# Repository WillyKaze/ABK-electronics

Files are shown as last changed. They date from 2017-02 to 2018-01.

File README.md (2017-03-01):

```
____ ___  _  _    ____ _    ____ ____ ___ ____ ____ _  _ _ ____ ____ 
|__| |__] |_/  __ |___ |    |___ |     |  |__/ |  | |\ | | |    [__  
|  | |__] | \_    |___ |___ |___ |___  |  |  \ |__| | \| | |___ ___] 
                                                                      
```

# Abrakabuki electronics

This repo contains all necessary files to design and produce PCBs for the Abrakabuki product range.

## File format and folder structure

Documentation files should be in PDF. Board image files can be in PNG or PDF.

PCB Design file are in EAGLE Standard edition (7.4) file format.

These are general rules to help maintain a consistent folder structure:

* All libraries are placed inside the shared libraries repository. It can be found
  on [Github](https://github.com/exmchina-dev/eagle-resources)  

* One board for each project folder.  

* Mutiples revisions can be placed inside a subfolder. i.e. ECS-Board/Rev A1  

* BOMs, partlists, spreadsheet should placed inside a BOMs/ folder.  

* Documentations files are in eagle-resources/doc or in doc/ inside a project folder.

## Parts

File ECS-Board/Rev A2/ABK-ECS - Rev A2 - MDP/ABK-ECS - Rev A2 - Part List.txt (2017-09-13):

Partlist

Exported from ABK-ECS - Rev A2.brd at 2017-09-08 3:27 PM

EAGLE Version 7.7.0 Copyright (c) 1988-2016 CadSoft

Assembly variant: 

Part     Value            Package             Library                                      Position (mm)         Orientation

C1       10uF             CT3216              rcl                                          (43.485 32.893)       MR0
C2       0.1uF            C0603               rcl                                          (47.422 30.861)       MR90
C3       0.1uF            C0603               rcl                                          (48.565 17.78)        R0
C4       0.1uF            C0603               rcl                                          (38.405 8.89)         MR0
C5       18pF             C0603               rcl                                          (41.58 17.78)         R270
C6       0.1uF            C0603               rcl                                          (39.7385 34.163)      MR270
C7       0.1uF            C0603               rcl                                          (46.533 37.592)       MR0
C8       0.1uF            C0603               rcl                                          (47.549 34.925)       MR270
C9       0.1uF            C0603               rcl                                          (39.802 37.338)       MR0
C10      18pF             C0603               rcl                                          (44.12 17.78)         R270
C11      0.1uF            C0603               rcl                                          (39.8655 29.464)      MR270
C12      2.2uF            C0603               rcl                                          (80.061 26.67)        R180
C13      2.2uF            C0603               rcl                                          (79.9975 8.89)        R180
C14      1000pF           C0603               rcl                                          (86.665 26.035)       R0
C15      1000pF           C0603               rcl                                          (86.665 7.62)         R0
C16      2.2uF            C0603               rcl                                          (79.299 39.37)        R180
C17      2.2uF            C0603               rcl                                          (79.172 21.082)       R180
C18      22uF             C0805               rcl                                          (77.775 29.21)        R0
C19      22uF             C0805               rcl                                          (77.775 11.43)        R0
C20      1u               C0603               rcl                                          (15.8875 12.3825)     R180
C21      1u               C0603               rcl                                          (11.4425 12.3825)     R0
C22      0.1uF            C0603               rcl                                          (91.745 53.34)        R0
C23      0.1uF            C0603               rcl                                          (18.745 50.8)         MR270
C24      0.1uF            C0603               rcl                                          (37.16 50.8)          MR270
D1       MBRS140          DO-214AA            diode                                        (78.41 36.195)        R0
D2       MBRS140          DO-214AA            diode                                        (78.41 17.78)         R0
D3       STPS3L40UF       SMB                 diode                                        (91.11 15.24)         R0
D4       STPS3L40UF       SMB                 diode                                        (9.525 23.495)        MR0
D5       STPS3L40UF       SMB                 diode                                        (88.9 68.5925)        MR270
D6       1N4148WS         SOD323-W            diode                                        (44.755 69.85)        MR270
D7       1N4148WS         SOD323-W            diode                                        (67.615 69.85)        MR270
D8       1N4148WS         SOD323-W            diode                                        (71.425 69.85)        MR270
D9       1N4148WS         SOD323-W            diode                                        (75.235 69.85)        MR270
D10      1N4148WS         SOD323-W            diode                                        (79.045 69.85)        MR270
D11      1N4148WS         SOD323-W            diode                                        (48.565 69.85)        MR270
D12      1N4148WS         SOD323-W            diode                                        (52.375 69.85)        MR270
D13      1N4148WS         SOD323-W            diode                                        (56.185 69.85)        MR270
D14      1N4148WS         SOD323-W            diode                                        (59.995 69.85)        MR270
F1       1812L110/24DR    LITTLEFUSE_SMD      fuse2                                        (91.745 25.4)         R270
J1       22-27-2061-06    6410-06             con-molex                                    (10.465 18.415)       R0
J2       USB-B-S-RA       USB-B-S-RA          con-multicomp                                (60.63 4.445)         R0
J3       1241050-5        2.54/2X5            con-amp                                      (25.705 9.525)        R0
J4       MSTBA2           MSTBA2              con-phoenix-508                              (98.095 40)           R90
J5       22-05-7068-06    7395-06             con-molex                                    (33.02 74.93)         R180
J6       22-05-7028-02    7395-02             con-molex                                    (88.9 74.93)          R180
J7       22-05-7068-06    7395-06             con-molex                                    (16.51 74.93)         R180
J8       22-05-7068-06    7395-06             con-molex                                    (76.2 74.93)          R180
J9       22-05-7028-02    7395-02             con-molex                                    (45.72 74.93)         R180
J10      22-05-7068-06    7395-06             con-molex                                    (58.42 74.93)         R180
JP1      FIDUCIAL1X2      FIDUCIAL-1X2        SparkFun                                     (92 8)                R90
JP2      FIDUCIAL1X2      FIDUCIAL-1X2        SparkFun                                     (8 8)                 R90
JP3      FIDUCIAL1X2      FIDUCIAL-1X2        SparkFun                                     (8 71.365)            R90
JP4      FIDUCIAL1X2      FIDUCIAL-1X2        SparkFun                                     (92 72)               R90
K1       G6K-2G-Y         G6K-2G-Y            relay                                        (88.57 62.23)         R270
L1       15uH             WE-PD2_5848/5820    Wurth-POWER_MAGNETICS-rev16f                 (72.06 31.115)        R270
L2       10uH             WE-PD2_5848/5820    Wurth-POWER_MAGNETICS-rev16f                 (72.06 13.0175)       R270
LED1     Blue             CHIPLED_0603        led                                          (50.47 7.62)          R180
LED2     Blue             CHIPLED_0603        led                                          (47.93 7.62)          R180
LED3     Red              CHIPLED_0603        led                                          (88.57 36.83)         R90
LED4     Blue             CHIPLED_0603        led                                          (88.57 39.6875)       R270
LED5     Blue             CHIPLED_0603        led                                          (76.378 25.7175)      R0
LED6     Blue             CHIPLED_0603        led                                          (76.378 8.128)        R0
LED7     Red              CHIPLED_0603        led                                          (93.65 55.245)        R270
LED8     Blue             CHIPLED_0603        led                                          (45.085 56.5275)      R90
LED9     Blue             CHIPLED_0603        led                                          (39.04 52.705)        R180
LED10    Blue             CHIPLED_0603        led                                          (37.135 52.705)       R180
LED11    Blue             CHIPLED_0603        led                                          (24.435 52.705)       R180
LED12    Blue             CHIPLED_0603        led                                          (22.53 52.705)        R180
LED13    Blue             CHIPLED_0603        led                                          (20.625 52.705)       R180
LED14    Blue             CHIPLED_0603        led                                          (18.72 52.705)        R180
LED15    Blue             CHIPLED_0603        led                                          (6.02 52.705)         R180
LED16    Blue             CHIPLED_0603        led                                          (4.1275 52.705)       R180
LED17    Blue             CHIPLED_0603        led                                          (80.315 50.165)       R180
LED18    Blue             CHIPLED_0603        led                                          (82.855 50.165)       R180
LED19    Blue             CHIPLED_0603        led                                          (85.395 50.165)       R180
LED20    Blue             CHIPLED_0603        led                                          (87.935 50.165)       R180
LED21    Blue             CHIPLED_0603        led                                          (45.0725 54.61)       R90
LED22    Blue             CHIPLED_0603        led                                          (45.0725 52.705)      R90
LED23    Blue             CHIPLED_0603        led                                          (45.0725 50.8)        R90
LED24    Blue             CHIPLED_0603        led                                          (45.0725 48.895)      R90
MP1      MOUNT-PAD3,0     P3,0                holes                                        (96 4)                R90
MP2      MOUNT-PAD3,0     P3,0                holes                                        (4 4)                 R90
MP3      MOUNT-PAD3,0     P3,0                holes                                        (4 76)                R90
MP4      MOUNT-PAD3,0     P3,0                holes                                        (96 76)               R90
OK1      TLP283-4         MINI-FLAT-16        optocoupler                                  (30.785 64.135)       R270
OK2      TLP283-4         MINI-FLAT-16        optocoupler                                  (14.275 64.135)       R270
OK3      TLP283-4         MINI-FLAT-16        optocoupler                                  (73.965 48.895)       R90
OK4      TLP283-4         MINI-FLAT-16        optocoupler                                  (56.185 48.895)       R90
R1       4K7              R0603               rcl                                          (39.37 11.7475)       R270
R2       4K7              R0603               rcl                                          (37.465 11.735)       R90
R3       4K7              R0603               rcl                                          (46.025 12.065)       R0
R4       4K7              R0603               rcl                                          (42.215 12.065)       R180
R5       0R               R0603               rcl                                          (20.32 32.385)        R270
R6       33               R0603               rcl                                          (60.63 14.605)        R90
R7       33               R0603               rcl                                          (58.344 14.605)       R90
R8       1K5              R0603               rcl                                          (63.805 13.6525)      R180
R9       1K5              R0603               rcl                                          (55.55 13.589)        R0
R10      10K              R0603               rcl                                          (16.815 41.91)        R0
R11      0R               R0603               rcl                                          (16.18 38.735)        R90
R12      0R               R0603               rcl                                          (18.72 38.735)        R90
R13      10K              R0603               rcl                                          (16.815 32.385)       R270
R14      1K5              R0603               rcl                                          (52.0825 7.62)        R90
R15      1K5              R0603               rcl                                          (46.3675 7.62)        R90
R16      31K6             R0603               rcl                                          (86.665 29.21)        R180
R17      31K6             R0603               rcl                                          (86.665 10.795)       R180
R18      4K7              R0603               rcl                                          (85.395 36.83)        R180
R19      4K7              R0603               rcl                                          (85.395 39.6875)      R180
R20      52K3             R0603               rcl                                          (82.855 23.495)       R180
R21      10K              R0603               rcl                                          (86.665 23.495)       R180
R22      31K6             R0603               rcl                                          (82.728 5.08)         R180
R23      10K              R0603               rcl                                          (86.665 5.08)         R180
R24      1K5              R0603               rcl                                          (78.537 24.003)       R0
R25      1K5              R0603               rcl                                          (78.6005 5.7785)      R0
R26      100              R0603               rcl                                          (88.57 68.58)         R180
R27      1K               R0603               rcl                                          (35.23 70.485)        R270
R28      1K               R0603               rcl                                          (32.69 70.485)        R270
R29      1K               R0603               rcl                                          (30.15 70.485)        R270
R30      1K               R0603               rcl                                          (27.61 70.485)        R270
R31      1K               R0603               rcl                                          (35.865 57.15)        R270
R32      1K               R0603               rcl                                          (32.055 57.15)        R270
R33      1K               R0603               rcl                                          (28.245 57.15)        R270
R34      1K               R0603               rcl                                          (24.435 57.15)        R270
R35      4K7              R0603               rcl                                          (33.96 57.15)         R90
R36      4K7              R0603               rcl                                          (30.15 57.15)         R90
R37      4K7              R0603               rcl                                          (26.34 57.15)         R90
R38      4K7              R0603               rcl                                          (22.53 57.15)         R90
R39      4K7              R0603               rcl                                          (94.92 52.07)         R90
R40      100              R0603               rcl                                          (91.745 50.8)         R180
R41      1K5              R0603               rcl                                          (90.475 55.245)       R180
R42      1K               R0603               rcl                                          (18.72 70.485)        R270
R43      1K               R0603               rcl                                          (16.18 70.485)        R270
R44      1K               R0603               rcl                                          (13.64 70.485)        R270
R45      1K               R0603               rcl                                          (11.1125 70.485)      R270
R46      1K               R0603               rcl                                          (19.355 57.15)        R270
R47      1K               R0603               rcl                                          (15.545 57.15)        R270
R48      1K               R0603               rcl                                          (11.735 57.15)        R270
R49      1K               R0603               rcl                                          (7.9375 57.15)        R270
R50      4K7              R0603               rcl                                          (17.45 57.15)         R90
R51      4K7              R0603               rcl                                          (13.64 57.15)         R90
R52      4K7              R0603               rcl                                          (9.83 57.15)          R90
R53      4K7              R0603               rcl                                          (6.0325 57.15)        R90
R54      1K5              R0603               rcl                                          (41.91 56.5275)       R180
R55      1K5              R0603               rcl                                          (39.04 49.53)         R270
R56      1K5              R0603               rcl                                          (37.135 49.53)        R270
R57      1K5              R0603               rcl                                          (24.435 49.53)        R270
R58      1K5              R0603               rcl                                          (22.53 49.53)         R270
R59      1K5              R0603               rcl                                          (20.625 49.53)        R270
R60      1K5              R0603               rcl                                          (18.72 49.53)         R270
R61      1K5              R0603               rcl                                          (6.02 49.53)          R270
R62      1K5              R0603               rcl                                          (4.1275 49.53)        R270
R63      10K              R0603               rcl                                          (46.66 70.485)        MR90
R64      330              R0603               rcl                                          (43.51 66.04)         R0
R65      100              R0603               rcl                                          (44.45 59.0675)       R270
R66      10K              R0603               rcl                                          (69.52 70.485)        MR90
R67      10K              R0603               rcl                                          (73.33 70.485)        MR90
R68      10K              R0603               rcl                                          (77.14 70.485)        MR90
R69      10K              R0603               rcl                                          (80.95 70.485)        MR90
R70      330              R0603               rcl                                          (67.9325 66.04)       R0
R71      330              R0603               rcl                                          (72.3775 66.04)       R0
R72      330              R0603               rcl                                          (76.8225 66.04)       R0
R73      330              R0603               rcl                                          (81.2675 66.04)       R0
R74      100              R0603               rcl                                          (69.52 59.055)        R90
R75      100              R0603               rcl                                          (74.2825 59.055)      R90
R76      100              R0603               rcl                                          (78.7275 59.055)      R90
R77      100              R0603               rcl                                          (82.855 59.055)       R90
R78      1K5              R0603               rcl                                          (80.315 46.99)        R270
R79      1K5              R0603               rcl                                          (82.855 46.99)        R270
R80      1K5              R0603               rcl                                          (85.395 46.99)        R270
R81      1K5              R0603               rcl                                          (87.935 46.99)        R270
R82      4K7              R0603               rcl                                          (67.615 59.055)       R90
R83      4K7              R0603               rcl                                          (72.3775 59.055)      R90
R84      4K7              R0603               rcl                                          (76.8225 59.055)      R90
R85      4K7              R0603               rcl                                          (80.95 59.055)        R90
R86      1K               R0603               rcl                                          (67.615 55.245)       R270
R87      1K               R0603               rcl                                          (72.3775 55.245)      R270
R88      1K               R0603               rcl                                          (76.8225 55.245)      R270
R89      1K               R0603               rcl                                          (80.95 55.245)        R270
R90      330              R0603               rcl                                          (63.4875 39.37)       R270
R91      330              R0603               rcl                                          (65.71 39.37)         R270
R92      330              R0603               rcl                                          (67.9325 39.37)       R270
R93      330              R0603               rcl                                          (70.155 39.37)        R270
R94      10K              R0603               rcl                                          (50.47 70.485)        MR90
R95      10K              R0603               rcl                                          (54.28 70.485)        MR90
R96      10K              R0603               rcl                                          (58.09 70.485)        MR90
R97      10K              R0603               rcl                                          (61.9 70.485)         MR90
R98      330              R0603               rcl                                          (47.93 66.04)         R0
R99      330              R0603               rcl                                          (52.375 66.04)        R0
R100     330              R0603               rcl                                          (56.82 66.04)         R0
R101     330              R0603               rcl                                          (61.265 66.04)        R0
R102     100              R0603               rcl                                          (48.9075 59.055)      R90
R103     100              R0603               rcl                                          (53.3525 59.055)      R90
R104     100              R0603               rcl                                          (57.7975 59.055)      R90
R105     100              R0603               rcl                                          (62.2425 59.055)      R90
R106     1K5              R0603               rcl                                          (41.8975 54.61)       R180
R107     1K5              R0603               rcl                                          (41.8975 52.705)      R180
R108     1K5              R0603               rcl                                          (41.8975 50.8)        R180
R109     1K5              R0603               rcl                                          (41.8975 48.895)      R180
R110     4K7              R0603               rcl                                          (47.0025 59.055)      R90
R111     4K7              R0603               rcl                                          (51.4475 59.055)      R90
R112     4K7              R0603               rcl                                          (55.8925 59.055)      R90
R113     4K7              R0603               rcl                                          (60.3375 59.055)      R90
R114     1K               R0603               rcl                                          (53.01 55.245)        R270
R115     1K               R0603               rcl                                          (55.55 55.245)        R270
R116     1K               R0603               rcl                                          (58.09 55.245)        R270
R117     1K               R0603               rcl                                          (60.63 55.245)        R270
R118     330              R0603               rcl                                          (54.5975 39.37)       R270
R119     330              R0603               rcl                                          (56.82 39.37)         R270
R120     330              R0603               rcl                                          (59.0425 39.37)       R270
R121     330              R0603               rcl                                          (61.265 39.37)        R270
SJ1      SOLDERJUMPERNC   SJ_2S               SparkFun-Passives                            (60.63 4.445)         MR90
SJ2      SOLDERJUMPERNC   SJ_2S               SparkFun-Passives                            (96 10)               R270
SJ3      SOLDERJUMPERNC   SJ_2S               SparkFun-Passives                            (4 10)                R270
SJ4      SOLDERJUMPERNC   SJ_2S               SparkFun-Passives                            (4 69.365)            R90
SJ5      SOLDERJUMPERNC   SJ_2S               SparkFun-Passives                            (95.999 70.081)       R90
SW1      B3FS-1015        B3FS                Switch_SMT                                   (9.52 40.155)         R0
SW2      B3FS-1015        B3FS                Switch_SMT                                   (9.52 30.955)         R0
T2       IRLML5103TRPBF   SOT95P240X112-3N    International_Rectifier_By_element14_Batch_1 (43.485 69.215)       R90
T3       MMBT2222AL       SOT?23              transistor                                   (43.4975 63.4875)     R270
T4       IRLML5103TRPBF   SOT95P240X112-3N    International_Rectifier_By_element14_Batch_1 (68.25 69.215)        R90
T5       IRLML5103TRPBF   SOT95P240X112-3N    International_Rectifier_By_element14_Batch_1 (72.695 69.215)       R90
T6       IRLML5103TRPBF   SOT95P240X112-3N    International_Rectifier_By_element14_Batch_1 (77.14 69.215)        R90
T7       IRLML5103TRPBF   SOT95P240X112-3N    International_Rectifier_By_element14_Batch_1 (81.585 69.215)       R90
T8       MMBT2222AL       SOT?23              transistor                                   (68.25 63.5)          R270
T9       MMBT2222AL       SOT?23              transistor                                   (72.695 63.5)         R270
T10      MMBT2222AL       SOT?23              transistor                                   (77.14 63.5)          R270
T11      MMBT2222AL       SOT?23              transistor                                   (81.585 63.5)         R270
T12      IRLML5103TRPBF   SOT95P240X112-3N    International_Rectifier_By_element14_Batch_1 (47.93 69.215)        R90
T13      IRLML5103TRPBF   SOT95P240X112-3N    International_Rectifier_By_element14_Batch_1 (52.375 69.215)       R90
T14      IRLML5103TRPBF   SOT95P240X112-3N    International_Rectifier_By_element14_Batch_1 (56.82 69.215)        R90
T15      IRLML5103TRPBF   SOT95P240X112-3N    International_Rectifier_By_element14_Batch_1 (61.265 69.215)       R90
T16      MMBT2222AL       SOT?23              transistor                                   (47.93 63.5)          R270
T17      MMBT2222AL       SOT?23              transistor                                   (52.375 63.5)         R270
T18      MMBT2222AL       SOT?23              transistor                                   (56.82 63.5)          R270
T19      MMBT2222AL       SOT?23              transistor                                   (61.265 63.5)         R270
U1       AT24C512C-SSHM-B SOIC127P600X175-8N  atmel                                        (38.405 6.985)        R0
U2       LPC1768FBD100    SOT407-1            NXP                                          (43.73 33.65)         R90
U3       LT3686HDDPBF     DFN300X300X80-11N   lineartechnology                             (82.855 31.115)       R90
U4       LT3686HDDPBF     DFN300X300X80-11N   lineartechnology                             (82.855 12.7)         R90
U5       TC1264-3.3       SOT230P700X180-4N   microchip-6                                  (13.64 6.985)         R270
U6       CD4050BD         SOIC127P600X175-16N ti                                           (30.7975 50.8)        R270
U7       CD4050BD         SOIC127P600X175-16N ti                                           (12.3825 50.8)        R270
X1       FC-135           FC-135              crystal                                      (42.85 20.955)        R0
X2       ASE-12           ASE                 crystal                                      (48.565 20.955)       R0
X3       3000             3000                keystone                                     (25.705 6.35)         MR180

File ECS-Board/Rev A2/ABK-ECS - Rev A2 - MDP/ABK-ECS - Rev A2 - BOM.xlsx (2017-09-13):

Qty | Designator | Value | Package | Manufacteur | Reference Manufacteur | Mounting Tecghnologie
1 | U5 | TC1264-3.3V | SOT230P700X180-4N | MICROCHIP | TC1264-3.3VDB | SMD
1 | J3 | 1241050-5 | 2.54/2X5 | AMP | 1241050-5 | Thought-Hole
1 | J4 | MSTBA2 | MSTBA2 | PHOENIX CONTACT | 1757242 | Thought-Hole
9 | D6, D7, D8, D9, D10, D11, D12, D13, D14 | 1N4148WS | SOD323-W | ON SEMICONDUCTOR | 1N4148WS | SMD
2 | J6, J9 | 22-05-7028-02 | 7395-02 | MOLEX | 22-05-7028 | Thought-Hole
4 | J5, J7, J8, J10 | 22-05-7068-06 | 7395-06 | MOLEX | 22-05-7068 | Thought-Hole
1 | J1 | 22-27-2061-06 | 6410-06 | MOLEX | 22-27-2061 | Thought-Hole
1 | X3 | 3000 | 3000 | KEYSTONE | 3000 | SMD
1 | F1 | 1812L110/24DR | LITTLEFUSE_SMD | LITTLEFUSE | 1812L110/24DR | SMD
1 | L2 | 10uH | WE-PD2_5848/5820 | WURTH ELECTRONIK | 74477410 | SMD
1 | L1 | 15uH | WE-PD2_5848/5820 | WURTH ELECTRONIK | 744774115 | SMD
1 | X2 | ASE-12 | ASE | ABRACON | ASE-12.000MHZ-LC-T | SMD
1 | U1 | AT24C512C-SSHM-B | SOIC127P600X175-8N | MICROCHIP | AT24C512C-SSHM-B | SMD
2 | SW1, SW2 | B3FS-1015 | B3FS | OMRON ELECTRONIC | B3FS-1010 | SMD
2 | C18, C19 | 22uF | C0805 | KEMET | C0805C226M9PACTU | SMD
2 | U6, U7 | CD4050BD | SOIC127P600X175-16N | TEXAS INSTRUMENT | CD4050BD | SMD
1 | C1 | 10uF | CT3216 | AVX | F931A106MAA | SMD
1 | K1 | G6K-2G-Y | G6K-2G-Y | OMRON ELECTRONIC | G6K-2G-Y 24DC | SMD
2 | C5, C10 | 18pF | C0603 | MURATA | GRM1885C1H180JA01D | SMD
2 | C20, C21 | 1u | C0603 | MURATA | GRM188R61C105KA93D | SMD
2 | C14, C15 | 1000pF | C0603 | MURATA | GRM188R71H102KA01D | SMD
4 | C12, C13, C16, C17 | 2.2uF | C0603 | MURATA | GRT188R61H225KE13D | SMD
9 | T2, T4, T5, T6, T7, T12, T13, T14, T15 | IRLML5103TRPBF | SOT95P240X112-3N | INFENEON | IRLML5103TRPBF | SMD
1 | U2 | LPC1768FBD100 | SOT407-1 | NXP | LPC1768FBD100 | SMD
2 | U3, U4 | LT3686HDDPBF | DFN300X300X80-11N | LINEAR TECHNOLOGY | LT3686HDD#PBF | SMD
2 | D1, D2 | MBRS140 | DO-214AA | ON SEMICONDUCTOR | MBRS140T3G | SMD
1 | R20 | 52K3 | R0603 | MULTICOMP | MC0063W0603152K3 | SMD
11 | C2, C3, C4, C6, C7, C8, C9, C11, C22, C23, C24 | 0.1uF | C0603 | MULTICOMP | MC0603B104K160CT | SMD
3 | R16, R17, R22 | 31K6 | R0603 | MULTICOMP | MCMR06X3162FTL | SMD
9 | T3, T8, T9, T10, T11, T16, T17, T18, T19 | MMBT2222AL | SOT-23 | ON SEMICONDUCTOR | MMBT2222ALT1G | SMD
22 | LED1, LED2, LED4, LED5, LED6, LED8, LED9, LED10, LED11, LED12, LED13, LED14, LED15, LED16, LED17, LED18, LED19, LED20, LED21, LED22, LED23, LED24 | Blue | CHIPLED_0603 | MULTICOMP | OVS-0603 | SMD
2 | LED3, LED7 | Red | CHIPLED_0603 | MULTICOMP | OVS-0603 | SMD
1 | X1 | FC-135 | FC-135 | EPSON | Q13FC13500004 | SMD
3 | R5, R11, R12 | 0R | R0603 | YAGEO | RC0603FR-070RL | SMD
11 | R10, R13, R63, R66, R67, R68, R69, R94, R95, R96, R97 | 10K | R0603 | YAGEO | RC0603FR-0710KL | SMD
2 | R21, R23 | 10K | R0603 | YAGEO | RC0603FR-0710KL | SMD
20 | R14, R15, R41, R54, R55, R56, R57, R58, R59, R60, R61, R62, R78, R79, R80, R81, R106, R107, R108, R109 | 1K5 | R0603 | YAGEO | RC0603FR-071K5L | SMD
2 | R24, R25 | 1K5 | R0603 | YAGEO | RC0603FR-071K5L | SMD
2 | R8, R9 | 1K5, DNI | R0603 | YAGEO | RC0603FR-071K5L
24 | R27, R28, R29, R30, R31, R32, R33, R34, R42, R43, R44, R45, R46, R47, R48, R49, R86, R87, R88, R89, R114, R115, R116, R117 | 1K | R0603 | YAGEO | RC0603FR-071KL | SMD
17 | R64, R70, R71, R72, R73, R90, R91, R92, R93, R98, R99, R100, R101, R118, R119, R120, R121 | 330 | R0603 | YAGEO | RC0603FR-07330RL | SMD
2 | R6, R7 | 33 | R0603 | YAGEO | RC0603FR-0733RL | SMD
1 | R1 | 4K7, DNI | R0603 | YAGEO | RC0603FR-074K7L
22 | R2, R3, R4, R18, R19, R35, R36, R37, R38, R39, R50, R51, R52, R53, R82, R83, R84, R85, R110, R111, R112, R113 | 4K7 | R0603 | YAGEO | RC0603FR-074K7L | SMD
11 | R26, R40, R65, R74, R75, R76, R77, R102, R103, R104, R105 | 100 | R0603 | YAGEO | RC0603FR-13100RL | SMD
3 | D3, D4, D5 | STPS3L40UF | SMB | STELECTRONICS | STPS3L40UF | SMD
4 | OK1, OK2, OK3, OK4 | TLP283-4 | MINI-FLAT-16 | VISHAY | TCMT4100 | SMD
1 | J2 | USB-B-S-RA | USB-B-S-RA | MULTICOMP | USB-B-S-RA | Thought-Hole

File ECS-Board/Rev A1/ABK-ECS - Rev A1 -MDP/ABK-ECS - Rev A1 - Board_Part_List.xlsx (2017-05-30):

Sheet: PdG
Project | WDY - Main Board
Board Name | MCU Board
Document | Part List
Author | AB
Date | 2017-03-20
Rev | A1

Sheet: BOM
Qty | Value | Package | Parts | Description | MPN
1 | 10uF | CT3216 | C1 | POLARIZED CAPACITOR, European symbol | F931A106MAA
4 | 2.2uF | C0603 | C13, C15, C17, C18 | CAPACITOR, European symbol | GRT188R61H225KE13D
2 | 1000pF | C0603 | C14, C16 | CAPACITOR, European symbol | MC0603B102K500CT
2 | 22uF | C0805 | C19, C20 | CAPACITOR, European symbol | MC0805X226M6R3CT
10 | 0.1uF | C0603 | C2, C3, C4, C6, C7, C8, C11, C12, C21, C22 | CAPACITOR, European symbol | MC0603B104K160CT
2 | 18pF | C0603 | C5, C10 | CAPACITOR, European symbol | MC0603N180K500CT
2 | STPS3L40UF | SMB | D1, D4 |  | STPS3L40UF
2 | MBRS140 | DO-214AA | D2, D3 | Redresseur Schottky, 40 V, 1 A, Une, DO-214AA, 2 Broche(s), 600 mV | MBRS140T3G
1 | FUSE3557L | 3557-LITTLE | F1 | Fuse | 3557
1 | 1241050-5 | 2.54/2X5 | J1 |  | 1241050-5
1 | USB-B-S-RA | USB-B-S-RA | J2 | MULTICOMP USB-B-S-RA USB Connector, USB Type B, USB 2.0, Receptacle, 4 Positions, Through Hole Mount, Right Angle | USB-B-S-RA
1 | 22-27-2061-06 | 1647397 | J3 | CONNECTOR | 22-27-2061
2 | 22-05-7068-06 | 2007161 | J4, J7 | CONNECTOR | 22-05-7068
2 | 22-05-7028-02 | 2007041 | J5, J6 | CONNECTOR | 22-05-7028
1 | G6K-2G-Y | G6K-2G-Y | K3 | Low Signal Relay | G6K-2G-Y 24DC
1 | 10uH | WE-PD2_5848/5820 | L2 | SMD Power Inductor | 74477410
1 | 15uH | WE-PD2_5848/5820 | L3 | SMD Power Inductor | 744774115
14 | Blue | CHIPLED_0603 | LED1, LED3, LED4, LED8, LED9, LED10, LED11, LED12, LED13, LED14, LED15, LED16 | LED | OVS-0603
2 | Red | CHIPLED_0603 | LED2, LED7 | LED | OVS-0608
2 | TLP283-4 | MINI-FLAT-16 | OK1, OK2 | TOSHIBA PHOTOCOUPLER GaAs IRED & PHOTO-TRANSISTOR | TCMT4100
19 | 4K7 | R0603 | R1, R2, R3, R4, R5, R18, R26, R28, R33, R34, R35, R40, R44, R46, R58, R60, R62, R64, R65 | RESISTOR, European symbol | MCMR06X4701FTL
15 | 1K5 | R0603 | R10, R13, R14, R31, R66, R67, R68, R69, R70, R71, R72, R73, R74 | RESISTOR, European symbol | MCMR06X1501FTL
2 | 33 | R0603 | R11, R12 | RESISTOR, European symbol | MCMR06X33R0FTL
12 | 100 | R0603 | R17, R25, R27, R29, R32, R36, R37, R39, R42, R43, R45, R48 | RESISTOR, European symbol | MCMR06X1000FTL
3 | 31K6 | R0603 | R19, R20, R24 | RESISTOR, European symbol | MCMR06X3162FTL
2 | 10K | R0603 | R21, R23 | RESISTOR, European symbol | MCMR06X1002FTL
1 | 52K3 | R0603 | R22 | RESISTOR, European symbol | MC0063W0603152K3
12 | 1K | R0603 | R30, R38, R41, R47, R53, R54, R55, R56, R57, R59, R61, R63 | RESISTOR, European symbol | MCMR06X1001FTL
4 | 330 | R0603 | R49, R50, R51, R52 | RESISTOR, European symbol | MCMR06X3300FTL
2 | 10K | R0603 | R6, R7 | RESISTOR, European symbol | MCMR06X1002FTL
2 | 0R | R0603 | R8, R9 | RESISTOR, European symbol | MCMR06X000 PTL
2 | B3FS-1015 | B3FS | SW1, SW2 | Surface-mounting Switches Ideal for | B3FS-1010
1 | AT24C512C-SSHM-B | SOIC127P600X175-8N | U1 | SERIAL EEPROM IC Memory Size:512Kbit,8-SOIC | AT24C02C-SSHM-B
1 | CD4050BD | SOIC127P600X175-16N | U10 | CMOS Hex Buffer/Converters | CD4050BD
1 | LPC1768FBD100 | SOT407-1 | U2 |  | LPC1768FBD100
2 | LT3686HDDPBF | DFN300X300X80-11N | U3, U4 | 37V/1.2A Step-DownRegulator in 3mm ﾗ 3mm DFN | LT3686HDD#PBF
5 | IRLML6344TRPBF | SOT95P240X112-3N | U5, U6, U7, U8, U9 | Power MOSFET | IRLML6344TRPBF
1 | FC-135 | FC-135 | X1 | 32.768kHz ｱ20ppm Crystal 12.5pF 70 kOhm -40ｰC ~ 85ｰC Surface Mount 2-SMD | Q13FC13500004
1 | ASE-12 | ASE | X2 | 3.3Vdc CMOS SMD CRYSTAL CLOCK OSCILLATOR | ASE-12.000MHZ-LC-T
1 | 3000 | 3000 | X3 |  | 3000
1 | MSTBA2 | MSTBA2 | X4 | PHOENIX | 1757242

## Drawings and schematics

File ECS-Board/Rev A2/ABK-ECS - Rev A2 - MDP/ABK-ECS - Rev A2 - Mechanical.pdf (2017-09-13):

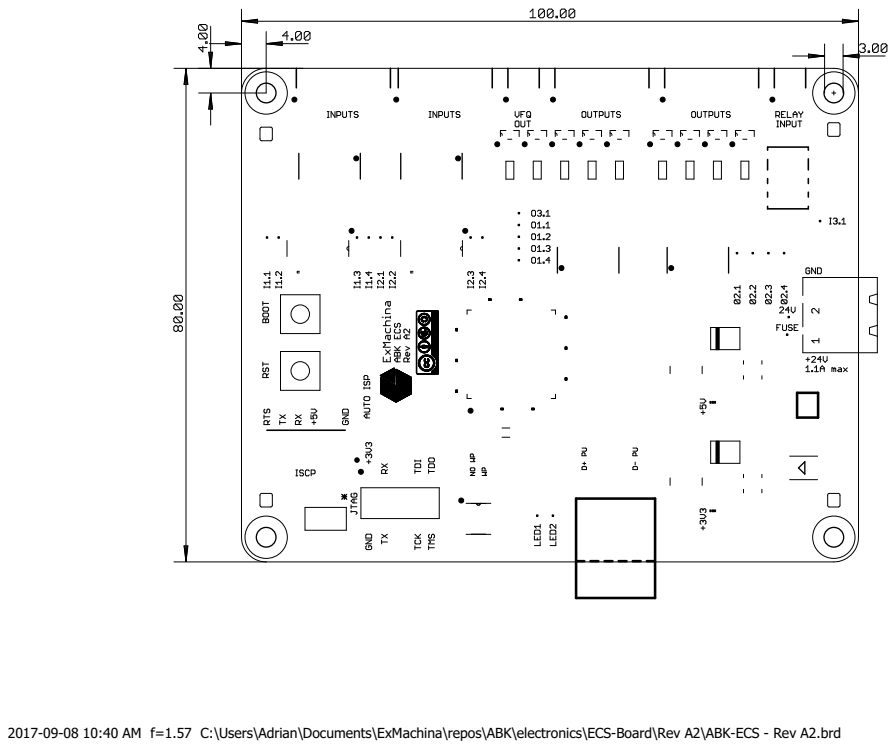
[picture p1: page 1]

2017-09-08 10:40 AM f=1.57 C:\Users\Adrian\Documents\ExMachina\repos\ABK\electronics\ECS-Board\Rev A2\ABK-ECS - Rev A2.brd

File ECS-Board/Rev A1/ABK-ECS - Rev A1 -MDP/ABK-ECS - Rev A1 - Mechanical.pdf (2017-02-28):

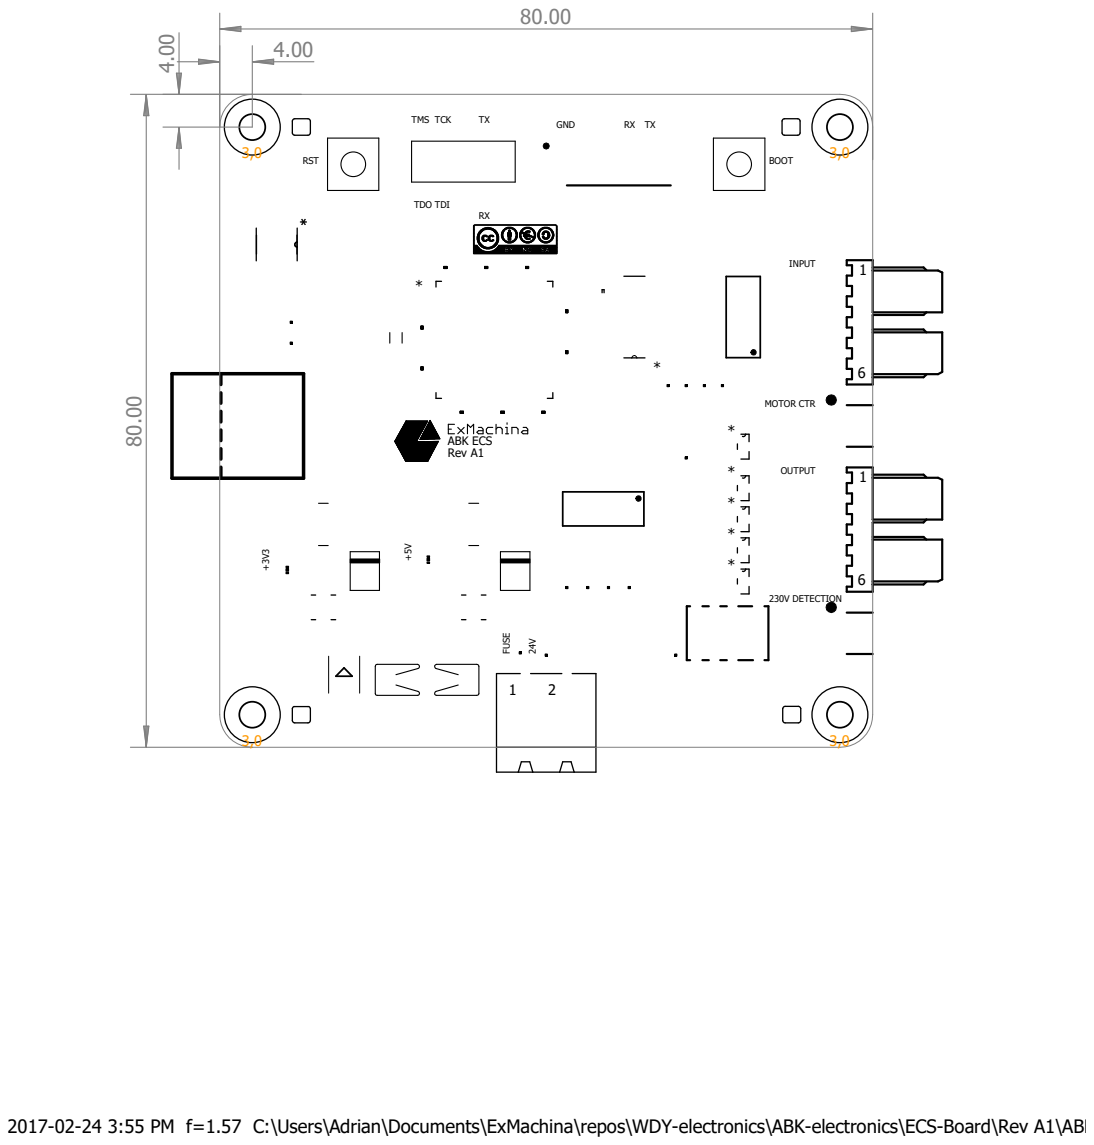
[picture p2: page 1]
ABK ECS Rev A1; TDO TDI TMS TCK; TXRX; GND; RX TX RST; BOOT MOTOR CTR; 230V DETECTION OUTPUT; INPUT FUSE

2017-02-24 3:55 PM f=1.57 C:\Users\Adrian\Documents\ExMachina\repos\WDY-electronics\ABK-electronics\ECS-Board\Rev A1\ABK-ECS - Rev A1.brd

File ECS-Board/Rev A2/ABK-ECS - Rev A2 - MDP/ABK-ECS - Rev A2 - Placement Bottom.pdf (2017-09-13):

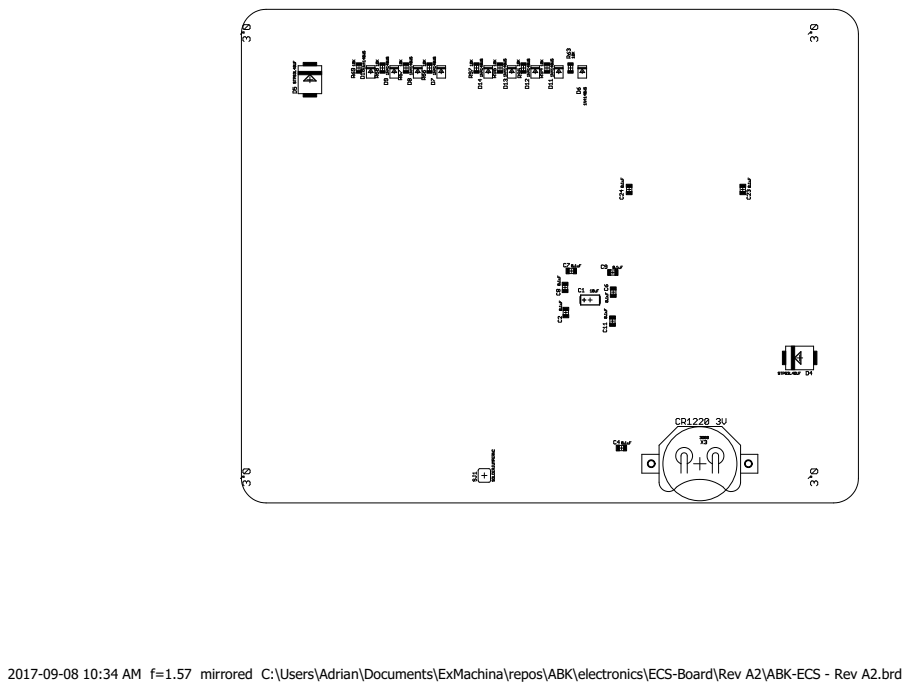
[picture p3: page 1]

2017-09-08 10:34 AM f=1.57 mirrored C:\Users\Adrian\Documents\ExMachina\repos\ABK\electronics\ECS-Board\Rev A2\ABK-ECS - Rev A2.brd

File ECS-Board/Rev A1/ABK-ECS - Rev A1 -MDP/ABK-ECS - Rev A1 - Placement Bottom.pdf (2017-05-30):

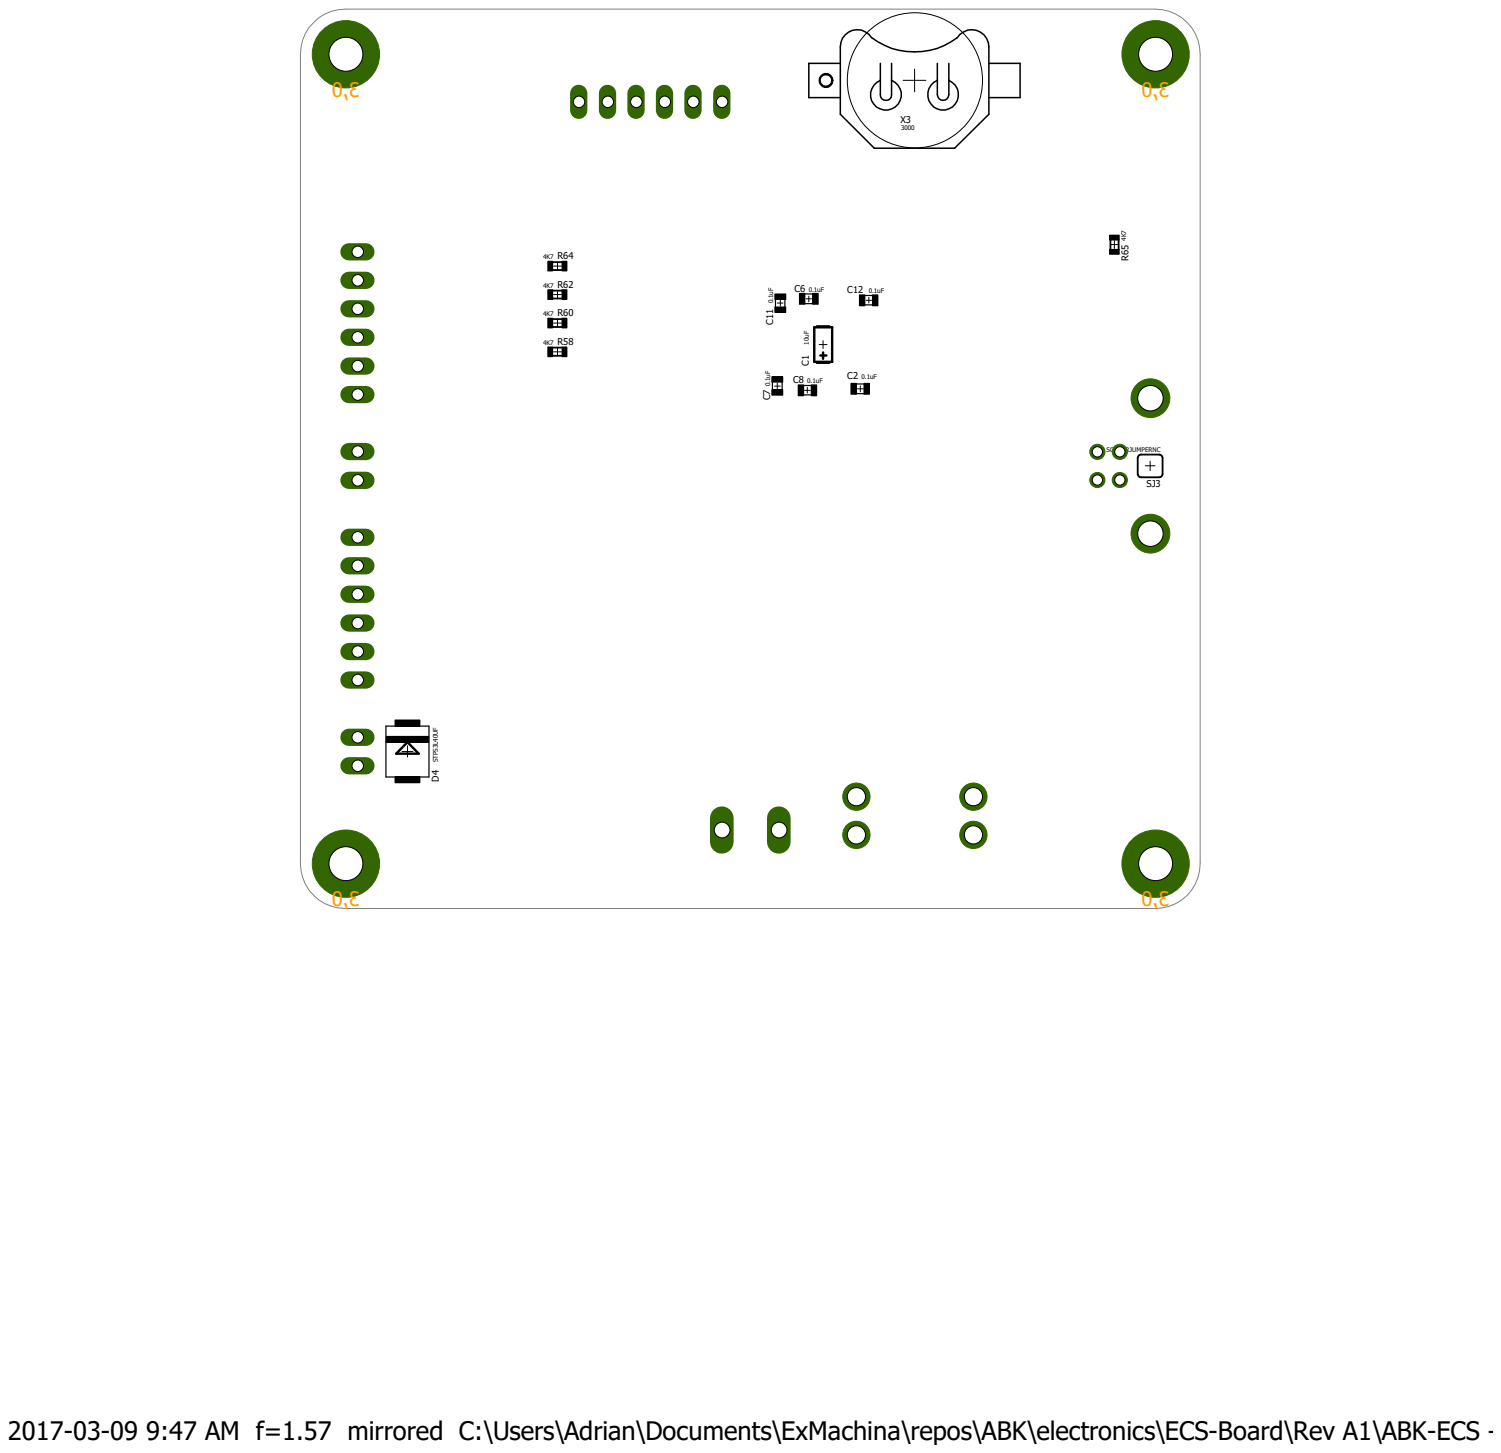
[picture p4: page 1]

2017-03-09 9:47 AM f=1.57 mirrored C:\Users\Adrian\Documents\ExMachina\repos\ABK\electronics\ECS-Board\Rev A1\ABK-ECS - Rev A1.brd

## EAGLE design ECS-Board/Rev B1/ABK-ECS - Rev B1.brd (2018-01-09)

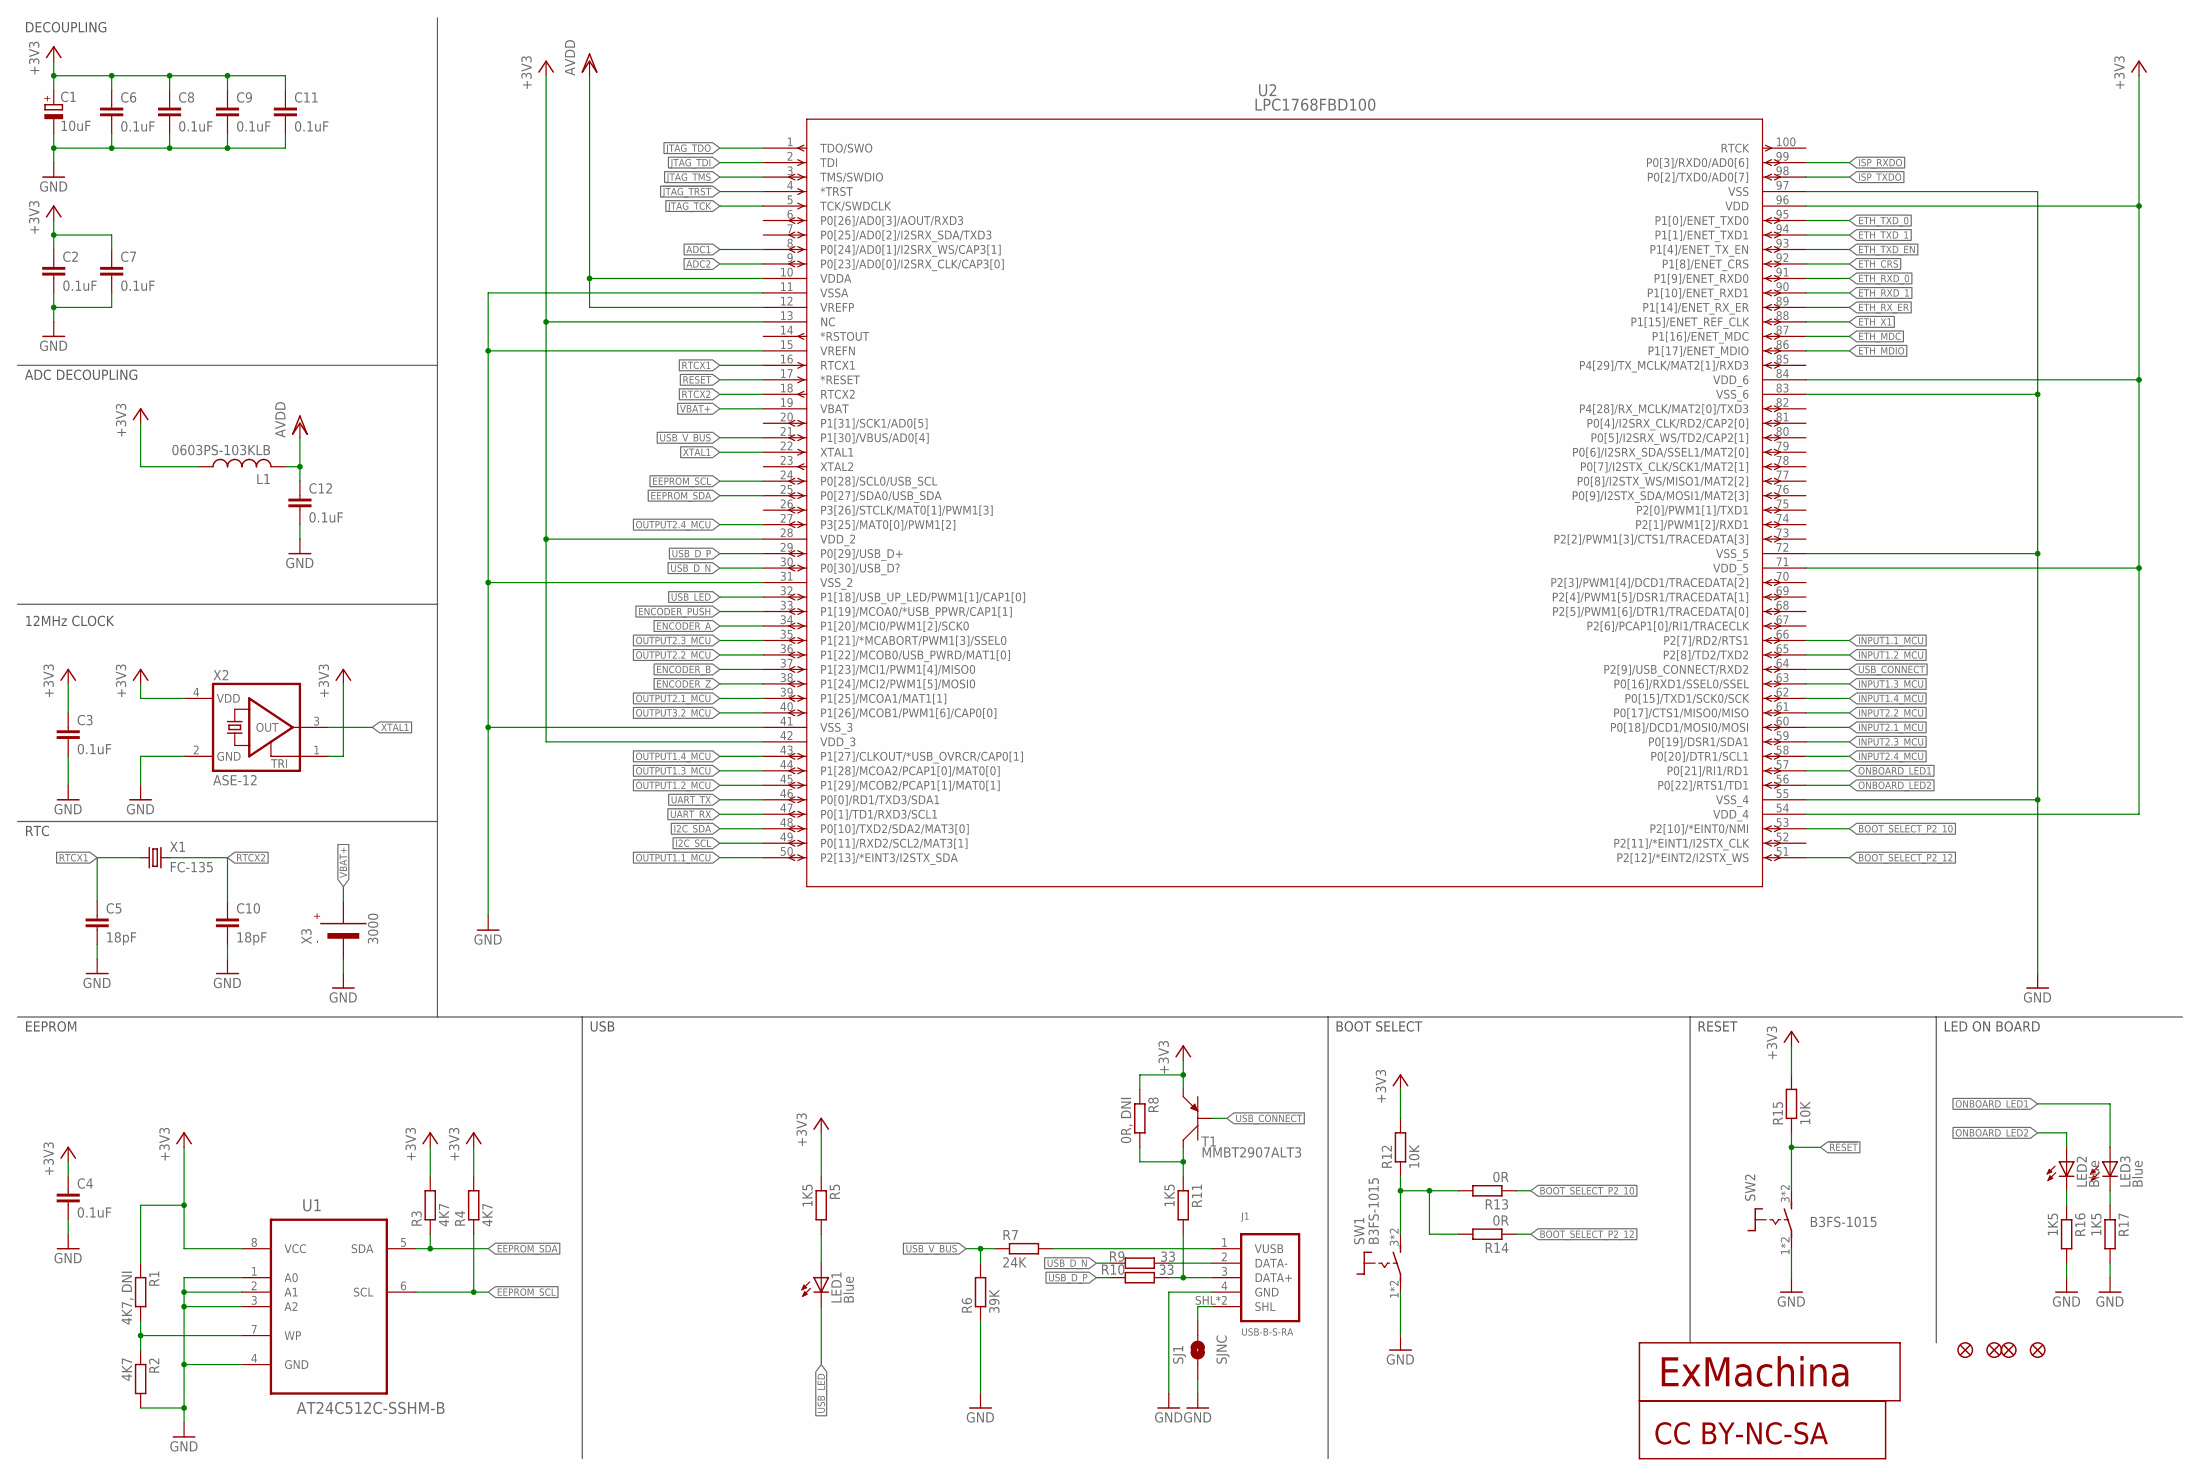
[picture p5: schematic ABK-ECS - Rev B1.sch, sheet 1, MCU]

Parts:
C1: 10uF; CT3216; MPN F931A106MAA
C2, C3, C4, C6, C7, C8, C9, C11, C12: 0.1uF; C0603; MPN MC0603B104K160CT
C5, C10: 18pF; C0603; MPN GRM1885C1H180JA01D
CC1: CC-BY-NC-SA
J1: USB-B-S-RA; MPN USB-B-S-RA
JP1, JP2, JP3, JP4: FIDUCIAL1X2; FIDUCIAL-1X2
L1: 0603PS-103KLB; 0603
LED1, LED2, LED3: Blue; CHIPLED_0603; MPN OVS-0603
R1: 4K7, DNI; R0603; MPN RC0603FR-074K7L
R2, R3, R4: 4K7; R0603; MPN RC0603FR-074K7L
R5, R11, R16, R17: 1K5; R0603; MPN RC0603FR-071K5L
R6: 39K; R0603
R7: 24K; R0603
R8: 0R, DNI; R0603; MPN RC0603FR-070RL
R9, R10: 33; R0603; MPN RC0603FR-0733RL
R12, R15: 10K; R0603; MPN RC0603FR-0710KL
R13, R14: 0R; R0603; MPN RC0603FR-070RL
SJ1: SJNC; SJ_2S
SW1, SW2: B3FS-1015; B3FS; MPN B3FS-1010
T1: MMBT2907ALT3; SOT−23
T2: EXMACHINA-LOGO-NAME; EXM-LOGO-BASELINE
U1: AT24C512C-SSHM-B; SOIC127P600X175-8N; MPN AT24C512C-SSHM-B
U2: LPC1768FBD100; SOT407-1; MPN LPC1768FBD100
X1: FC-135; MPN Q13FC13500004
X2: ASE-12; ASE; MPN ASE-12.000MHZ-LC-T
X3: 3000; MPN 3000

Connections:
!JTAG_TRST: U2.4 (*TRST)
!RESET: R15.1, SW2.3 (1), SW2.4 (1), U2.17 (*RESET); also elsewhere on the board
+3V3: C1.+, C2.1, C3.1, C4.1, C6.1, C7.1, C8.1, C9.1, C11.1, L1.P$1 (1), R1.1, R3.2, R4.2, R5.1, R8.1, R12.2, R15.2, T1.3 (C), U1.8 (VCC), U2.13 (NC), U2.28 (VDD_2), U2.42 (VDD_3), U2.54 (VDD_4), U2.71 (VDD_5), U2.84 (VDD_6), U2.96 (VDD), X2.1 (TRI), X2.4 (VDD); also elsewhere on the board
ADC1: U2.8 (P0[24]/AD0[1]/I2SRX_WS/CAP3[1]); also elsewhere on the board
ADC2: U2.9 (P0[23]/AD0[0]/I2SRX_CLK/CAP3[0]); also elsewhere on the board
AVDD: C12.1, L1.P$2 (2), U2.10 (VDDA), U2.12 (VREFP); also elsewhere on the board
BOOT_SELECT_P2_10: R13.1, U2.53 (P2[10]/*EINT0/NMI); also elsewhere on the board
BOOT_SELECT_P2_12: R14.1, U2.51 (P2[12]/*EINT2/I2STX_WS)
EEPROM_SCL: R4.1, U1.6 (SCL), U2.24 (P0[28]/SCL0/USB_SCL)
EEPROM_SDA: R3.1, U1.5 (SDA), U2.25 (P0[27]/SDA0/USB_SDA)
ENCODER_A: U2.34 (P1[20]/MCI0/PWM1[2]/SCK0); also elsewhere on the board
ENCODER_B: U2.37 (P1[23]/MCI1/PWM1[4]/MISO0); also elsewhere on the board
ENCODER_PUSH: U2.33 (P1[19]/MCOA0/*USB_PPWR/CAP1[1]); also elsewhere on the board
ENCODER_Z: U2.38 (P1[24]/MCI2/PWM1[5]/MOSI0); also elsewhere on the board
ETH_CRS: U2.92 (P1[8]/ENET_CRS); also elsewhere on the board
ETH_MDC: U2.87 (P1[16]/ENET_MDC); also elsewhere on the board
ETH_MDIO: U2.86 (P1[17]/ENET_MDIO); also elsewhere on the board
ETH_RXD_0: U2.91 (P1[9]/ENET_RXD0); also elsewhere on the board
ETH_RXD_1: U2.90 (P1[10]/ENET_RXD1); also elsewhere on the board
ETH_RX_ER: U2.89 (P1[14]/ENET_RX_ER); also elsewhere on the board
ETH_TXD_0: U2.95 (P1[0]/ENET_TXD0); also elsewhere on the board
ETH_TXD_1: U2.94 (P1[1]/ENET_TXD1); also elsewhere on the board
ETH_TXD_EN: U2.93 (P1[4]/ENET_TX_EN); also elsewhere on the board
ETH_X1: U2.88 (P1[15]/ENET_REF_CLK); also elsewhere on the board
GND: C1.-, C2.2, C3.2, C4.2, C5.2, C6.2, C7.2, C8.2, C9.2, C10.2, C11.2, C12.2, J1.4 (GND), R2.2, R6.1, R16.2, R17.2, SJ1.1, SW1.1 (2), SW1.2, SW2.1 (2), SW2.2, U1.1 (A0), U1.2 (A1), U1.3 (A2), U1.4 (GND), U2.11 (VSSA), U2.15 (VREFN), U2.31 (VSS_2), U2.41 (VSS_3), U2.55 (VSS_4), U2.72 (VSS_5), U2.83 (VSS_6), U2.97 (VSS), X2.2 (GND), X3.- (VBAT-); also elsewhere on the board
I2C_SCL: U2.49 (P0[11]/RXD2/SCL2/MAT3[1]); also elsewhere on the board
I2C_SDA: U2.48 (P0[10]/TXD2/SDA2/MAT3[0]); also elsewhere on the board
INPUT1.1_MCU: U2.66 (P2[7]/RD2/RTS1); also elsewhere on the board
INPUT1.2_MCU: U2.65 (P2[8]/TD2/TXD2); also elsewhere on the board
INPUT1.3_MCU: U2.63 (P0[16]/RXD1/SSEL0/SSEL); also elsewhere on the board
INPUT1.4_MCU: U2.62 (P0[15]/TXD1/SCK0/SCK); also elsewhere on the board
INPUT2.1_MCU: U2.60 (P0[18]/DCD1/MOSI0/MOSI); also elsewhere on the board
INPUT2.2_MCU: U2.61 (P0[17]/CTS1/MISO0/MISO); also elsewhere on the board
INPUT2.3_MCU: U2.59 (P0[19]/DSR1/SDA1); also elsewhere on the board
INPUT2.4_MCU: U2.58 (P0[20]/DTR1/SCL1); also elsewhere on the board
ISP_RXDO: U2.99 (P0[3]/RXD0/AD0[6]); also elsewhere on the board
ISP_TXDO: U2.98 (P0[2]/TXD0/AD0[7]); also elsewhere on the board
JTAG_TCK: U2.5 (TCK/SWDCLK); also elsewhere on the board
JTAG_TDI: U2.2 (TDI); also elsewhere on the board
JTAG_TDO: U2.1 (TDO/SWO); also elsewhere on the board
JTAG_TMS: U2.3 (TMS/SWDIO); also elsewhere on the board
unnamed: J1.3 (DATA+), R10.1, R11.2
unnamed: J1.2 (DATA-), R9.1
unnamed: LED3.C, R17.1
unnamed: R12.1, R13.2, R14.2, SW1.3 (1), SW1.4 (1)
unnamed: R1.2, R2.1, U1.7 (WP)
unnamed: LED1.A, R5.2
unnamed: LED2.C, R16.1
unnamed: R8.2, R11.1, T1.2 (E)
unnamed: J1.SHL, J1.SHL1 (SHL), SJ1.2
unnamed: J1.1 (VUSB), R7.2
ONBOARD_LED1: LED3.A, U2.57 (P0[21]/RI1/RD1)
ONBOARD_LED2: LED2.A, U2.56 (P0[22]/RTS1/TD1)
OUTPUT1.1_MCU: U2.50 (P2[13]/*EINT3/I2STX_SDA); also elsewhere on the board
OUTPUT1.2_MCU: U2.45 (P1[29]/MCOB2/PCAP1[1]/MAT0[1]); also elsewhere on the board
OUTPUT1.3_MCU: U2.44 (P1[28]/MCOA2/PCAP1[0]/MAT0[0]); also elsewhere on the board
OUTPUT1.4_MCU: U2.43 (P1[27]/CLKOUT/*USB_OVRCR/CAP0[1]); also elsewhere on the board
OUTPUT2.1_MCU: U2.39 (P1[25]/MCOA1/MAT1[1]); also elsewhere on the board
OUTPUT2.2_MCU: U2.36 (P1[22]/MCOB0/USB_PWRD/MAT1[0]); also elsewhere on the board
OUTPUT2.3_MCU: U2.35 (P1[21]/*MCABORT/PWM1[3]/SSEL0); also elsewhere on the board
OUTPUT2.4_MCU: U2.27 (P3[25]/MAT0[0]/PWM1[2]); also elsewhere on the board
OUTPUT3.2_MCU: U2.40 (P1[26]/MCOB1/PWM1[6]/CAP0[0]); also elsewhere on the board
RTCX1: C5.1, U2.16 (RTCX1), X1.1
RTCX2: C10.1, U2.18 (RTCX2), X1.2
UART_RX: U2.47 (P0[1]/TD1/RXD3/SCL1); also elsewhere on the board
UART_TX: U2.46 (P0[0]/RD1/TXD3/SDA1); also elsewhere on the board
USB_CONNECT: T1.1 (B), U2.64 (P2[9]/USB_CONNECT/RXD2)
USB_D_N: R9.2, U2.30 (P0[30]/USB_D?)
USB_D_P: R10.2, U2.29 (P0[29]/USB_D+)
USB_LED: LED1.C, U2.32 (P1[18]/USB_UP_LED/PWM1[1]/CAP1[0])
USB_V_BUS: R6.2, R7.1, U2.21 (P1[30]/VBUS/AD0[4])
VBAT+: U2.19 (VBAT), X3.+1 (VBAT+), X3.+2 (VBAT+)
XTAL1: U2.22 (XTAL1), X2.3 (OUT)

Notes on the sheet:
USB
BOOT SELECT
LED ON BOARD
RESET
EEPROM
RTC
12MHz CLOCK
DECOUPLING
ADC DECOUPLING

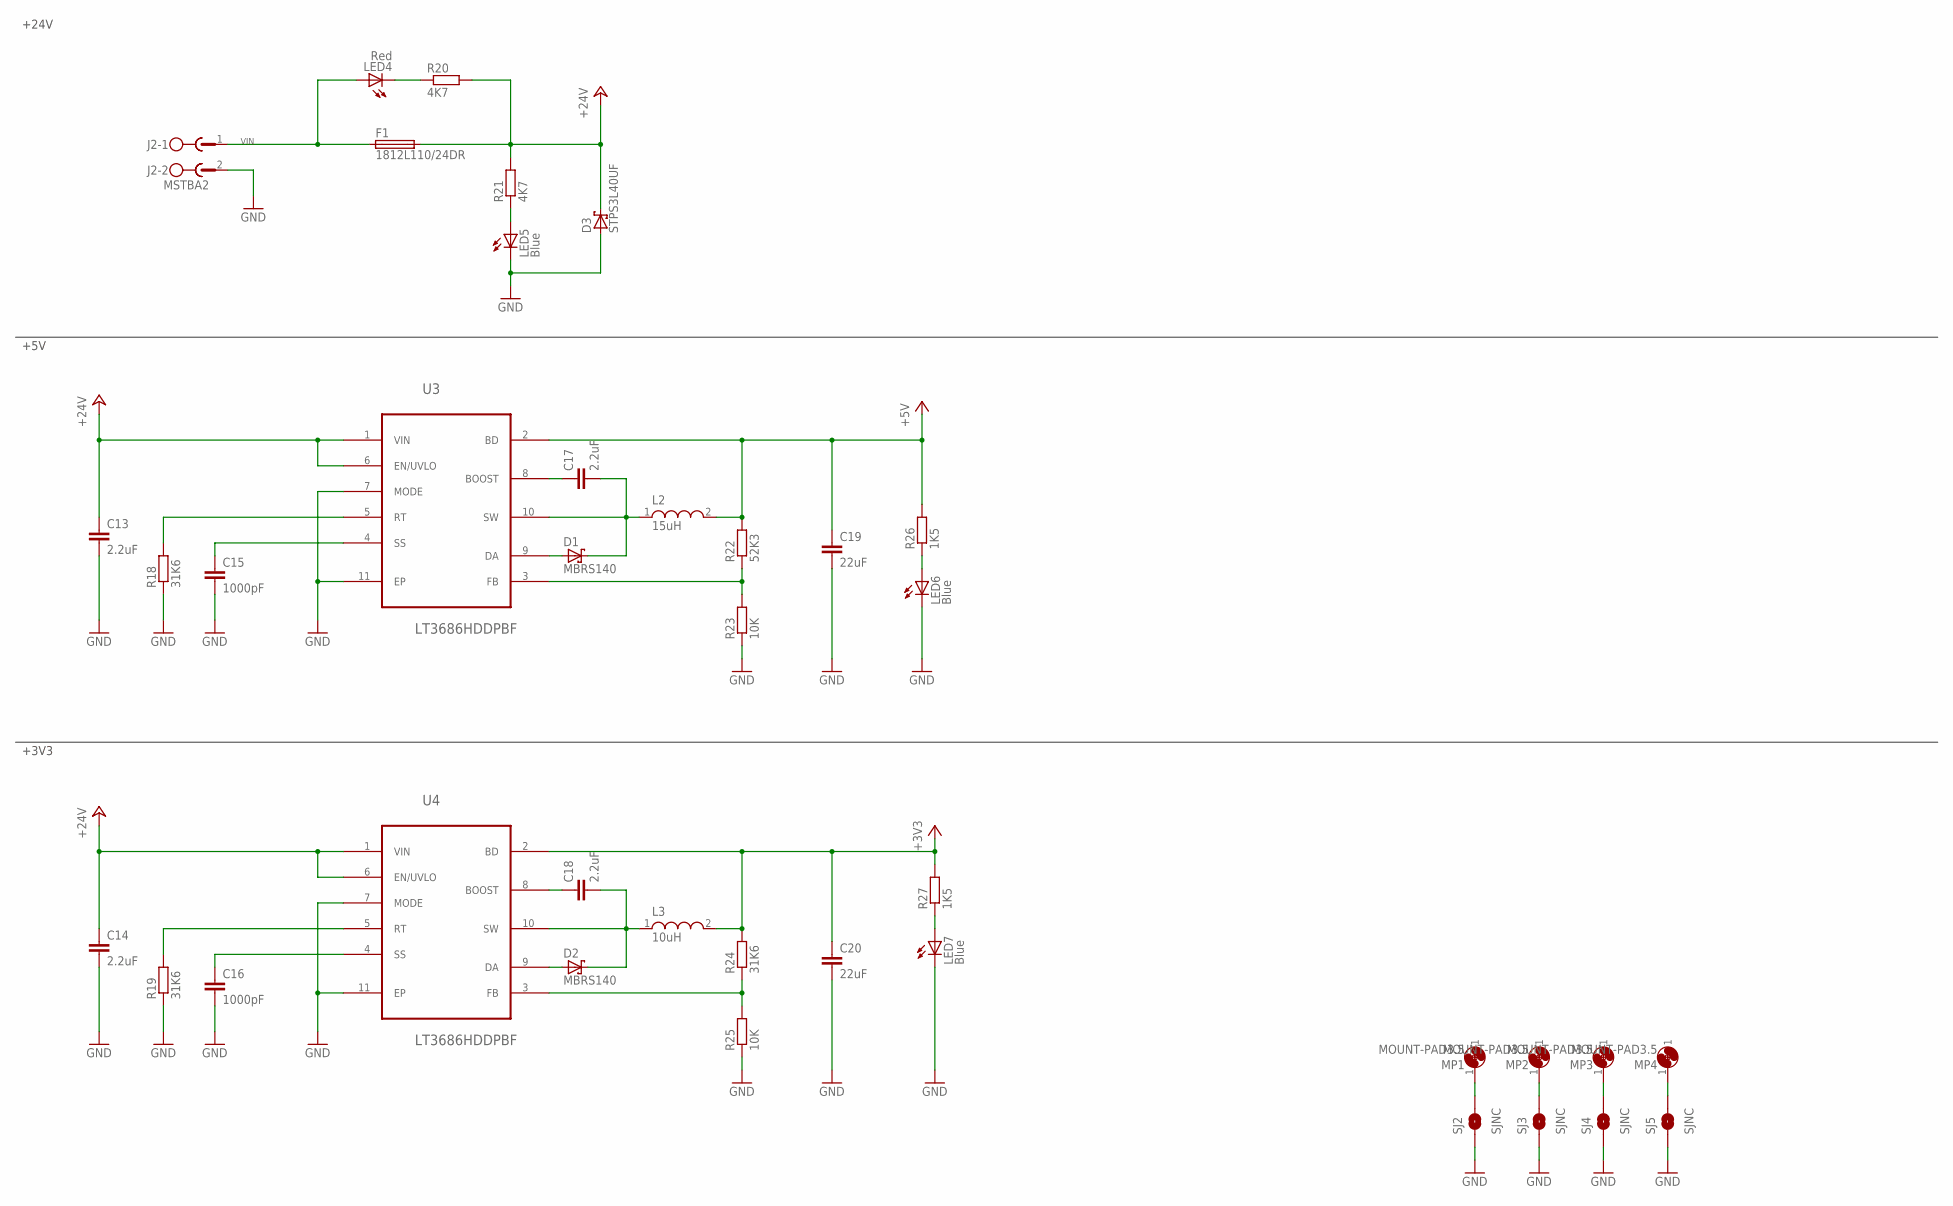
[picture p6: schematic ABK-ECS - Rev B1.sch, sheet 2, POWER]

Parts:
C13, C14, C17, C18: 2.2uF; C0603; MPN GRT188R61H225KE13D
C15, C16: 1000pF; C0603; MPN GRM188R71H102KA01D
C19, C20: 22uF; C0805; MPN C0805C226M9PACTU
D1, D2: MBRS140; DO-214AA; MPN MBRS140T3G
D3: STPS3L40UF; SMB
F1: 1812L110/24DR; LITTLEFUSE_SMD; MPN 3557
J2: MSTBA2
L2: 15uH; WE-PD2_5848/5820; MPN 744774115
L3: 10uH; WE-PD2_5848/5820; MPN 74477410
LED4: Red; CHIPLED_0603; MPN OVS-0608
LED5, LED6, LED7: Blue; CHIPLED_0603; MPN OVS-0603
MP1, MP2, MP3, MP4: MOUNT-PAD3.5; P3,5
R18, R19, R24: 31K6; R0603; MPN MCMR06X3162FTL
R20, R21: 4K7; R0603; MPN RC0603FR-074K7L
R22: 52K3; R0603; MPN MC0063W0603152K3
R23, R25: 10K; R0603; MPN RC0603FR-0710KL
R26, R27: 1K5; R0603; MPN RC0603FR-071K5L
SJ2, SJ3, SJ4, SJ5: SJNC; SJ_2S
U3, U4: LT3686HDDPBF; DFN300X300X80-11N

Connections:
1: MP1.1, SJ2.2
2: MP2.1, SJ3.2
3: MP3.1, SJ4.2
4: MP4.1, SJ5.2
+3V3: C20.1, L3.2, R24.2, R27.2, U4.2 (BD); also elsewhere on the board
+5V: C19.1, L2.2, R22.2, R26.2, U3.2 (BD); also elsewhere on the board
+24V: C13.1, C14.1, D3.C, F1.2, R20.2, R21.2, U3.1 (VIN), U3.6 (EN/UVLO), U4.1 (VIN), U4.6 (EN/UVLO); also elsewhere on the board
GND: C13.2, C14.2, C15.2, C16.2, C19.2, C20.2, D3.A, J2.2, LED5.C, LED6.C, LED7.C, R18.1, R19.1, R23.1, R25.1, SJ2.1, SJ3.1, SJ4.1, SJ5.1, U3.7 (MODE), U3.11 (EP), U4.7 (MODE), U4.11 (EP); also elsewhere on the board
unnamed: R18.2, U3.5 (RT)
unnamed: C15.1, U3.4 (SS)
unnamed: R19.2, U4.5 (RT)
unnamed: C16.1, U4.4 (SS)
unnamed: R22.1, R23.2, U3.3 (FB)
unnamed: C17.1, U3.8 (BOOST)
unnamed: C17.2, D1.C, L2.1, U3.10 (SW)
unnamed: D1.A, U3.9 (DA)
unnamed: R24.1, R25.2, U4.3 (FB)
unnamed: C18.1, U4.8 (BOOST)
unnamed: C18.2, D2.C, L3.1, U4.10 (SW)
unnamed: D2.A, U4.9 (DA)
unnamed: LED5.A, R21.1
unnamed: LED4.C, R20.1
unnamed: LED7.A, R27.1
unnamed: LED6.A, R26.1
VIN: F1.1, J2.1, LED4.A

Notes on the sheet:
+5V
+3V3
+24V

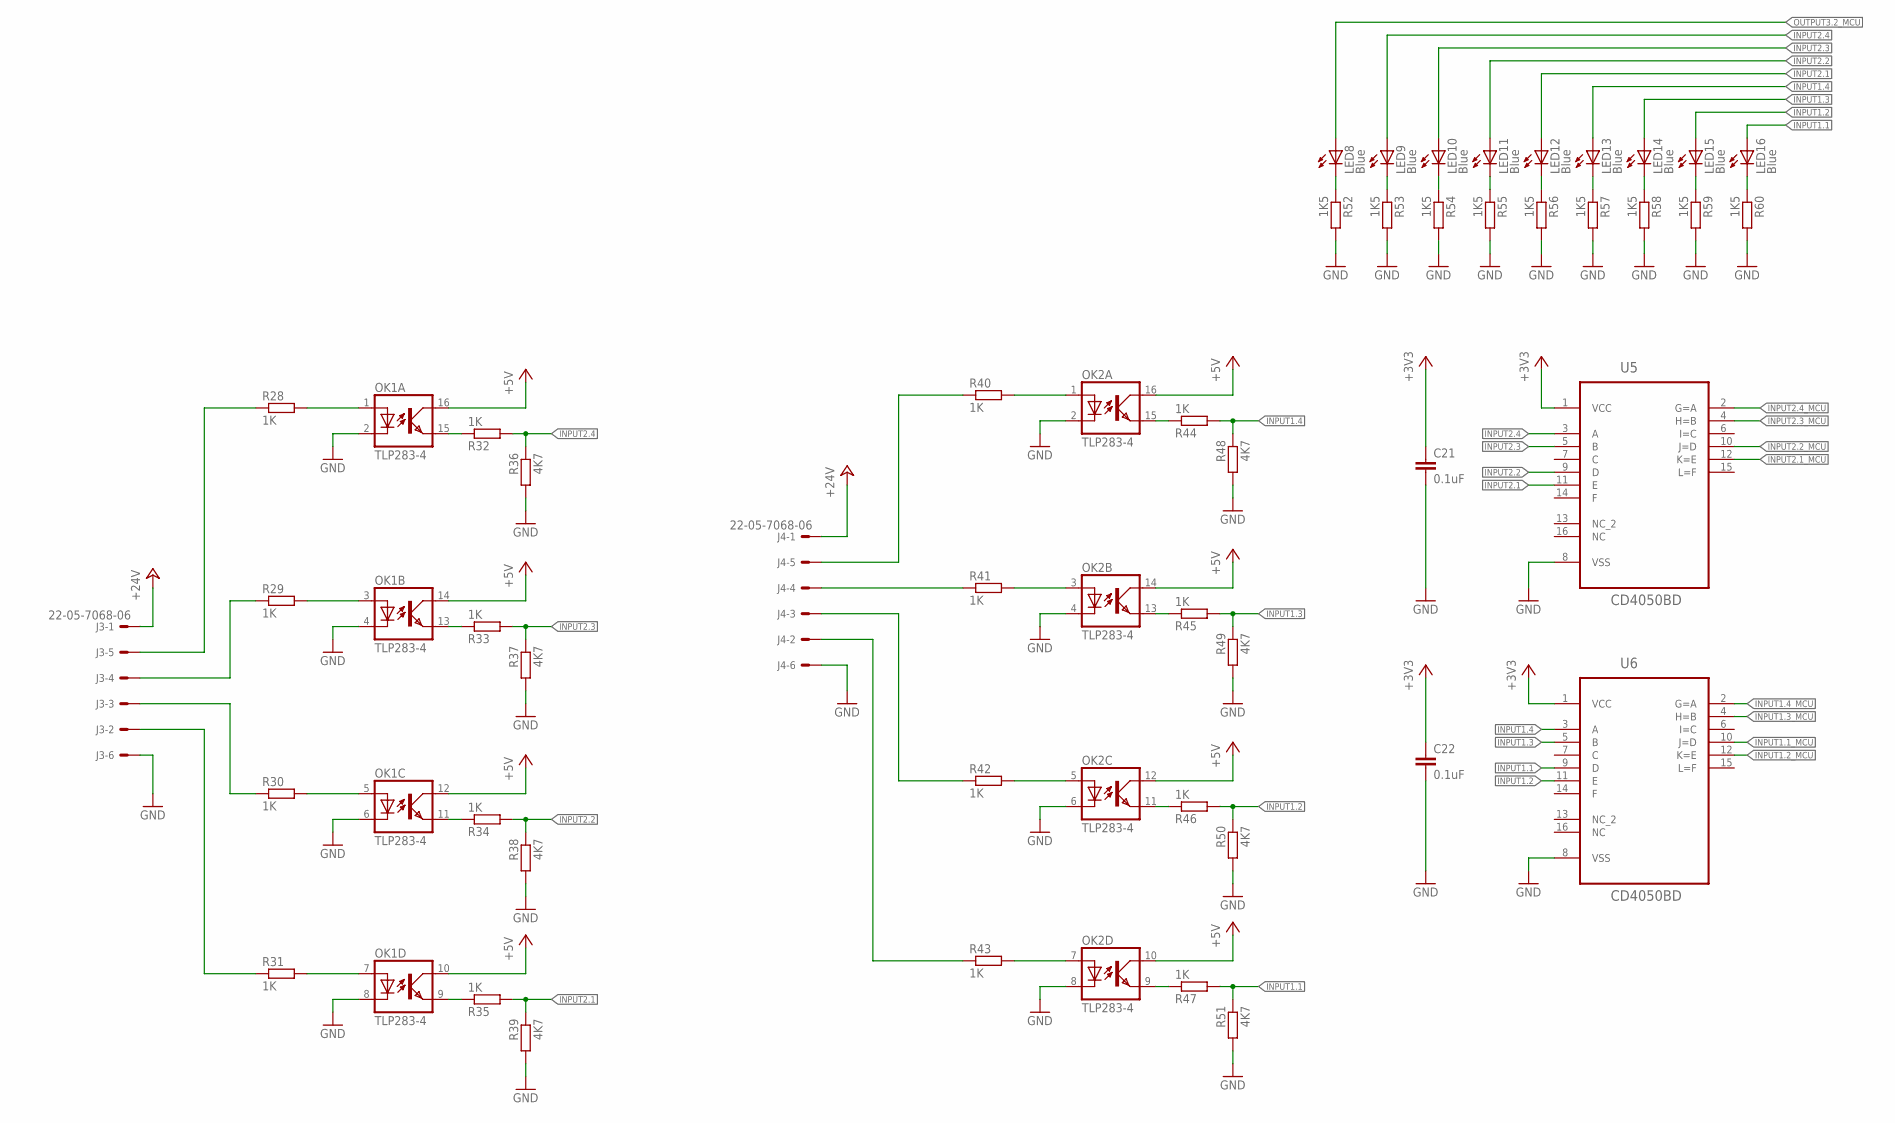
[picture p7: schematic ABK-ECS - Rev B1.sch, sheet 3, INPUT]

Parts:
C21, C22: 0.1uF; C0603; MPN MC0603B104K160CT
J3, J4: 22-05-7068-06; 7395-06
LED8, LED9, LED10, LED11, LED12, LED13, LED14, LED15, LED16: Blue; CHIPLED_0603; MPN OVS-0603
OK1, OK2: TLP283-4; MINI-FLAT-16; MPN TCMT4100
R28, R29, R30, R31, R32, R33, R34, R35, R40, R41, R42, R43, R44, R45, R46, R47: 1K; R0603; MPN RC0603FR-071KL
R36, R37, R38, R39, R48, R49, R50, R51: 4K7; R0603; MPN RC0603FR-074K7L
R52, R53, R54, R55, R56, R57, R58, R59, R60: 1K5; R0603; MPN RC0603FR-071K5L
U5, U6: CD4050BD; SOIC127P600X175-16N

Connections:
+3V3: C21.1, C22.1, U5.1 (VCC), U6.1 (VCC); also elsewhere on the board
+5V: OK1.10 (COL), OK1.12 (COL), OK1.14 (COL), OK1.16 (COL), OK2.10 (COL), OK2.12 (COL), OK2.14 (COL), OK2.16 (COL); also elsewhere on the board
+24V: J3.1, J4.1; also elsewhere on the board
GND: C21.2, C22.2, J3.6, J4.6, OK1.2 (C), OK1.4 (C), OK1.6 (C), OK1.8 (C), OK2.2 (C), OK2.4 (C), OK2.6 (C), OK2.8 (C), R36.2, R37.2, R38.2, R39.2, R48.2, R49.2, R50.2, R51.2, R52.2, R53.2, R54.2, R55.2, R56.2, R57.2, R58.2, R59.2, R60.2, U5.8 (VSS), U6.8 (VSS); also elsewhere on the board
INPUT1.1: LED16.A, R47.2, R51.1, U6.9 (D)
INPUT1.1_MCU: U6.10 (J=D); also elsewhere on the board
INPUT1.2: LED15.A, R46.2, R50.1, U6.11 (E)
INPUT1.2_MCU: U6.12 (K=E); also elsewhere on the board
INPUT1.3: LED14.A, R45.2, R49.1, U6.5 (B)
INPUT1.3_MCU: U6.4 (H=B); also elsewhere on the board
INPUT1.4: LED13.A, R44.2, R48.1, U6.3 (A)
INPUT1.4_MCU: U6.2 (G=A); also elsewhere on the board
INPUT2.1: LED12.A, R35.2, R39.1, U5.11 (E)
INPUT2.1_MCU: U5.12 (K=E); also elsewhere on the board
INPUT2.2: LED11.A, R34.2, R38.1, U5.9 (D)
INPUT2.2_MCU: U5.10 (J=D); also elsewhere on the board
INPUT2.3: LED10.A, R33.2, R37.1, U5.5 (B)
INPUT2.3_MCU: U5.4 (H=B); also elsewhere on the board
INPUT2.4: LED9.A, R32.2, R36.1, U5.3 (A)
INPUT2.4_MCU: U5.2 (G=A); also elsewhere on the board
unnamed: OK1.1 (A), R28.2
unnamed: OK1.3 (A), R29.2
unnamed: OK1.5 (A), R30.2
unnamed: OK1.7 (A), R31.2
unnamed: J3.2, R31.1
unnamed: J3.3, R30.1
unnamed: J3.4, R29.1
unnamed: J3.5, R28.1
unnamed: LED8.C, R52.1
unnamed: LED9.C, R53.1
unnamed: LED10.C, R54.1
unnamed: LED11.C, R55.1
unnamed: OK1.9 (EMIT), R35.1
unnamed: OK1.11 (EMIT), R34.1
unnamed: OK1.13 (EMIT), R33.1
unnamed: OK1.15 (EMIT), R32.1
unnamed: LED12.C, R56.1
unnamed: OK2.1 (A), R40.2
unnamed: J4.5, R40.1
unnamed: LED16.C, R60.1
unnamed: OK2.15 (EMIT), R44.1
unnamed: OK2.3 (A), R41.2
unnamed: J4.4, R41.1
unnamed: OK2.13 (EMIT), R45.1
unnamed: OK2.5 (A), R42.2
unnamed: J4.3, R42.1
unnamed: OK2.11 (EMIT), R46.1
unnamed: LED13.C, R57.1
unnamed: LED14.C, R58.1
unnamed: LED15.C, R59.1
unnamed: OK2.9 (EMIT), R47.1
unnamed: OK2.7 (A), R43.2
unnamed: J4.2, R43.1
OUTPUT3.2_MCU: LED8.A; also elsewhere on the board

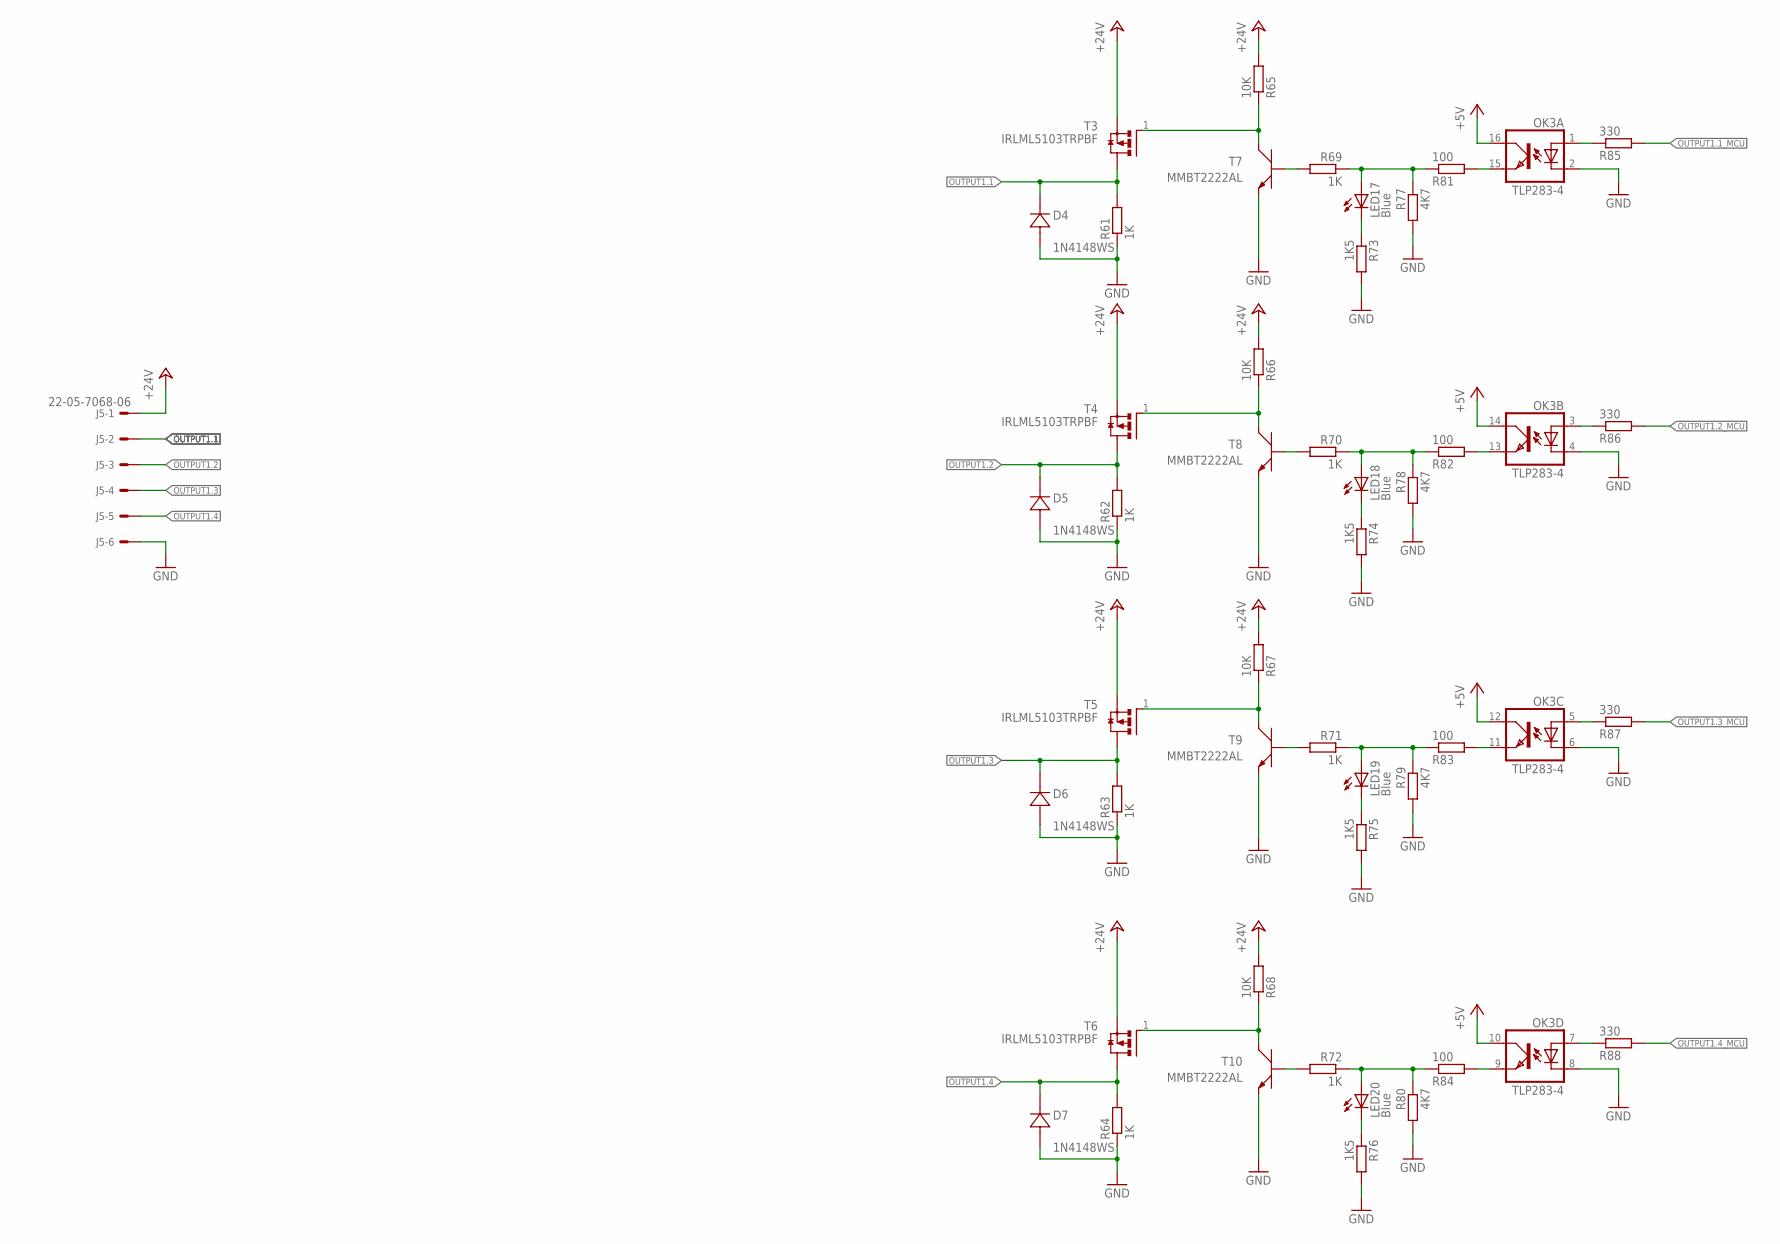
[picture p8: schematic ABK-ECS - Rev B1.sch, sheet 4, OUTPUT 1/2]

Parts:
D4, D5, D6, D7: 1N4148WS; SOD323-W; MPN 1N4148WS
J5: 22-05-7068-06; 7395-06
LED17, LED18, LED19, LED20: Blue; CHIPLED_0603; MPN OVS-0603
OK3: TLP283-4; MINI-FLAT-16; MPN TCMT4100
R61, R62, R63, R64: 1K; R1206
R65, R66, R67, R68: 10K; R0603; MPN RC0603FR-0710KL
R69, R70, R71, R72: 1K; R0603; MPN RC0603FR-071KL
R73, R74, R75, R76: 1K5; R0603; MPN RC0603FR-071K5L
R77, R78, R79, R80: 4K7; R0603; MPN RC0603FR-074K7L
R81, R82, R83, R84: 100; R0603; MPN RC0603FR-13100RL
R85, R86, R87, R88: 330; R0603; MPN RC0603FR-07330RL
T3, T4, T5, T6: IRLML5103TRPBF; SOT95P240X112-3N; MPN IRLML5103TRPBF
T7, T8, T9, T10: MMBT2222AL; SOT−23; MPN MMBT2222ALT1G

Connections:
+5V: OK3.10 (COL), OK3.12 (COL), OK3.14 (COL), OK3.16 (COL); also elsewhere on the board
+24V: J5.1, R65.2, R66.2, R67.2, R68.2, T3.2 (S), T4.2 (S), T5.2 (S), T6.2 (S); also elsewhere on the board
GND: D4.A (2), D5.A (2), D6.A (2), D7.A (2), J5.6, OK3.2 (C), OK3.4 (C), OK3.6 (C), OK3.8 (C), R61.1, R62.1, R63.1, R64.1, R73.2, R74.2, R75.2, R76.2, R77.2, R78.2, R79.2, R80.2, T7.2 (E), T8.2 (E), T9.2 (E), T10.2 (E); also elsewhere on the board
unnamed: LED17.A, R69.1, R77.1, R81.1
unnamed: OK3.15 (EMIT), R81.2
unnamed: LED18.A, R70.1, R78.1, R82.1
unnamed: OK3.13 (EMIT), R82.2
unnamed: LED19.A, R71.1, R79.1, R83.1
unnamed: LED20.A, R72.1, R80.1, R84.1
unnamed: OK3.11 (EMIT), R83.2
unnamed: OK3.9 (EMIT), R84.2
unnamed: OK3.1 (A), R85.1
unnamed: OK3.3 (A), R86.1
unnamed: OK3.7 (A), R88.1
unnamed: OK3.5 (A), R87.1
unnamed: LED17.C, R73.1
unnamed: LED18.C, R74.1
unnamed: LED19.C, R75.1
unnamed: LED20.C, R76.1
unnamed: R65.1, T3.1 (G), T7.3 (C)
unnamed: R66.1, T4.1 (G), T8.3 (C)
unnamed: R67.1, T5.1 (G), T9.3 (C)
unnamed: R68.1, T6.1 (G), T10.3 (C)
unnamed: R69.2, T7.1 (B)
unnamed: R70.2, T8.1 (B)
unnamed: R71.2, T9.1 (B)
unnamed: R72.2, T10.1 (B)
OUTPUT1.1: D4.C (1), J5.2, R61.2, T3.3 (D)
OUTPUT1.1_MCU: R85.2; also elsewhere on the board
OUTPUT1.2: D5.C (1), J5.3, R62.2, T4.3 (D)
OUTPUT1.2_MCU: R86.2; also elsewhere on the board
OUTPUT1.3: D6.C (1), J5.4, R63.2, T5.3 (D)
OUTPUT1.3_MCU: R87.2; also elsewhere on the board
OUTPUT1.4: D7.C (1), J5.5, R64.2, T6.3 (D)
OUTPUT1.4_MCU: R88.2; also elsewhere on the board

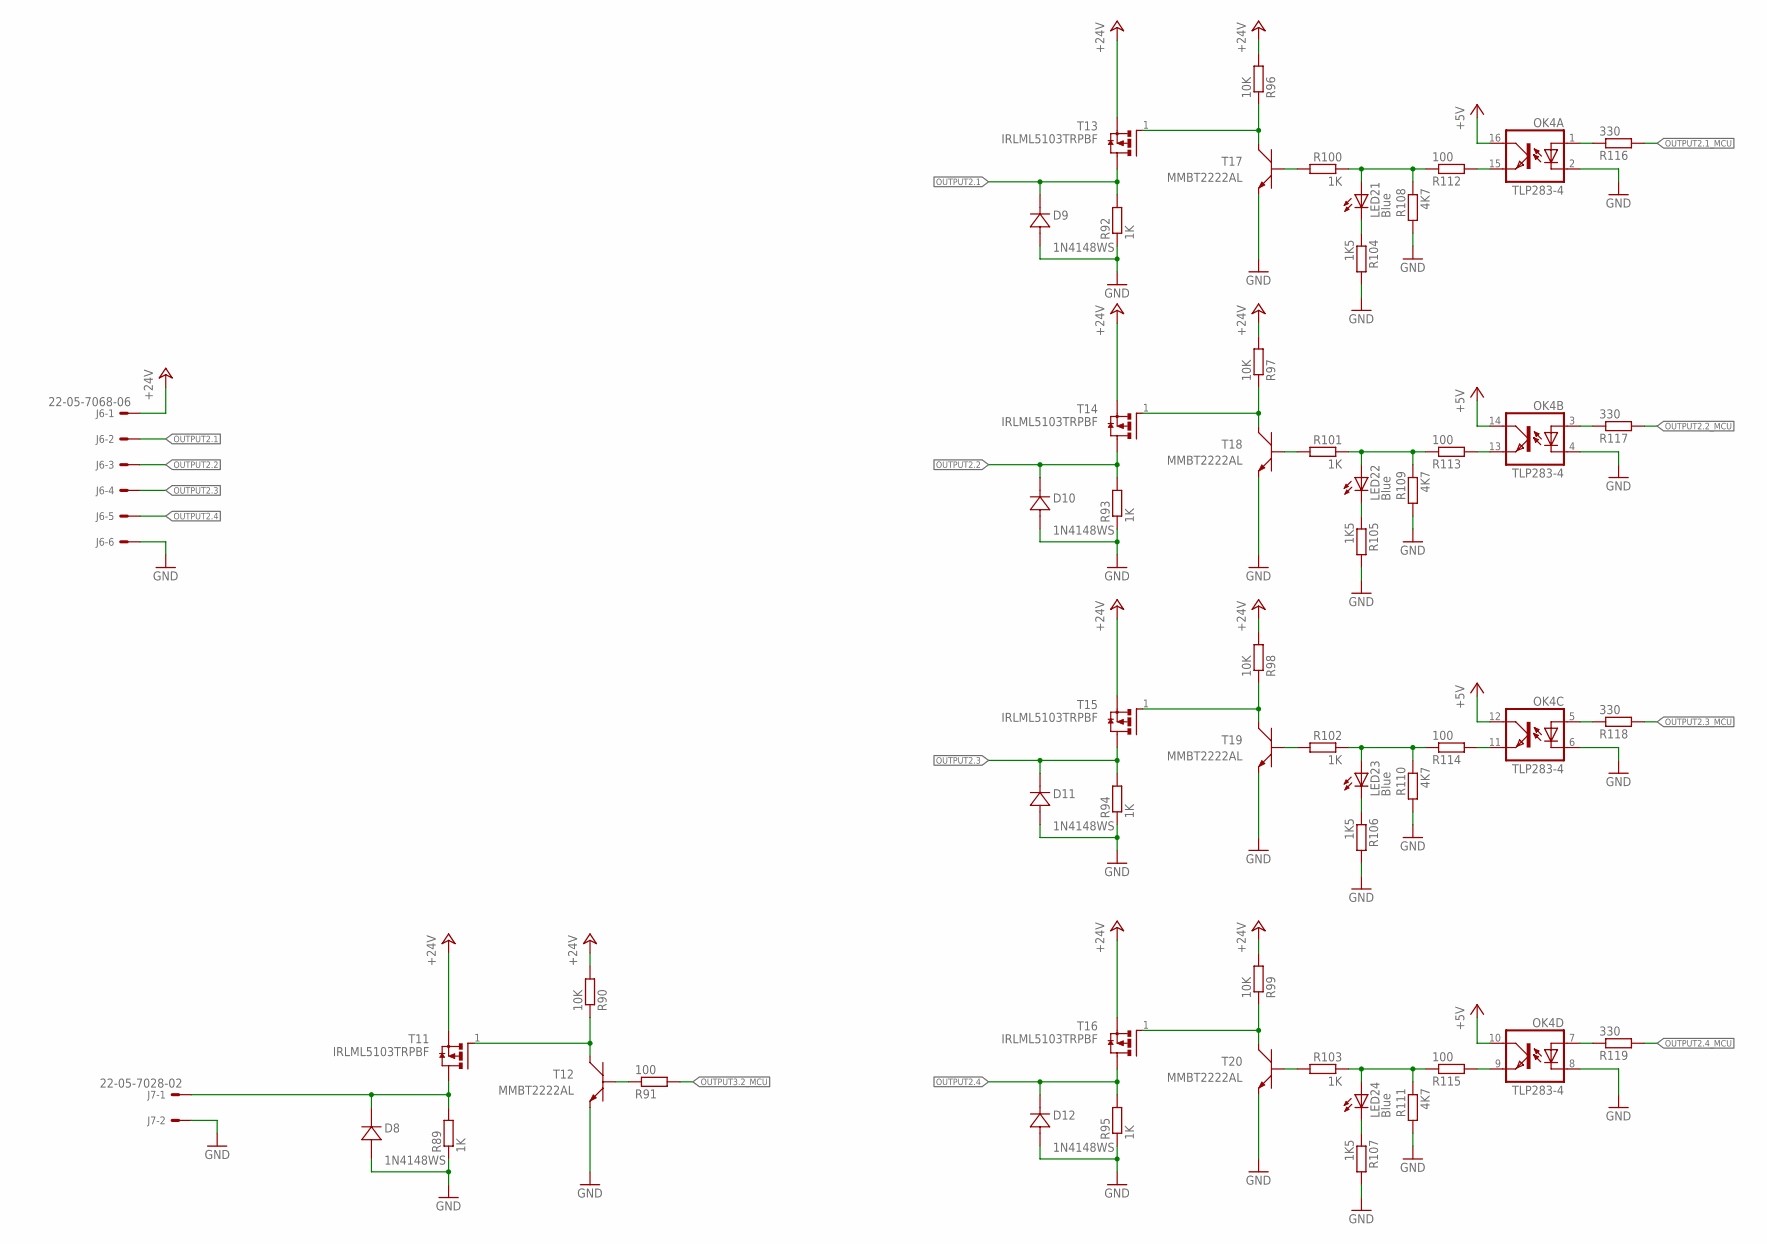
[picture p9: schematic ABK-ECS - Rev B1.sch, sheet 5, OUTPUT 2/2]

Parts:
D8, D9, D10, D11, D12: 1N4148WS; SOD323-W; MPN 1N4148WS
J6: 22-05-7068-06; 7395-06
J7: 22-05-7028-02; 7395-02; MPN 22-05-7028
LED21, LED22, LED23, LED24: Blue; CHIPLED_0603; MPN OVS-0603
OK4: TLP283-4; MINI-FLAT-16; MPN TCMT4100
R89, R92, R93, R94, R95: 1K; R1206
R90, R96, R97, R98, R99: 10K; R0603; MPN RC0603FR-0710KL
R91, R112, R113, R114, R115: 100; R0603; MPN RC0603FR-13100RL
R100, R101, R102, R103: 1K; R0603; MPN RC0603FR-071KL
R104, R105, R106, R107: 1K5; R0603; MPN RC0603FR-071K5L
R108, R109, R110, R111: 4K7; R0603; MPN RC0603FR-074K7L
R116, R117, R118, R119: 330; R0603; MPN RC0603FR-07330RL
T11, T13, T14, T15, T16: IRLML5103TRPBF; SOT95P240X112-3N; MPN IRLML5103TRPBF
T12, T17, T18, T19, T20: MMBT2222AL; SOT−23; MPN MMBT2222ALT1G

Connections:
+5V: OK4.10 (COL), OK4.12 (COL), OK4.14 (COL), OK4.16 (COL); also elsewhere on the board
+24V: J6.1, R90.2, R96.2, R97.2, R98.2, R99.2, T11.2 (S), T13.2 (S), T14.2 (S), T15.2 (S), T16.2 (S); also elsewhere on the board
GND: D8.A (2), D9.A (2), D10.A (2), D11.A (2), D12.A (2), J6.6, J7.2, OK4.2 (C), OK4.4 (C), OK4.6 (C), OK4.8 (C), R89.1, R92.1, R93.1, R94.1, R95.1, R104.2, R105.2, R106.2, R107.2, R108.2, R109.2, R110.2, R111.2, T12.2 (E), T17.2 (E), T18.2 (E), T19.2 (E), T20.2 (E); also elsewhere on the board
MOTOR_VFQ: D8.C (1), J7.1, R89.2, T11.3 (D)
unnamed: R100.2, T17.1 (B)
unnamed: R96.1, T13.1 (G), T17.3 (C)
unnamed: R101.2, T18.1 (B)
unnamed: R97.1, T14.1 (G), T18.3 (C)
unnamed: R102.2, T19.1 (B)
unnamed: R98.1, T15.1 (G), T19.3 (C)
unnamed: R103.2, T20.1 (B)
unnamed: R99.1, T16.1 (G), T20.3 (C)
unnamed: R91.1, T12.1 (B)
unnamed: R90.1, T11.1 (G), T12.3 (C)
unnamed: LED21.A, R100.1, R108.1, R112.1
unnamed: OK4.15 (EMIT), R112.2
unnamed: LED22.A, R101.1, R109.1, R113.1
unnamed: OK4.13 (EMIT), R113.2
unnamed: LED23.A, R102.1, R110.1, R114.1
unnamed: LED24.A, R103.1, R111.1, R115.1
unnamed: OK4.11 (EMIT), R114.2
unnamed: OK4.9 (EMIT), R115.2
unnamed: OK4.1 (A), R116.1
unnamed: OK4.3 (A), R117.1
unnamed: OK4.7 (A), R119.1
unnamed: OK4.5 (A), R118.1
unnamed: LED21.C, R104.1
unnamed: LED22.C, R105.1
unnamed: LED23.C, R106.1
unnamed: LED24.C, R107.1
OUTPUT2.1: D9.C (1), J6.2, R92.2, T13.3 (D)
OUTPUT2.1_MCU: R116.2; also elsewhere on the board
OUTPUT2.2: D10.C (1), J6.3, R93.2, T14.3 (D)
OUTPUT2.2_MCU: R117.2; also elsewhere on the board
OUTPUT2.3: D11.C (1), J6.4, R94.2, T15.3 (D)
OUTPUT2.3_MCU: R118.2; also elsewhere on the board
OUTPUT2.4: D12.C (1), J6.5, R95.2, T16.3 (D)
OUTPUT2.4_MCU: R119.2; also elsewhere on the board
OUTPUT3.2_MCU: R91.2; also elsewhere on the board

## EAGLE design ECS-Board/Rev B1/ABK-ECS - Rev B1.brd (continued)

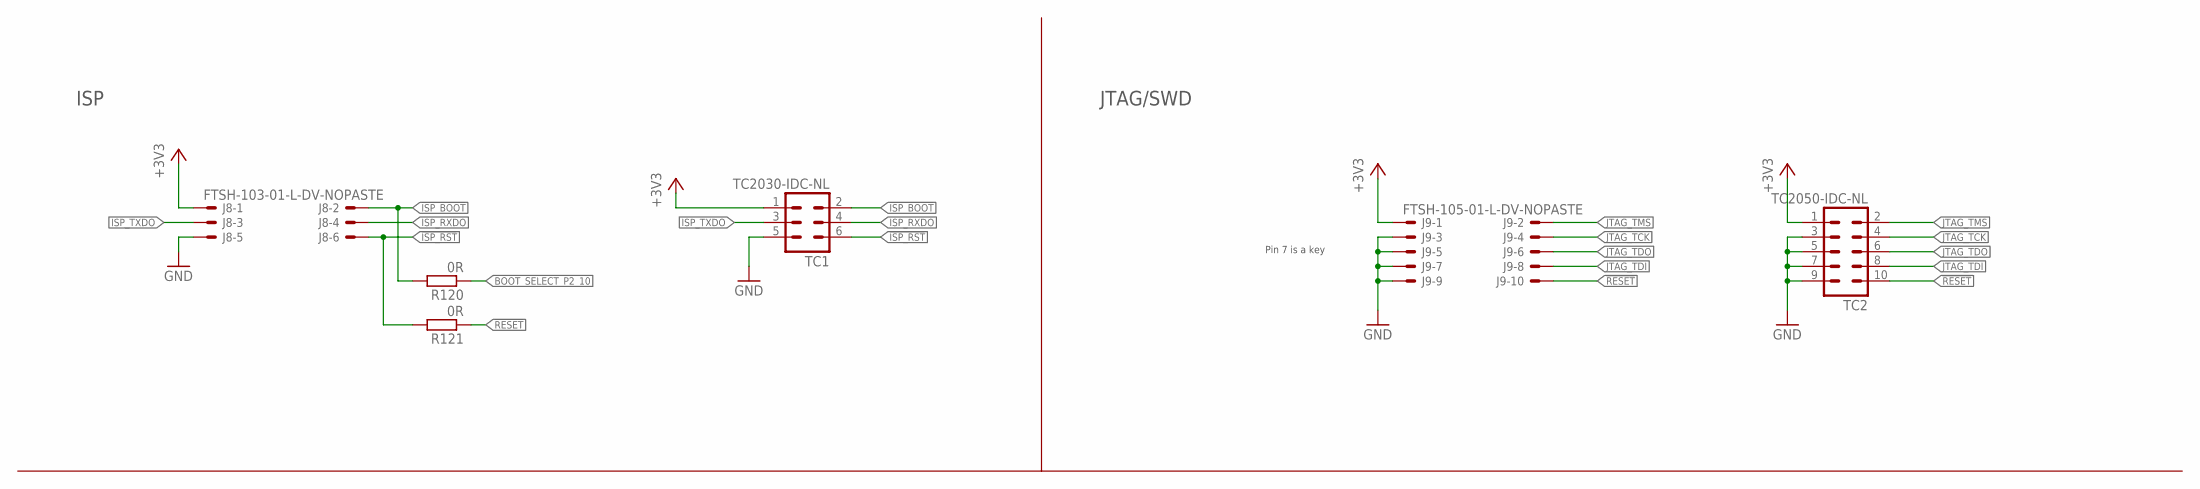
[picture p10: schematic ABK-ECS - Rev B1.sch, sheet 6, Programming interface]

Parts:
J8: FTSH-103-01-L-DV-NOPASTE
J9: FTSH-105-01-L-DV-NOPASTE
R120, R121: 0R; R0603; MPN MCMR06X000 PTL
TC1: TC2030-IDC-NL
TC2: TC2050-IDC-NL

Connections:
!ISP_BOOT: J8.2, R120.2, TC1.2
!ISP_RST: J8.6, R121.2, TC1.6
!RESET: J9.10, R121.1, TC2.10; also elsewhere on the board
+3V3: J8.1, J9.1, TC1.1, TC2.1; also elsewhere on the board
BOOT_SELECT_P2_10: R120.1; also elsewhere on the board
GND: J8.5, J9.3, J9.5, J9.7, J9.9, TC1.5, TC2.3, TC2.5, TC2.7, TC2.9; also elsewhere on the board
ISP_RXDO: J8.4, TC1.4; also elsewhere on the board
ISP_TXDO: J8.3, TC1.3; also elsewhere on the board
JTAG_TCK: J9.4, TC2.4; also elsewhere on the board
JTAG_TDI: J9.8, TC2.8; also elsewhere on the board
JTAG_TDO: J9.6, TC2.6; also elsewhere on the board
JTAG_TMS: J9.2, TC2.2; also elsewhere on the board

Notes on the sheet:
JTAG/SWD
Pin 7 is a key
ISP

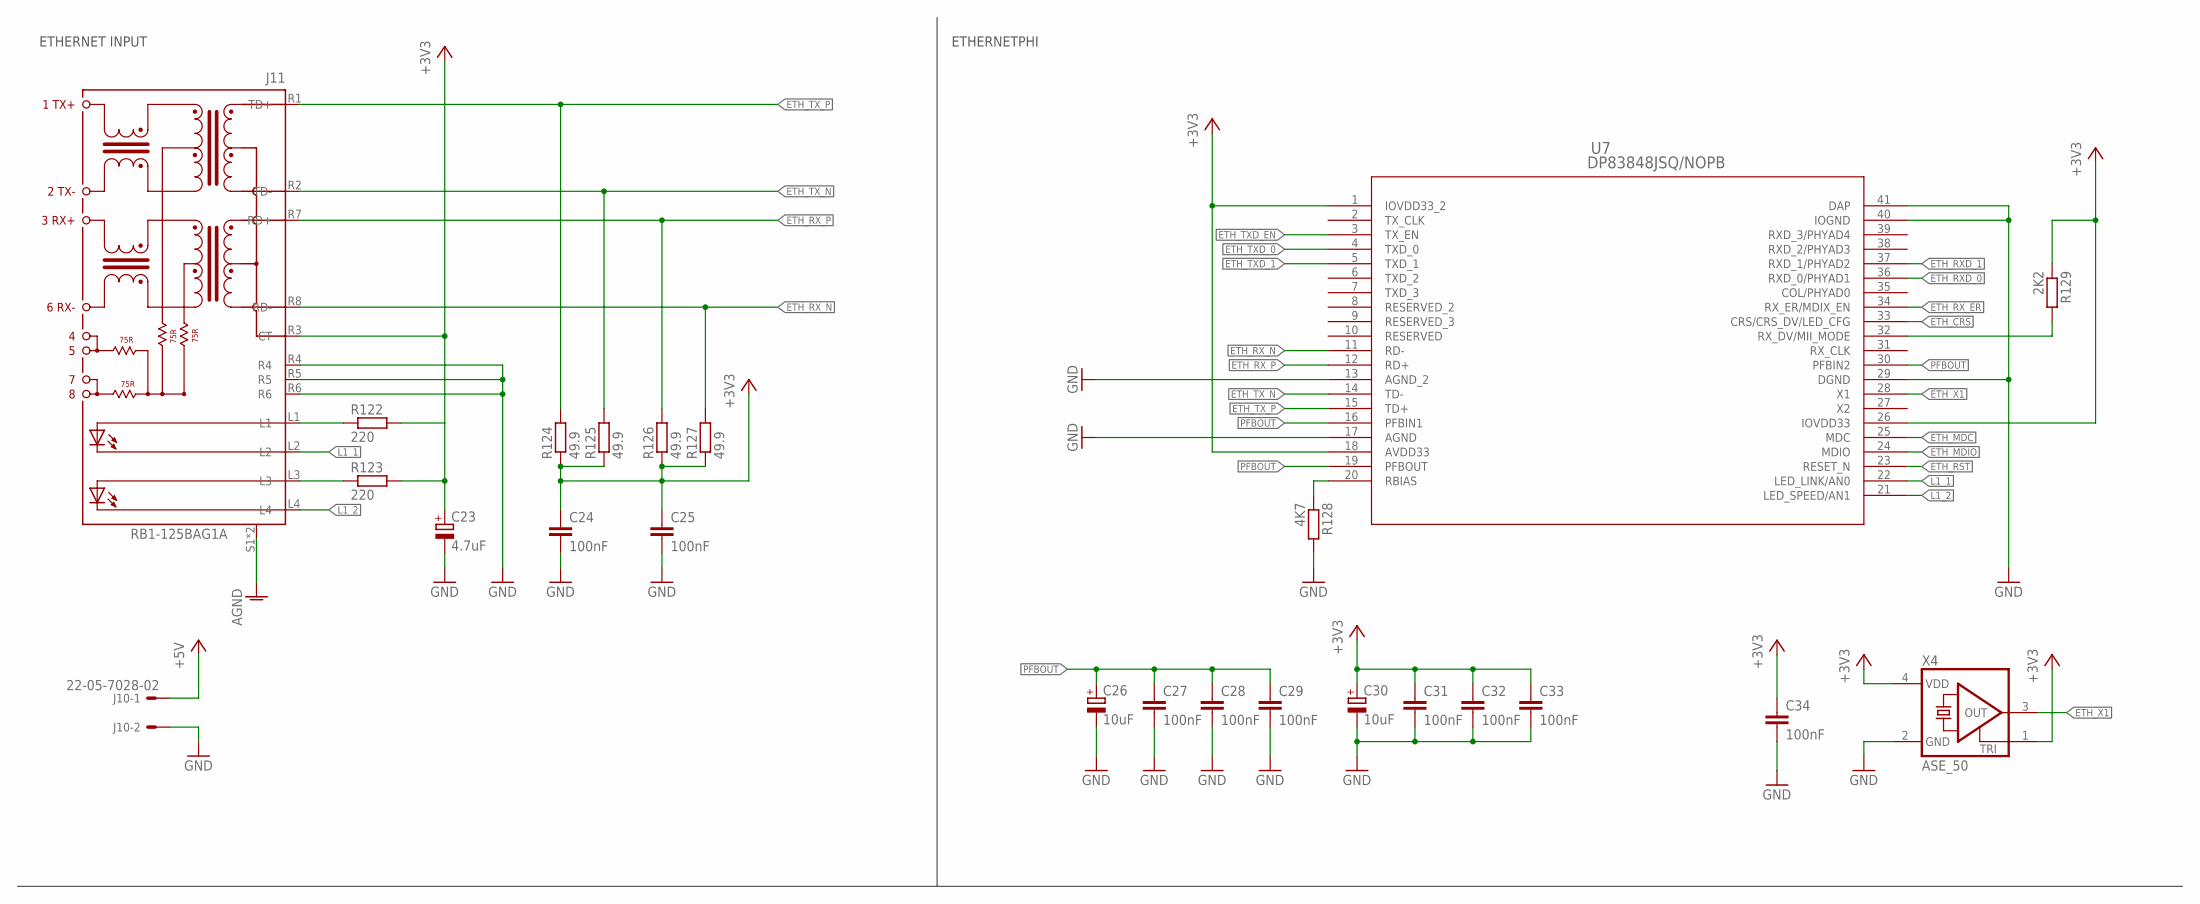
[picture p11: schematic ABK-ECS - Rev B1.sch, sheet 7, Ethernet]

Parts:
C23: 4.7uF; CT3216; MPN F931A475MAA
C24, C25, C27, C28, C29, C31, C32, C33, C34: 100nF; C0603; MPN MC0603B104K250CT
C26, C30: 10uF; CT3216; MPN F931A106MAA
J10: 22-05-7028-02; 7395-02; MPN 22-05-7028
J11: RB1-125BAG1A; WIZNET_RB1-125BAG1A
R122, R123: 220; R0603; MPN MCMR06X2200FTL
R124, R125, R126, R127: 49.9; R0603; MPN MCMR06X49R9FTL
R128: 4K7; R0603; MPN MCMR06X4701FTL
R129: 2K2; R0603; MPN MCMR06X2201FTL
U7: DP83848JSQ/NOPB; SQA40B; MPN DP83848JSQ/NOPB
X4: ASE_50; ASE; MPN ASE-50.000MHZ-LC-T

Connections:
+3V3: C23.+, C24.1, C25.1, C30.+, C31.1, C32.1, C33.1, C34.1, J11.R3 (CT), R122.2, R123.2, R124.1, R125.1, R126.1, R127.1, R129.1, U7.1 (IOVDD33_2), U7.18 (AVDD33), U7.26 (IOVDD33), X4.1 (TRI), X4.4 (VDD); also elsewhere on the board
+5V: J10.1; also elsewhere on the board
AGND: J11.S1, J11.S2
ETH_CRS: U7.33 (CRS/CRS_DV/LED_CFG); also elsewhere on the board
ETH_MDC: U7.25 (MDC); also elsewhere on the board
ETH_MDIO: U7.24 (MDIO); also elsewhere on the board
ETH_RST: U7.23 (RESET_N)
ETH_RXD_0: U7.36 (RXD_0/PHYAD1); also elsewhere on the board
ETH_RXD_1: U7.37 (RXD_1/PHYAD2); also elsewhere on the board
ETH_RX_ER: U7.34 (RX_ER/MDIX_EN); also elsewhere on the board
ETH_RX_N: J11.R8 (RD-), R127.2, U7.11 (RD-)
ETH_RX_P: J11.R7 (RD+), R126.2, U7.12 (RD+)
ETH_TXD_0: U7.4 (TXD_0); also elsewhere on the board
ETH_TXD_1: U7.5 (TXD_1); also elsewhere on the board
ETH_TXD_EN: U7.3 (TX_EN); also elsewhere on the board
ETH_TX_N: J11.R2 (TD-), R125.2, U7.14 (TD-)
ETH_TX_P: J11.R1 (TD+), R124.2, U7.15 (TD+)
ETH_X1: U7.28 (X1), X4.3 (OUT); also elsewhere on the board
GND: C23.-, C24.2, C25.2, C26.-, C27.2, C28.2, C29.2, C30.-, C31.2, C32.2, C33.2, C34.2, J10.2, J11.R4, J11.R5, J11.R6, R128.2, U7.13 (AGND_2), U7.17 (AGND), U7.29 (DGND), U7.40 (IOGND), U7.41 (DAP), X4.2 (GND); also elsewhere on the board
L1_1: J11.L2, U7.22 (LED_LINK/AN0)
L1_2: J11.L4, U7.21 (LED_SPEED/AN1)
MII_MODE: R129.2, U7.32 (RX_DV/MII_MODE)
unnamed: J11.L1, R122.1
unnamed: J11.L3, R123.1
unnamed: R128.1, U7.20 (RBIAS)
PFBOUT: C26.+, C27.1, C28.1, C29.1, U7.16 (PFBIN1), U7.19 (PFBOUT), U7.30 (PFBIN2)

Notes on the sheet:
ETHERNET INPUT
ETHERNETPHI

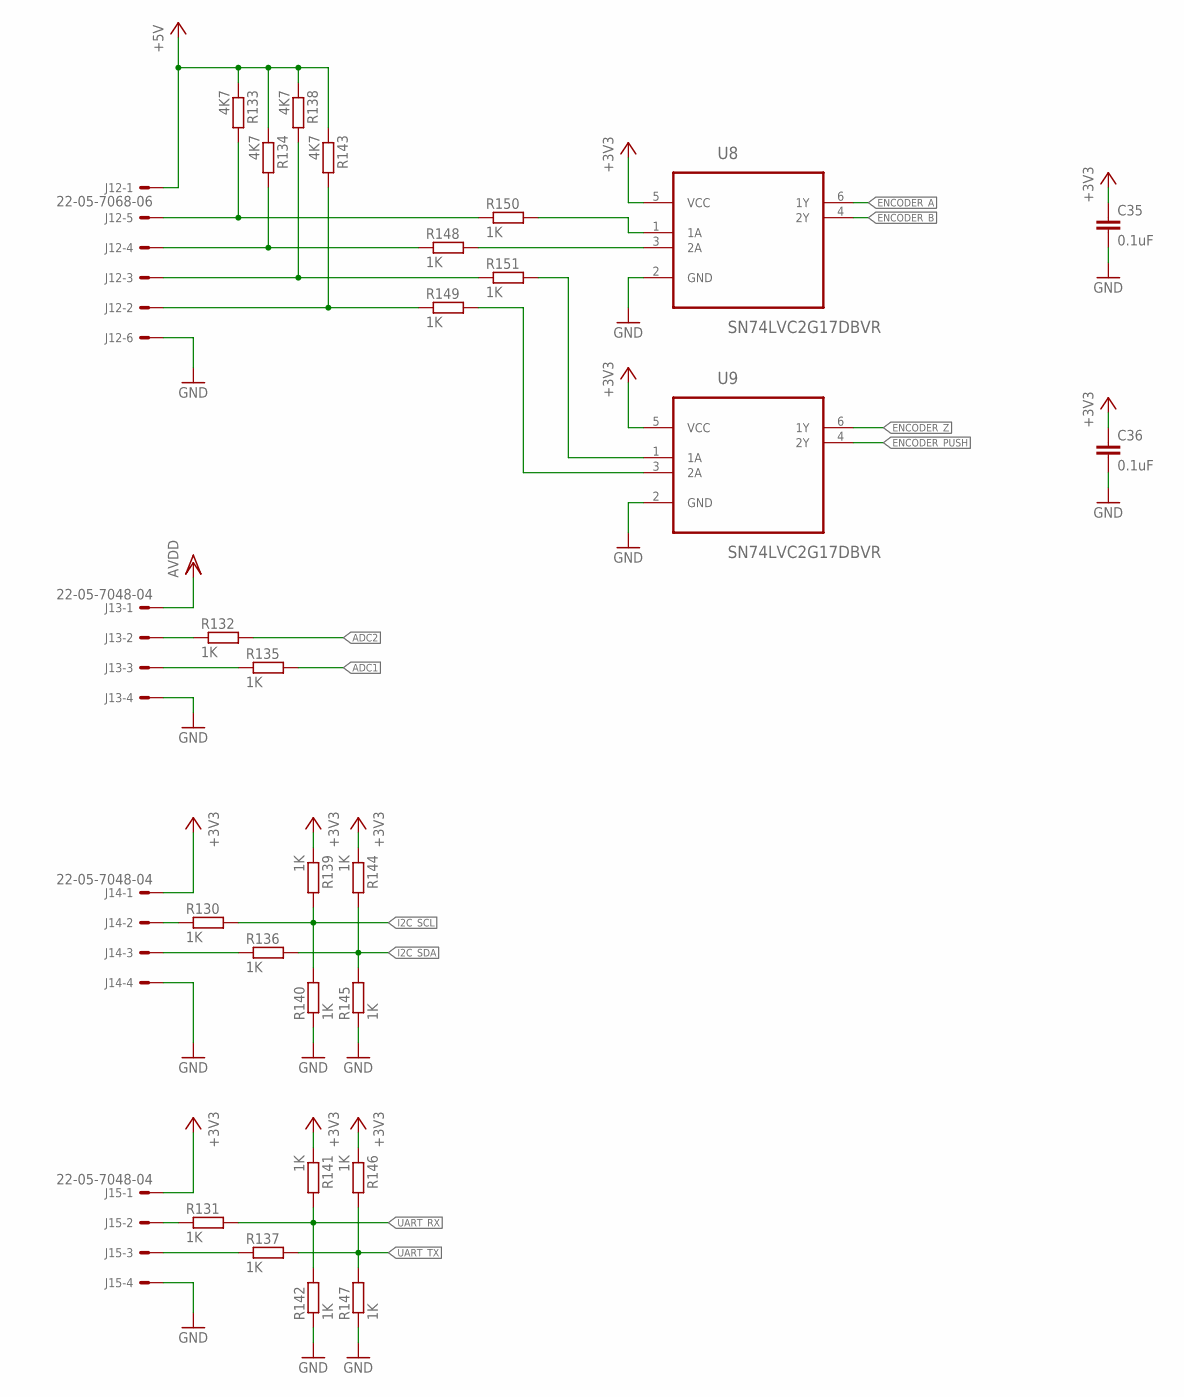
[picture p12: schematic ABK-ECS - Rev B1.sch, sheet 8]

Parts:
C35, C36: 0.1uF; C0603; MPN MC0603B104K160CT
J12: 22-05-7068-06; 7395-06; MPN 22-05-7058
J13, J14, J15: 22-05-7048-04; 7395-04
R130, R131, R132, R135, R136, R137, R139, R140, R141, R142, R144, R145, R146, R147, R148, R149, R150, R151: 1K; R0603; MPN MCMR06X1001FTL
R133, R134, R138, R143: 4K7; R0603; MPN MCMR06X2701FTL
U8, U9: SN74LVC2G17DBVR; SOT95P280X145-6N

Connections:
+3V3: C35.1, C36.1, J14.1, J15.1, R139.1, R141.1, R144.1, R146.1, U8.5 (VCC), U9.5 (VCC); also elsewhere on the board
+5V: J12.1, R133.1, R134.1, R138.1, R143.1; also elsewhere on the board
ADC1: R135.2; also elsewhere on the board
ADC2: R132.2; also elsewhere on the board
AVDD: J13.1; also elsewhere on the board
ENCODER_A: U8.6 (1Y); also elsewhere on the board
ENCODER_B: U8.4 (2Y); also elsewhere on the board
ENCODER_PUSH: U9.4 (2Y); also elsewhere on the board
ENCODER_Z: U9.6 (1Y); also elsewhere on the board
GND: C35.2, C36.2, J12.6, J13.4, J14.4, J15.4, R140.1, R142.1, R145.1, R147.1, U8.2 (GND), U9.2 (GND); also elsewhere on the board
I2C_SCL: R130.2, R139.2, R140.2; also elsewhere on the board
I2C_SDA: R136.2, R144.2, R145.2; also elsewhere on the board
unnamed: J12.5, R133.2, R150.1
unnamed: J12.4, R134.2, R148.1
unnamed: J12.3, R138.2, R151.1
unnamed: R149.2, U9.3 (2A)
unnamed: R148.2, U8.3 (2A)
unnamed: R150.2, U8.1 (1A)
unnamed: R151.2, U9.1 (1A)
unnamed: J12.2, R143.2, R149.1
unnamed: J13.2, R132.1
unnamed: J13.3, R135.1
unnamed: J14.2, R130.1
unnamed: J14.3, R136.1
unnamed: J15.2, R131.1
unnamed: J15.3, R137.1
UART_RX: R131.2, R141.2, R142.2; also elsewhere on the board
UART_TX: R137.2, R146.2, R147.2; also elsewhere on the board

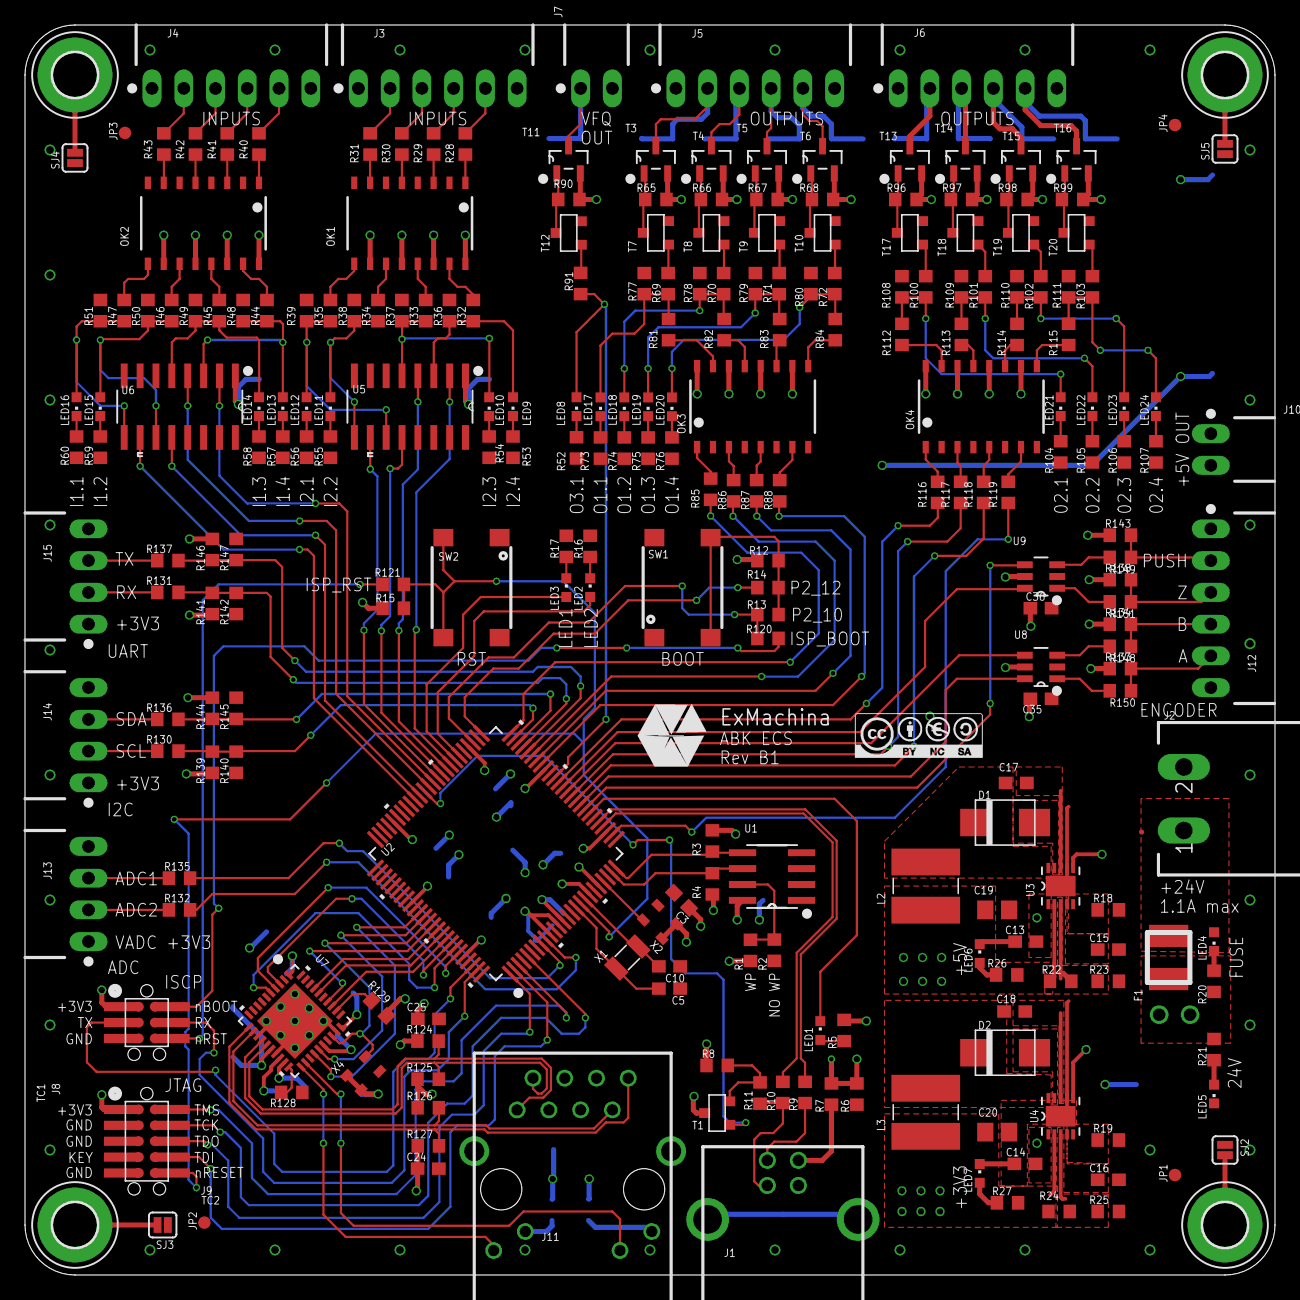
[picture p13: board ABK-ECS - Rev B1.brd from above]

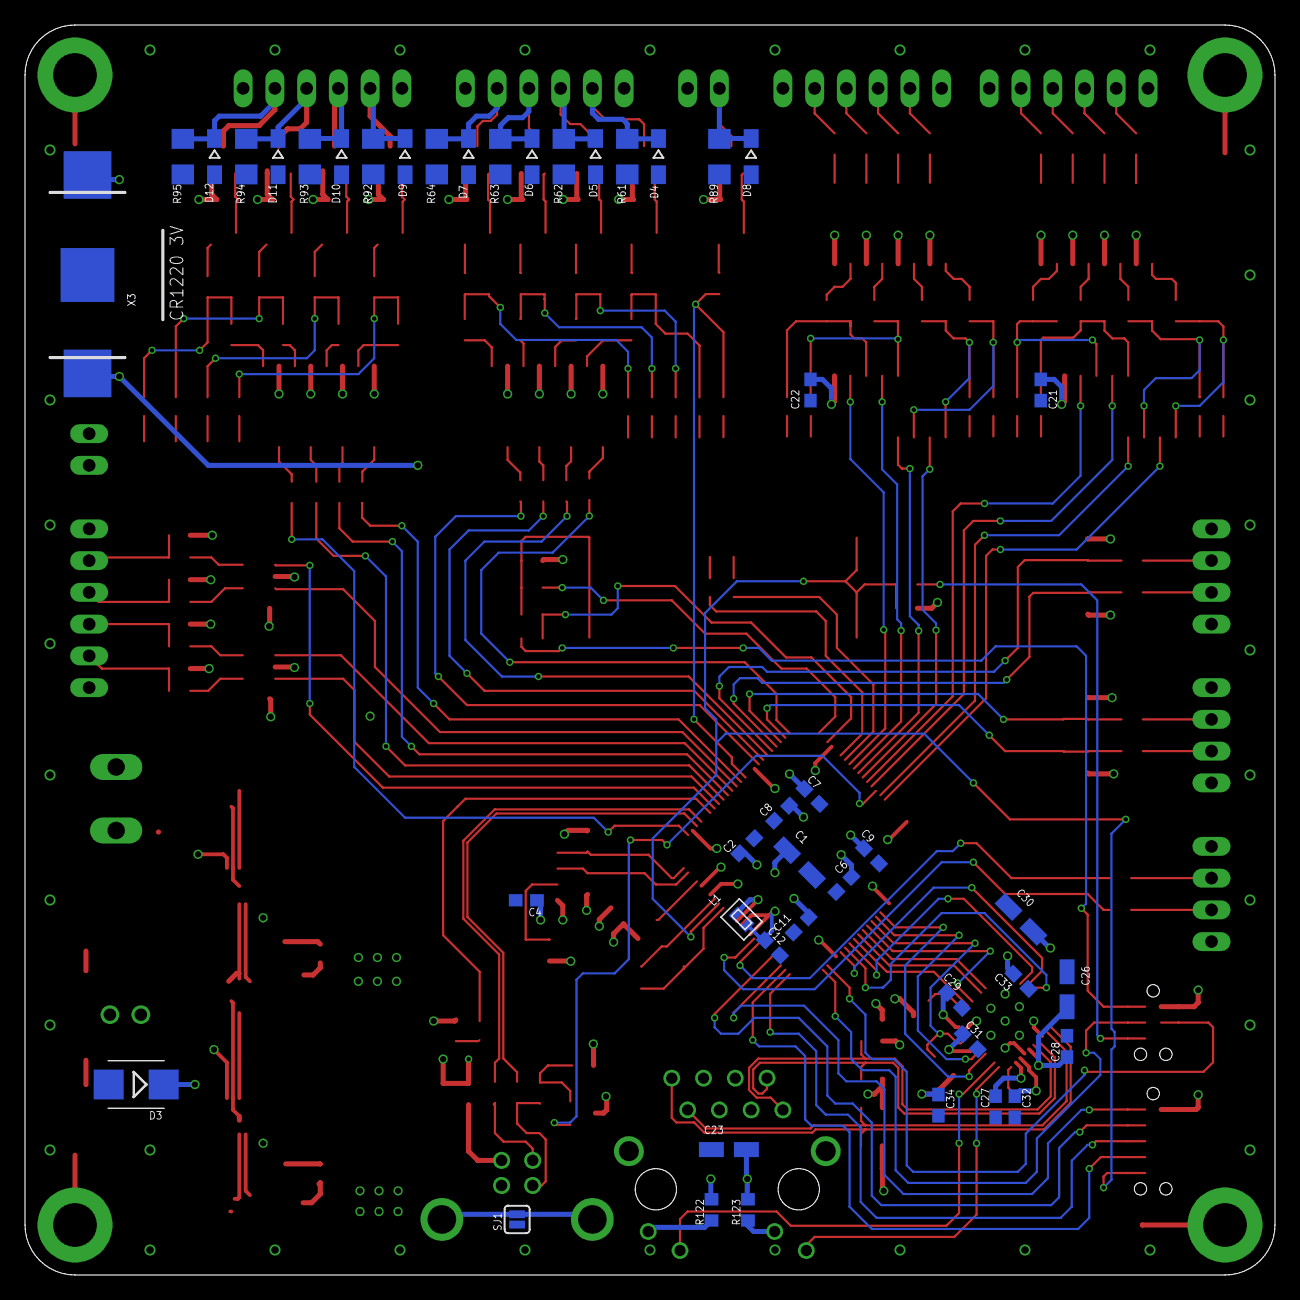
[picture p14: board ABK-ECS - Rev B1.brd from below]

Board: 4 copper layers, 100.0 x 100.0 mm, 297 parts (45 on the bottom side), 223 nets.

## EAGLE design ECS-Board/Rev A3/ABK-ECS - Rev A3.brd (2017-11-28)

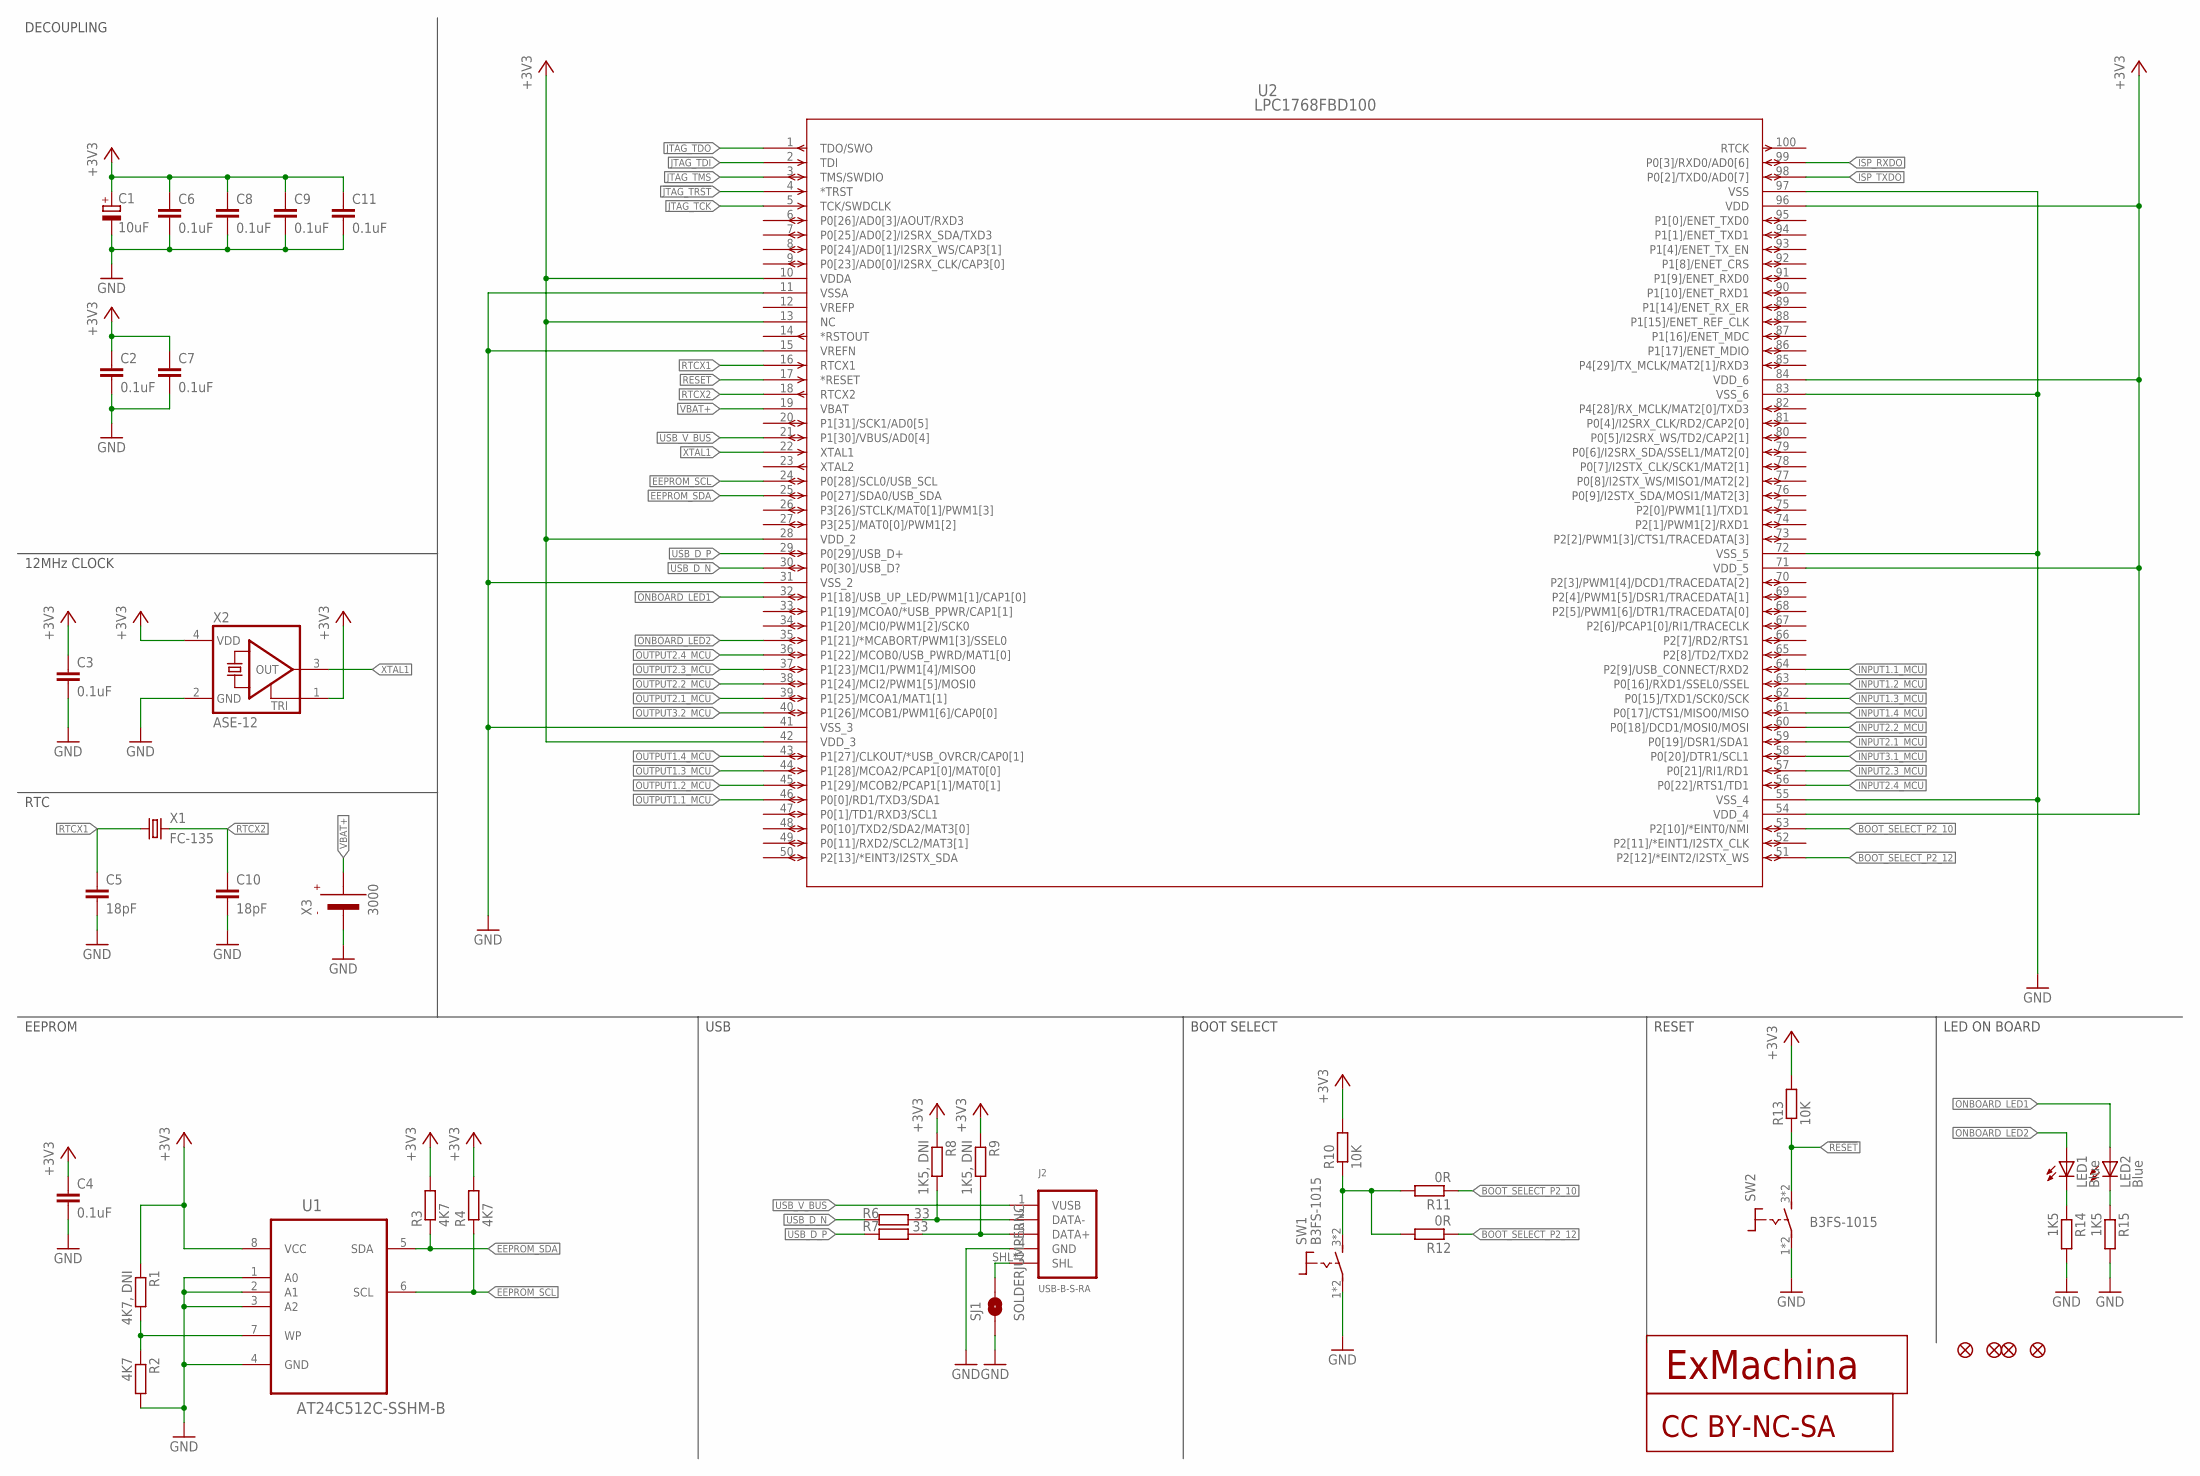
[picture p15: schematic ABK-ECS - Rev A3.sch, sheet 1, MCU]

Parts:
C1: 10uF; CT3216; MPN F931A106MAA
C2, C3, C4, C6, C7, C8, C9, C11: 0.1uF; C0603; MPN MC0603B104K160CT
C5, C10: 18pF; C0603; MPN GRM1885C1H180JA01D
CC1: CC-BY-NC-SA
J2: USB-B-S-RA; MPN USB-B-S-RA
JP1, JP2, JP3, JP4: FIDUCIAL1X2; FIDUCIAL-1X2
LED1, LED2: Blue; CHIPLED_0603; MPN OVS-0603
R1: 4K7, DNI; R0603; MPN RC0603FR-074K7L
R2, R3, R4: 4K7; R0603; MPN RC0603FR-074K7L
R6, R7: 33; R0603; MPN RC0603FR-0733RL
R8, R9: 1K5, DNI; R0603; MPN RC0603FR-071K5L
R10, R13: 10K; R0603; MPN RC0603FR-0710KL
R11, R12: 0R; R0603; MPN RC0603FR-070RL
R14, R15: 1K5; R0603; MPN RC0603FR-071K5L
SJ1: SOLDERJUMPERNC; SJ_2S
SW1, SW2: B3FS-1015; B3FS; MPN B3FS-1010
T1: EXMACHINA-LOGO-NAME; EXM-LOGO-BASELINE
U1: AT24C512C-SSHM-B; SOIC127P600X175-8N; MPN AT24C512C-SSHM-B
U2: LPC1768FBD100; SOT407-1; MPN LPC1768FBD100
X1: FC-135; MPN Q13FC13500004
X2: ASE-12; ASE; MPN ASE-12.000MHZ-LC-T
X3: 3000; MPN 3000

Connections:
!JTAG_TRST: U2.4 (*TRST)
!RESET: R13.1, SW2.3 (1), SW2.4 (1), U2.17 (*RESET); also elsewhere on the board
+3V3: C1.+, C2.1, C3.1, C4.1, C6.1, C7.1, C8.1, C9.1, C11.1, R1.1, R3.2, R4.2, R8.1, R9.1, R10.2, R13.2, U1.8 (VCC), U2.10 (VDDA), U2.13 (NC), U2.28 (VDD_2), U2.42 (VDD_3), U2.54 (VDD_4), U2.71 (VDD_5), U2.84 (VDD_6), U2.96 (VDD), X2.1 (TRI), X2.4 (VDD); also elsewhere on the board
BOOT_SELECT_P2_10: R11.1, U2.53 (P2[10]/*EINT0/NMI); also elsewhere on the board
BOOT_SELECT_P2_12: R12.1, U2.51 (P2[12]/*EINT2/I2STX_WS)
EEPROM_SCL: R4.1, U1.6 (SCL), U2.24 (P0[28]/SCL0/USB_SCL)
EEPROM_SDA: R3.1, U1.5 (SDA), U2.25 (P0[27]/SDA0/USB_SDA)
GND: C1.-, C2.2, C3.2, C4.2, C5.2, C6.2, C7.2, C8.2, C9.2, C10.2, C11.2, J2.4 (GND), R2.2, R14.2, R15.2, SJ1.1, SW1.1 (2), SW1.2, SW2.1 (2), SW2.2, U1.1 (A0), U1.2 (A1), U1.3 (A2), U1.4 (GND), U2.11 (VSSA), U2.15 (VREFN), U2.31 (VSS_2), U2.41 (VSS_3), U2.55 (VSS_4), U2.72 (VSS_5), U2.83 (VSS_6), U2.97 (VSS), X2.2 (GND), X3.- (VBAT-); also elsewhere on the board
INPUT1.1_MCU: U2.64 (P2[9]/USB_CONNECT/RXD2); also elsewhere on the board
INPUT1.2_MCU: U2.63 (P0[16]/RXD1/SSEL0/SSEL); also elsewhere on the board
INPUT1.3_MCU: U2.62 (P0[15]/TXD1/SCK0/SCK); also elsewhere on the board
INPUT1.4_MCU: U2.61 (P0[17]/CTS1/MISO0/MISO); also elsewhere on the board
INPUT2.1_MCU: U2.59 (P0[19]/DSR1/SDA1); also elsewhere on the board
INPUT2.2_MCU: U2.60 (P0[18]/DCD1/MOSI0/MOSI); also elsewhere on the board
INPUT2.3_MCU: U2.57 (P0[21]/RI1/RD1); also elsewhere on the board
INPUT2.4_MCU: U2.56 (P0[22]/RTS1/TD1); also elsewhere on the board
INPUT3.1_MCU: U2.58 (P0[20]/DTR1/SCL1); also elsewhere on the board
ISP_RXDO: U2.99 (P0[3]/RXD0/AD0[6]); also elsewhere on the board
ISP_TXDO: U2.98 (P0[2]/TXD0/AD0[7]); also elsewhere on the board
JTAG_TCK: U2.5 (TCK/SWDCLK); also elsewhere on the board
JTAG_TDI: U2.2 (TDI); also elsewhere on the board
JTAG_TDO: U2.1 (TDO/SWO); also elsewhere on the board
JTAG_TMS: U2.3 (TMS/SWDIO); also elsewhere on the board
unnamed: J2.3 (DATA+), R7.1, R9.2
unnamed: J2.2 (DATA-), R6.1, R8.2
unnamed: LED2.C, R15.1
unnamed: R10.1, R11.2, R12.2, SW1.3 (1), SW1.4 (1)
unnamed: R1.2, R2.1, U1.7 (WP)
unnamed: LED1.C, R14.1
unnamed: J2.SHL, J2.SHL1 (SHL), SJ1.2
ONBOARD_LED1: LED2.A, U2.32 (P1[18]/USB_UP_LED/PWM1[1]/CAP1[0])
ONBOARD_LED2: LED1.A, U2.35 (P1[21]/*MCABORT/PWM1[3]/SSEL0)
OUTPUT1.1_MCU: U2.46 (P0[0]/RD1/TXD3/SDA1); also elsewhere on the board
OUTPUT1.2_MCU: U2.45 (P1[29]/MCOB2/PCAP1[1]/MAT0[1]); also elsewhere on the board
OUTPUT1.3_MCU: U2.44 (P1[28]/MCOA2/PCAP1[0]/MAT0[0]); also elsewhere on the board
OUTPUT1.4_MCU: U2.43 (P1[27]/CLKOUT/*USB_OVRCR/CAP0[1]); also elsewhere on the board
OUTPUT2.1_MCU: U2.39 (P1[25]/MCOA1/MAT1[1]); also elsewhere on the board
OUTPUT2.2_MCU: U2.38 (P1[24]/MCI2/PWM1[5]/MOSI0); also elsewhere on the board
OUTPUT2.3_MCU: U2.37 (P1[23]/MCI1/PWM1[4]/MISO0); also elsewhere on the board
OUTPUT2.4_MCU: U2.36 (P1[22]/MCOB0/USB_PWRD/MAT1[0]); also elsewhere on the board
OUTPUT3.2_MCU: U2.40 (P1[26]/MCOB1/PWM1[6]/CAP0[0]); also elsewhere on the board
RTCX1: C5.1, U2.16 (RTCX1), X1.1
RTCX2: C10.1, U2.18 (RTCX2), X1.2
USB_D_N: R6.2, U2.30 (P0[30]/USB_D?)
USB_D_P: R7.2, U2.29 (P0[29]/USB_D+)
USB_V_BUS: J2.1 (VUSB), U2.21 (P1[30]/VBUS/AD0[4])
VBAT+: U2.19 (VBAT), X3.+1 (VBAT+), X3.+2 (VBAT+)
VREFP: U2.12 (VREFP)
XTAL1: U2.22 (XTAL1), X2.3 (OUT)

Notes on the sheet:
USB
BOOT SELECT
LED ON BOARD
RESET
EEPROM
RTC
12MHz CLOCK
DECOUPLING

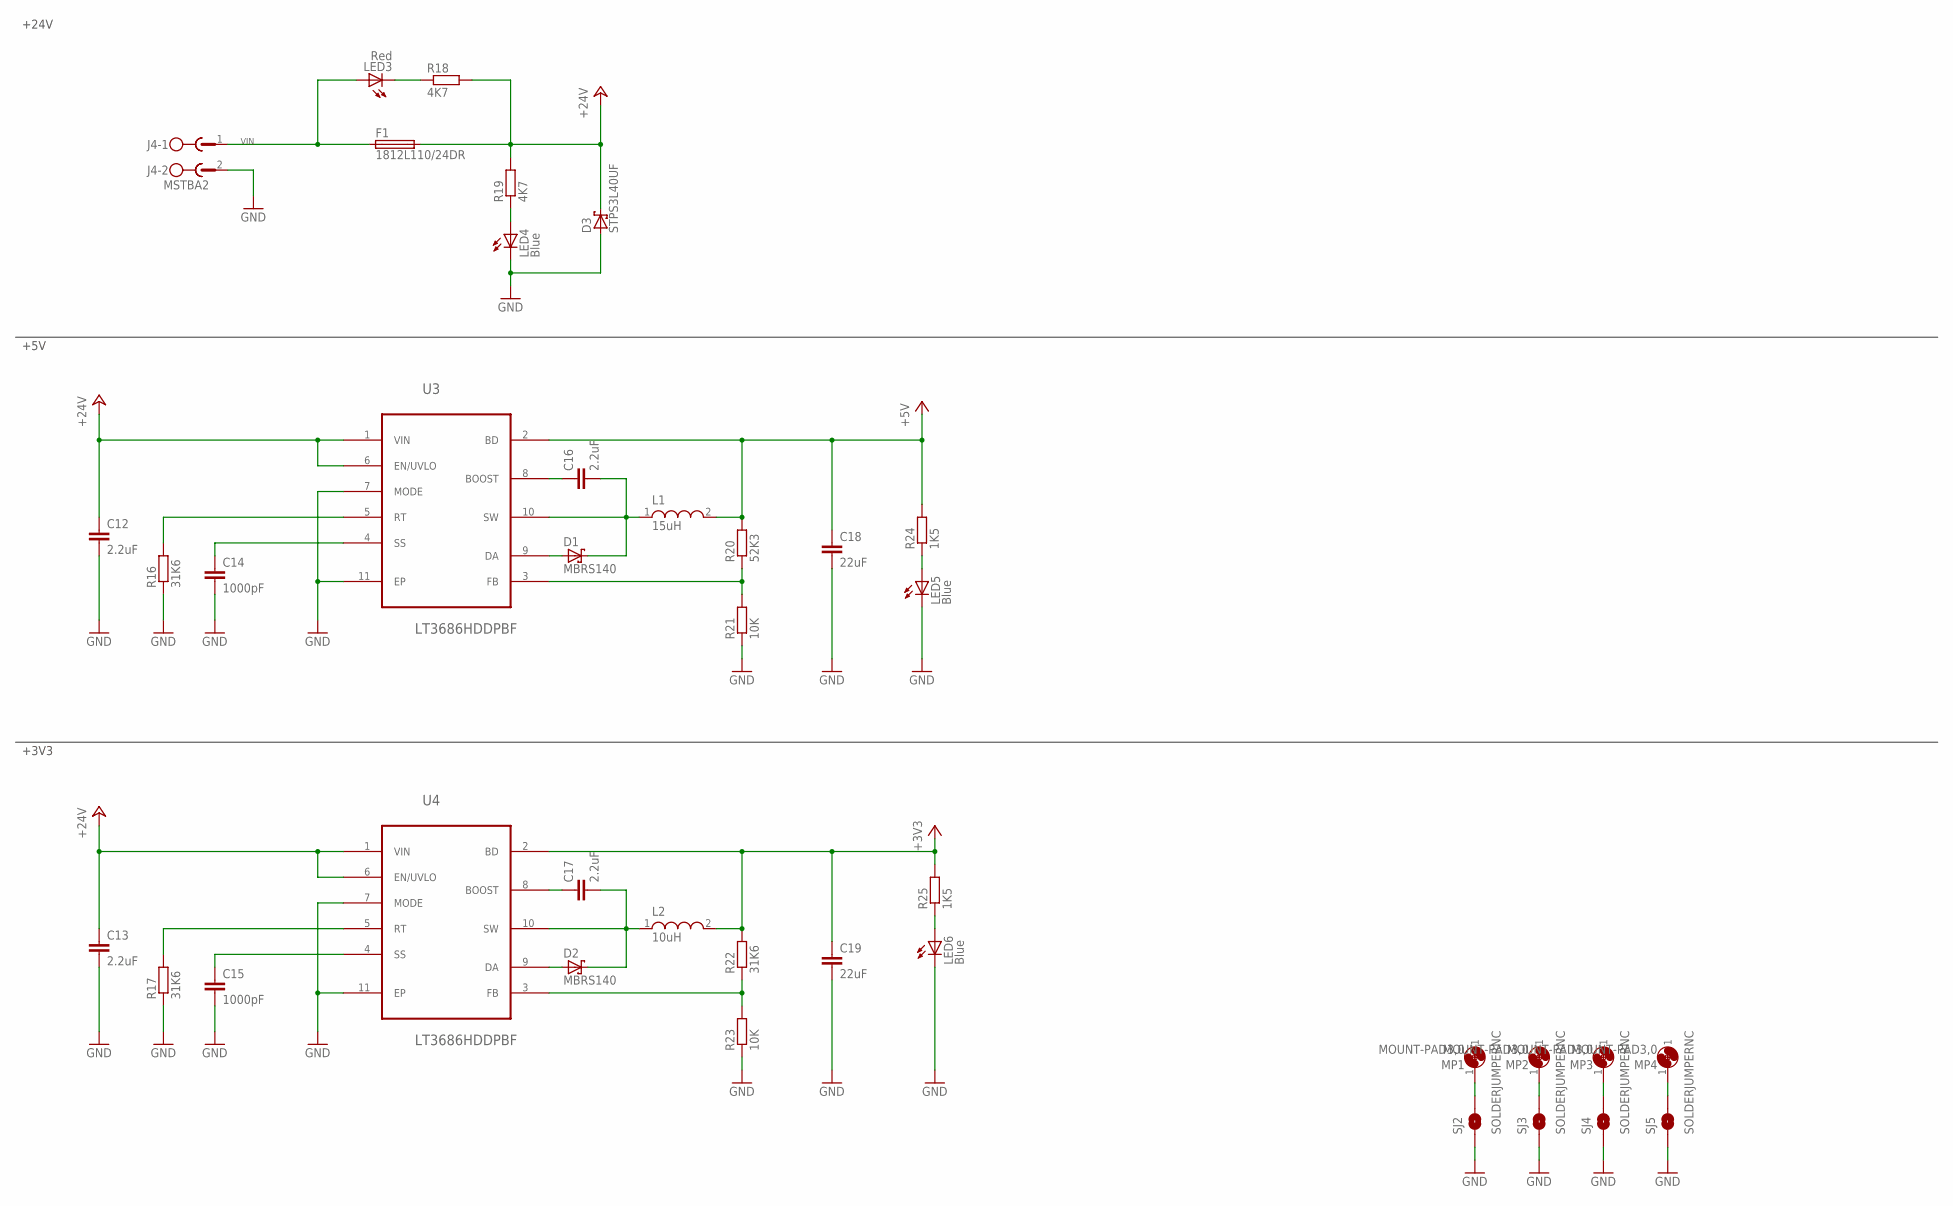
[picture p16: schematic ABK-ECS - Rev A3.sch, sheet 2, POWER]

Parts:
C12, C13, C16, C17: 2.2uF; C0603; MPN GRT188R61H225KE13D
C14, C15: 1000pF; C0603; MPN GRM188R71H102KA01D
C18, C19: 22uF; C0805; MPN C0805C226M9PACTU
D1, D2: MBRS140; DO-214AA; MPN MBRS140T3G
D3: STPS3L40UF; SMB
F1: 1812L110/24DR; LITTLEFUSE_SMD; MPN 3557
J4: MSTBA2
L1: 15uH; WE-PD2_5848/5820; MPN 744774115
L2: 10uH; WE-PD2_5848/5820; MPN 74477410
LED3: Red; CHIPLED_0603; MPN OVS-0608
LED4, LED5, LED6: Blue; CHIPLED_0603; MPN OVS-0603
MP1, MP2, MP3, MP4: MOUNT-PAD3,0; P3,0
R16, R17, R22: 31K6; R0603; MPN MCMR06X3162FTL
R18, R19: 4K7; R0603; MPN RC0603FR-074K7L
R20: 52K3; R0603; MPN MC0063W0603152K3
R21, R23: 10K; R0603; MPN RC0603FR-0710KL
R24, R25: 1K5; R0603; MPN RC0603FR-071K5L
SJ2, SJ3, SJ4, SJ5: SOLDERJUMPERNC; SJ_2S
U3, U4: LT3686HDDPBF; DFN300X300X80-11N

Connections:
1: MP1.1, SJ2.2
2: MP2.1, SJ3.2
3: MP3.1, SJ4.2
4: MP4.1, SJ5.2
+3V3: C19.1, L2.2, R22.2, R25.2, U4.2 (BD); also elsewhere on the board
+5V: C18.1, L1.2, R20.2, R24.2, U3.2 (BD); also elsewhere on the board
+24V: C12.1, C13.1, D3.C, F1.2, R18.2, R19.2, U3.1 (VIN), U3.6 (EN/UVLO), U4.1 (VIN), U4.6 (EN/UVLO); also elsewhere on the board
GND: C12.2, C13.2, C14.2, C15.2, C18.2, C19.2, D3.A, J4.2, LED4.C, LED5.C, LED6.C, R16.1, R17.1, R21.1, R23.1, SJ2.1, SJ3.1, SJ4.1, SJ5.1, U3.7 (MODE), U3.11 (EP), U4.7 (MODE), U4.11 (EP); also elsewhere on the board
unnamed: R16.2, U3.5 (RT)
unnamed: C14.1, U3.4 (SS)
unnamed: R17.2, U4.5 (RT)
unnamed: C15.1, U4.4 (SS)
unnamed: R20.1, R21.2, U3.3 (FB)
unnamed: C16.1, U3.8 (BOOST)
unnamed: C16.2, D1.C, L1.1, U3.10 (SW)
unnamed: D1.A, U3.9 (DA)
unnamed: R22.1, R23.2, U4.3 (FB)
unnamed: C17.1, U4.8 (BOOST)
unnamed: C17.2, D2.C, L2.1, U4.10 (SW)
unnamed: D2.A, U4.9 (DA)
unnamed: LED4.A, R19.1
unnamed: LED3.C, R18.1
unnamed: LED6.A, R25.1
unnamed: LED5.A, R24.1
VIN: F1.1, J4.1, LED3.A

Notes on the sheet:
+5V
+3V3
+24V

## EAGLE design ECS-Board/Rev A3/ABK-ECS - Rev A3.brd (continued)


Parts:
C22, C23, C24: 0.1uF; C0603; MPN MC0603B104K160CT
D5: STPS3L40UF; SMB
J5, J7: 22-05-7068-06; 7395-06
J6: 22-05-7028-02; 7395-02; MPN 22-05-7028
K1: G6K-2G-Y; MPN G6K-2G-Y 24DC
LED7: Red; CHIPLED_0603; MPN OVS-0608
LED8, LED9, LED10, LED11, LED12, LED13, LED14, LED15, LED16: Blue; CHIPLED_0603; MPN OVS-0603
OK1, OK2: TLP283-4; MINI-FLAT-16; MPN TCMT4100
R26, R40: 100; R0603; MPN RC0603FR-13100RL
R27, R28, R29, R30, R31, R32, R33, R34, R42, R43, R44, R45, R46, R47, R48, R49: 1K; R0603; MPN RC0603FR-071KL
R35, R36, R37, R38, R39, R50, R51, R52, R53: 4K7; R0603; MPN RC0603FR-074K7L
R41, R54, R55, R56, R57, R58, R59, R60, R61, R62: 1K5; R0603; MPN RC0603FR-071K5L
U6, U7: CD4050BD; SOIC127P600X175-16N

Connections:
+3V3: C23.1, C24.1, U6.1 (VCC), U7.1 (VCC); also elsewhere on the board
+5V: OK1.10 (COL), OK1.12 (COL), OK1.14 (COL), OK1.16 (COL), OK2.10 (COL), OK2.12 (COL), OK2.14 (COL), OK2.16 (COL), R39.1, R41.2; also elsewhere on the board
+24V: J5.1, J6.1, J7.1; also elsewhere on the board
GND: C22.2, C23.2, C24.2, D5.A, J5.6, J7.6, K1.3, K1.8 (-), OK1.2 (C), OK1.4 (C), OK1.6 (C), OK1.8 (C), OK2.2 (C), OK2.4 (C), OK2.6 (C), OK2.8 (C), R35.2, R36.2, R37.2, R38.2, R50.2, R51.2, R52.2, R53.2, R54.2, R55.2, R56.2, R57.2, R58.2, R59.2, R60.2, R61.2, R62.2, U6.8 (VSS), U7.8 (VSS); also elsewhere on the board
INPUT1.1: LED16.A, R49.2, R53.1, U7.9 (D)
INPUT1.1_MCU: U7.10 (J=D); also elsewhere on the board
INPUT1.2: LED15.A, R48.2, R52.1, U7.11 (E)
INPUT1.2_MCU: U7.12 (K=E); also elsewhere on the board
INPUT1.3: LED14.A, R47.2, R51.1, U7.5 (B)
INPUT1.3_MCU: U7.4 (H=B); also elsewhere on the board
INPUT1.4: LED13.A, R46.2, R50.1, U7.3 (A)
INPUT1.4_MCU: U7.2 (G=A); also elsewhere on the board
INPUT2.1: LED12.A, R34.2, R38.1, U6.11 (E)
INPUT2.1_MCU: U6.12 (K=E); also elsewhere on the board
INPUT2.2: LED11.A, R33.2, R37.1, U6.9 (D)
INPUT2.2_MCU: U6.10 (J=D); also elsewhere on the board
INPUT2.3: LED10.A, R32.2, R36.1, U6.5 (B)
INPUT2.3_MCU: U6.4 (H=B); also elsewhere on the board
INPUT2.4: LED9.A, R31.2, R35.1, U6.3 (A)
INPUT2.4_MCU: U6.2 (G=A); also elsewhere on the board
INPUT3.1: C22.1, R40.2, U6.14 (F)
INPUT3.1_MCU: U6.15 (L=F); also elsewhere on the board
unnamed: D5.C, K1.1 (+), R26.2
unnamed: J6.2, R26.1
unnamed: OK1.1 (A), R27.2
unnamed: OK1.3 (A), R28.2
unnamed: OK1.5 (A), R29.2
unnamed: OK1.7 (A), R30.2
unnamed: J5.2, R30.1
unnamed: J5.3, R29.1
unnamed: J5.4, R28.1
unnamed: J5.5, R27.1
unnamed: LED8.C, R54.1
unnamed: LED9.C, R55.1
unnamed: LED10.C, R56.1
unnamed: LED11.C, R57.1
unnamed: K1.4 (S), K1.6
unnamed: OK1.9 (EMIT), R34.1
unnamed: OK1.11 (EMIT), R33.1
unnamed: OK1.13 (EMIT), R32.1
unnamed: OK1.15 (EMIT), R31.1
unnamed: LED12.C, R58.1
unnamed: K1.5 (S), LED7.C, R39.2, R40.1
unnamed: LED7.A, R41.1
unnamed: OK2.1 (A), R42.2
unnamed: J7.5, R42.1
unnamed: LED16.C, R62.1
unnamed: OK2.15 (EMIT), R46.1
unnamed: OK2.3 (A), R43.2
unnamed: J7.4, R43.1
unnamed: OK2.13 (EMIT), R47.1
unnamed: OK2.5 (A), R44.2
unnamed: J7.3, R44.1
unnamed: OK2.11 (EMIT), R48.1
unnamed: LED13.C, R59.1
unnamed: LED14.C, R60.1
unnamed: LED15.C, R61.1
unnamed: OK2.9 (EMIT), R49.1
unnamed: OK2.7 (A), R45.2
unnamed: J7.2, R45.1
OUTPUT3.2_MCU: LED8.A; also elsewhere on the board

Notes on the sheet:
DRIVE INFO


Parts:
D11, D12, D13, D14: 1N4148WS; SOD323-W; MPN 1N4148WS
J10: 22-05-7068-06; 7395-06
LED21, LED22, LED23, LED24: Blue; CHIPLED_0603; MPN OVS-0603
OK4: TLP283-4; MINI-FLAT-16; MPN TCMT4100
R94, R95, R96, R97, R98, R99, R100, R101: 10K; R0603; MPN RC0603FR-0710KL
R102, R103, R104, R105: 1K; R0603; MPN RC0603FR-071KL
R106, R107, R108, R109: 1K5; R0603; MPN RC0603FR-071K5L
R110, R111, R112, R113: 4K7; R0603; MPN RC0603FR-074K7L
R114, R115, R116, R117: 100; R0603; MPN RC0603FR-13100RL
R118, R119, R120, R121: 330; R0603; MPN RC0603FR-07330RL
T12, T13, T14, T15: IRLML5103TRPBF; SOT95P240X112-3N; MPN IRLML5103TRPBF
T16, T17, T18, T19: MMBT2222AL; SOT−23; MPN MMBT2222ALT1G

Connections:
+5V: OK4.10 (COL), OK4.12 (COL), OK4.14 (COL), OK4.16 (COL); also elsewhere on the board
+24V: J10.1, R98.2, R99.2, R100.2, R101.2, T12.2 (S), T13.2 (S), T14.2 (S), T15.2 (S); also elsewhere on the board
GND: D11.A (2), D12.A (2), D13.A (2), D14.A (2), J10.6, OK4.2 (C), OK4.4 (C), OK4.6 (C), OK4.8 (C), R94.1, R95.1, R96.1, R97.1, R106.2, R107.2, R108.2, R109.2, R110.2, R111.2, R112.2, R113.2, T16.2 (E), T17.2 (E), T18.2 (E), T19.2 (E); also elsewhere on the board
unnamed: LED21.A, R102.1, R110.1, R114.1
unnamed: OK4.15 (EMIT), R114.2
unnamed: LED22.A, R103.1, R111.1, R115.1
unnamed: OK4.13 (EMIT), R115.2
unnamed: LED23.A, R104.1, R112.1, R116.1
unnamed: LED24.A, R105.1, R113.1, R117.1
unnamed: OK4.11 (EMIT), R116.2
unnamed: OK4.9 (EMIT), R117.2
unnamed: OK4.1 (A), R118.1
unnamed: OK4.3 (A), R119.1
unnamed: OK4.7 (A), R121.1
unnamed: OK4.5 (A), R120.1
unnamed: LED21.C, R106.1
unnamed: LED22.C, R107.1
unnamed: LED23.C, R108.1
unnamed: LED24.C, R109.1
unnamed: R98.1, T12.1 (G), T16.3 (C)
unnamed: R99.1, T13.1 (G), T17.3 (C)
unnamed: R100.1, T14.1 (G), T18.3 (C)
unnamed: R101.1, T15.1 (G), T19.3 (C)
unnamed: R102.2, T16.1 (B)
unnamed: R103.2, T17.1 (B)
unnamed: R104.2, T18.1 (B)
unnamed: R105.2, T19.1 (B)
OUTPUT1.1: D11.C (1), J10.2, R94.2, T12.3 (D)
OUTPUT1.1_MCU: R118.2; also elsewhere on the board
OUTPUT1.2: D12.C (1), J10.3, R95.2, T13.3 (D)
OUTPUT1.2_MCU: R119.2; also elsewhere on the board
OUTPUT1.3: D13.C (1), J10.4, R96.2, T14.3 (D)
OUTPUT1.3_MCU: R120.2; also elsewhere on the board
OUTPUT1.4: D14.C (1), J10.5, R97.2, T15.3 (D)
OUTPUT1.4_MCU: R121.2; also elsewhere on the board


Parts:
D6, D7, D8, D9, D10: 1N4148WS; SOD323-W; MPN 1N4148WS
J8: 22-05-7068-06; 7395-06
J9: 22-05-7028-02; 7395-02; MPN 22-05-7028
LED17, LED18, LED19, LED20: Blue; CHIPLED_0603; MPN OVS-0603
OK3: TLP283-4; MINI-FLAT-16; MPN TCMT4100
R63, R64, R66, R67, R68, R69, R70, R71, R72, R73: 10K; R0603; MPN RC0603FR-0710KL
R65, R86, R87, R88, R89: 100; R0603; MPN RC0603FR-13100RL
R74, R75, R76, R77: 1K; R0603; MPN RC0603FR-071KL
R78, R79, R80, R81: 1K5; R0603; MPN RC0603FR-071K5L
R82, R83, R84, R85: 4K7; R0603; MPN RC0603FR-074K7L
R90, R91, R92, R93: 330; R0603; MPN RC0603FR-07330RL
T2, T4, T5, T6, T7: IRLML5103TRPBF; SOT95P240X112-3N; MPN IRLML5103TRPBF
T3, T8, T9, T10, T11: MMBT2222AL; SOT−23; MPN MMBT2222ALT1G

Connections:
+5V: OK3.10 (COL), OK3.12 (COL), OK3.14 (COL), OK3.16 (COL); also elsewhere on the board
+24V: J8.1, R64.2, R70.2, R71.2, R72.2, R73.2, T2.2 (S), T4.2 (S), T5.2 (S), T6.2 (S), T7.2 (S); also elsewhere on the board
GND: D6.A (2), D7.A (2), D8.A (2), D9.A (2), D10.A (2), J8.6, J9.2, OK3.2 (C), OK3.4 (C), OK3.6 (C), OK3.8 (C), R63.1, R66.1, R67.1, R68.1, R69.1, R78.2, R79.2, R80.2, R81.2, R82.2, R83.2, R84.2, R85.2, T3.2 (E), T8.2 (E), T9.2 (E), T10.2 (E), T11.2 (E); also elsewhere on the board
MOTOR_VFQ: D6.C (1), J9.1, R63.2, T2.3 (D)
unnamed: R74.2, T8.1 (B)
unnamed: R70.1, T4.1 (G), T8.3 (C)
unnamed: R75.2, T9.1 (B)
unnamed: R71.1, T5.1 (G), T9.3 (C)
unnamed: R76.2, T10.1 (B)
unnamed: R72.1, T6.1 (G), T10.3 (C)
unnamed: R77.2, T11.1 (B)
unnamed: R73.1, T7.1 (G), T11.3 (C)
unnamed: R65.1, T3.1 (B)
unnamed: R64.1, T2.1 (G), T3.3 (C)
unnamed: LED17.A, R74.1, R82.1, R86.1
unnamed: OK3.15 (EMIT), R86.2
unnamed: LED18.A, R75.1, R83.1, R87.1
unnamed: OK3.13 (EMIT), R87.2
unnamed: LED19.A, R76.1, R84.1, R88.1
unnamed: LED20.A, R77.1, R85.1, R89.1
unnamed: OK3.11 (EMIT), R88.2
unnamed: OK3.9 (EMIT), R89.2
unnamed: OK3.1 (A), R90.1
unnamed: OK3.3 (A), R91.1
unnamed: OK3.7 (A), R93.1
unnamed: OK3.5 (A), R92.1
unnamed: LED17.C, R78.1
unnamed: LED18.C, R79.1
unnamed: LED19.C, R80.1
unnamed: LED20.C, R81.1
OUTPUT2.1: D7.C (1), J8.2, R66.2, T4.3 (D)
OUTPUT2.1_MCU: R90.2; also elsewhere on the board
OUTPUT2.2: D8.C (1), J8.3, R67.2, T5.3 (D)
OUTPUT2.2_MCU: R91.2; also elsewhere on the board
OUTPUT2.3: D9.C (1), J8.4, R68.2, T6.3 (D)
OUTPUT2.3_MCU: R92.2; also elsewhere on the board
OUTPUT2.4: D10.C (1), J8.5, R69.2, T7.3 (D)
OUTPUT2.4_MCU: R93.2; also elsewhere on the board
OUTPUT3.2_MCU: R65.2; also elsewhere on the board


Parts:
J11: FTSH-105-01-L-DV-NOPASTE
J21: FTSH-103-01-L-DV-NOPASTE
R122, R123: 0R; R0603; MPN MCMR06X000 PTL
TC1: TC2050-IDC-NL
TC2: TC2030-IDC-NL

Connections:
!ISP_BOOT: J21.2, R122.2, TC2.2
!ISP_RST: J21.6, R123.2, TC2.6
!RESET: J11.10, R123.1, TC1.10; also elsewhere on the board
+3V3: J11.1, J21.1, TC1.1, TC2.1; also elsewhere on the board
BOOT_SELECT_P2_10: R122.1; also elsewhere on the board
GND: J11.3, J11.5, J11.7, J11.9, J21.5, TC1.3, TC1.5, TC1.7, TC1.9, TC2.5; also elsewhere on the board
ISP_RXDO: J21.4, TC2.4; also elsewhere on the board
ISP_TXDO: J21.3, TC2.3; also elsewhere on the board
JTAG_TCK: J11.4, TC1.4; also elsewhere on the board
JTAG_TDI: J11.8, TC1.8; also elsewhere on the board
JTAG_TDO: J11.6, TC1.6; also elsewhere on the board
JTAG_TMS: J11.2, TC1.2; also elsewhere on the board

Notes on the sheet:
JTAG/SWD
Pin 7 is a key
ISP



Board: 4 copper layers, 100.0 x 80.0 mm, 245 parts (31 on the bottom side), 178 nets.

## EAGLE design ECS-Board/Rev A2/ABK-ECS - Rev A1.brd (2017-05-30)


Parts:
C1: 10uF; CT3216; MPN F931A106MAA
C2, C3, C4, C6, C7, C8, C9, C11: 0.1uF; C0603; MPN MC0603B104K160CT
C5, C10: 18pF; C0603; MPN MC0603N180K500CT
CC1: CC-BY-NC-SA
J1: 22-27-2061-06; 6410-06; MPN 22-27-2061
J2: USB-B-S-RA; MPN USB-B-S-RA
J3: 1241050-5; 2.54/2X5; MPN 1241050-5
JP1, JP2, JP3, JP4: FIDUCIAL1X2; FIDUCIAL-1X2
LED1, LED2: Blue; CHIPLED_0603; MPN OVS-0603
R1, R2, R3: 4K7; R0603; MPN MCMR06X4701FTL
R4, R5: 33; R0603; MPN MCMR06X33R0FTL
R6, R11, R12: 1K5; R0603; MPN MCMR06X1501FTL
R7, R10: 10K; R0603; MPN MCMR06X1002FTL
R8, R9: 0R; R0603; MPN MCMR06X000 PTL
SJ1: SOLDERJUMPERNC; SJ_2S
SW1, SW2: B3FS-1015; B3FS; MPN B3FS-1010
T1: EXMACHINA-LOGO-NAME; EXM-LOGO-BASELINE
U1: AT24C512C-SSHM-B; SOIC127P600X175-8N
U2: LPC1768FBD100; SOT407-1; MPN LPC1768FBD100
X1: FC-135; MPN Q13FC13500004
X2: ASE-12; ASE; MPN ASE-12.000MHZ-LC-T
X3: 3000; MPN 3000

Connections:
230V-DETECTION: U2.43 (P1[27]/CLKOUT/*USB_OVRCR/CAP0[1]); also elsewhere on the board
230V_DETECTION_MCU: U2.58 (P0[20]/DTR1/SCL1); also elsewhere on the board
!JTAG_TRST: J3.5, U2.4 (*TRST)
!RESET: R10.1, SW2.3 (1), SW2.4 (1), U2.17 (*RESET)
+3V3: C1.+, C2.1, C3.1, C4.1, C6.1, C7.1, C8.1, C9.1, C11.1, J3.1, R2.2, R3.2, R6.1, R7.2, R10.2, U1.8 (VCC), U2.13 (NC), U2.28 (VDD_2), U2.42 (VDD_3), U2.54 (VDD_4), U2.71 (VDD_5), U2.84 (VDD_6), U2.96 (VDD), X2.1 (TRI), X2.4 (VDD); also elsewhere on the board
BOOT_SELECT_P2_10: R8.1, U2.53 (P2[10]/*EINT0/NMI)
BOOT_SELECT_P2_12: R9.1, U2.51 (P2[12]/*EINT2/I2STX_WS)
BRAKE_CONTROL_MCU: U2.36 (P1[22]/MCOB0/USB_PWRD/MAT1[0]); also elsewhere on the board
CLUTCH_CONTROL_MCU: U2.37 (P1[23]/MCI1/PWM1[4]/MISO0); also elsewhere on the board
DRIVE_STATUS_1_MCU: U2.60 (P0[18]/DCD1/MOSI0/MOSI); also elsewhere on the board
DRIVE_STATUS_2_MCU: U2.59 (P0[19]/DSR1/SDA1); also elsewhere on the board
EEPROM_SCL: R3.1, U1.6 (SCL), U2.24 (P0[28]/SCL0/USB_SCL)
EEPROM_SDA: R2.1, U1.5 (SDA), U2.25 (P0[27]/SDA0/USB_SDA)
EMERGENCY_STOP_MCU: U2.56 (P0[22]/RTS1/TD1); also elsewhere on the board
GND: C1.-, C2.2, C3.2, C4.2, C5.2, C6.2, C7.2, C8.2, C9.2, C10.2, C11.2, J1.1, J2.4 (GND), J3.2, R1.2, R11.2, R12.2, SJ1.1, SW1.1 (2), SW1.2, SW2.1 (2), SW2.2, U1.1 (A0), U1.2 (A1), U1.3 (A2), U1.4 (GND), U2.11 (VSSA), U2.15 (VREFN), U2.31 (VSS_2), U2.41 (VSS_3), U2.55 (VSS_4), U2.72 (VSS_5), U2.83 (VSS_6), U2.97 (VSS), X2.2 (GND), X3.- (VBAT-); also elsewhere on the board
ISP_RXDO: J1.4, J3.3, U2.99 (P0[3]/RXD0/AD0[6])
ISP_TXDO: J1.5, J3.4, U2.98 (P0[2]/TXD0/AD0[7])
JTAG_TCK: J3.8, U2.5 (TCK/SWDCLK)
JTAG_TDI: J3.7, U2.2 (TDI)
JTAG_TDO: J3.9, U2.1 (TDO/SWO)
JTAG_TMS: J3.10, U2.3 (TMS/SWDIO)
LED_DEBUG: LED1.A, U2.35 (P1[21]/*MCABORT/PWM1[3]/SSEL0)
LIMIT_SWITCH_MCU: U2.57 (P0[21]/RI1/RD1); also elsewhere on the board
L_VALIDATION_MCU: U2.38 (P1[24]/MCI2/PWM1[5]/MOSI0); also elsewhere on the board
MOTOR_CONTROL_MCU: U2.40 (P1[26]/MCOB1/PWM1[6]/CAP0[0]); also elsewhere on the board
unnamed: J2.3 (DATA+), R5.1, R6.2
unnamed: J2.2 (DATA-), R4.1
unnamed: LED2.C, R12.1
unnamed: R7.1, R8.2, R9.2, SW1.3 (1), SW1.4 (1)
unnamed: R1.1, U1.7 (WP)
unnamed: LED1.C, R11.1
unnamed: J2.SHL, J2.SHL1 (SHL), SJ1.2
RTCX1: C5.1, U2.16 (RTCX1), X1.1
RTCX2: C10.1, U2.18 (RTCX2), X1.2
R_VALIDATION_MCU: U2.39 (P1[25]/MCOA1/MAT1[1]); also elsewhere on the board
USB_D_N: R4.2, U2.30 (P0[30]/USB_D?)
USB_D_P: R5.2, U2.29 (P0[29]/USB_D+)
USB_UP_LED: LED2.A, U2.32 (P1[18]/USB_UP_LED/PWM1[1]/CAP1[0])
USB_V_BUS: J2.1 (VUSB), U2.21 (P1[30]/VBUS/AD0[4])
VBAT+: U2.19 (VBAT), X3.+1 (VBAT+), X3.+2 (VBAT+)
VDDA: U2.10 (VDDA)
VREFP: U2.12 (VREFP)
XTAL1: U2.22 (XTAL1), X2.3 (OUT)

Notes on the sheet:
USB
JTAG
ISP
BOOT SELECT
LED ON BOARD
RESET
EEPROM
RTC
12MHz CLOCK
DECOUPLING

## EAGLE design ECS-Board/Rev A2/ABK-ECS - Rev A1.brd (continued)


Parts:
C12, C13, C16, C17: 2.2uF; C0603; MPN GRT188R61H225KE13D
C14, C15: 1000pF; C0603; MPN MC0603B102K500CT
C18, C19: 22uF; C0805; MPN MCMT21N220F250CT
D1, D2: MBRS140; DO-214AA; MPN MBRS140T3G
D3: STPS3L40UF; SMB
F1: FUSE3557L; 3557-LITTLE; MPN 3557
J4: MSTBA2
L1: 15uH; WE-PD2_5848/5820; MPN 744774115
L2: 10uH; WE-PD2_5848/5820; MPN 74477410
LED3: Red; CHIPLED_0603; MPN OVS-0603
LED4: Blue; CHIPLED_0603; MPN OVS-0603
LED5, LED6: Blue; CHIP-LED0603; MPN OVS-0603
MP1, MP2, MP3, MP4: MOUNT-PAD3,0; P3,0
R13, R14, R19: 31K6; R0603; MPN MCMR06X3162FTL
R15, R16: 4K7; R0603; MPN MCMR06X4701FTL
R17: 52K3; R0603; MPN MC0063W0603152K3
R18, R20: 10K; R0603; MPN MCMR06X1002FTL
R21, R22: 1K5; R0603; MPN MCMR06X1501FTL
SJ2, SJ3, SJ4, SJ5: SOLDERJUMPERNC; SJ_2S
U3, U4: LT3686HDDPBF; DFN300X300X80-11N

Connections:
1: MP1.1, SJ2.2
2: MP2.1, SJ3.2
3: MP3.1, SJ4.2
4: MP4.1, SJ5.2
+3V3: C19.1, L2.2, R19.2, R22.2, U4.2 (BD); also elsewhere on the board
+5V: C18.1, L1.2, R17.2, R21.2, U3.2 (BD); also elsewhere on the board
+24V: C12.1, C13.1, D3.C, F1.3 (2), F1.4 (2), R15.2, R16.2, U3.1 (VIN), U3.6 (EN/UVLO), U4.1 (VIN), U4.6 (EN/UVLO); also elsewhere on the board
GND: C12.2, C13.2, C14.2, C15.2, C18.2, C19.2, D3.A, J4.2, LED4.C, LED5.C, LED6.C, R13.1, R14.1, R18.1, R20.1, SJ2.1, SJ3.1, SJ4.1, SJ5.1, U3.7 (MODE), U3.11 (EP), U4.7 (MODE), U4.11 (EP); also elsewhere on the board
unnamed: R13.2, U3.5 (RT)
unnamed: C14.1, U3.4 (SS)
unnamed: R14.2, U4.5 (RT)
unnamed: C15.1, U4.4 (SS)
unnamed: R17.1, R18.2, U3.3 (FB)
unnamed: C16.1, U3.8 (BOOST)
unnamed: C16.2, D1.C, L1.1, U3.10 (SW)
unnamed: D1.A, U3.9 (DA)
unnamed: R19.1, R20.2, U4.3 (FB)
unnamed: C17.1, U4.8 (BOOST)
unnamed: C17.2, D2.C, L2.1, U4.10 (SW)
unnamed: D2.A, U4.9 (DA)
unnamed: LED4.A, R16.1
unnamed: LED3.C, R15.1
unnamed: LED6.A, R22.1
unnamed: LED5.A, R21.1
VIN: F1.1, F1.2 (1), J4.1, LED3.A

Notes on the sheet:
+5V
+3V3
+24V


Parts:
C20, C21: 0.1uF; C0603; MPN MC0603B104K160CT
D4: STPS3L40UF; SMB
J5: 22-05-7068-06; 7395-06; MPN 22-05-7068
J6: 22-05-7028-02; 7395-02; MPN 22-05-7028
K1: G6K-2G-Y; MPN G6K-2G-Y 24DC
LED7: Red; CHIPLED_0603; MPN OVS-0603
LED8, LED9, LED10, LED11, LED12: Blue; CHIPLED_0603; MPN OVS-0603
OK1: TLP283-4; MINI-FLAT-16; MPN TCMT4100
R23, R38: 100; R0603; MPN MCMR06X1000FTL
R24, R25, R26, R27, R28, R29, R30, R31: 1K; R0603; MPN MCMR06X1001FTL
R32, R33, R34, R35, R36: 4K7; R0603; MPN MCMR06X4701FTL
R37, R39, R40, R41, R42, R43: 1K5; R0603; MPN MCMR06X1501FTL
U5: CD4050BD; SOIC127P600X175-16N

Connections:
230V-DETECTION: C20.1, R38.2; also elsewhere on the board
230V_DETECTION: U5.11 (E)
230V_DETECTION_MCU: U5.12 (K=E); also elsewhere on the board
+3V3: C21.1, U5.1 (VCC); also elsewhere on the board
+5V: OK1.10 (COL), OK1.12 (COL), OK1.14 (COL), OK1.16 (COL), R36.1, R39.2; also elsewhere on the board
+24V: J5.1, J6.1; also elsewhere on the board
DRIVE_STATUS_1: LED11.A, R30.2, R34.1, U5.7 (C)
DRIVE_STATUS_1_MCU: U5.6 (I=C); also elsewhere on the board
DRIVE_STATUS_2: LED12.A, R31.2, R35.1, U5.9 (D)
DRIVE_STATUS_2_MCU: U5.10 (J=D); also elsewhere on the board
EMERGENCY_STOP: LED9.A, R28.2, R32.1, U5.3 (A)
EMERGENCY_STOP_MCU: U5.2 (G=A); also elsewhere on the board
GND: C20.2, C21.2, D4.A, J5.6, K1.3, K1.8 (-), OK1.2 (C), OK1.4 (C), OK1.6 (C), OK1.8 (C), R32.2, R33.2, R34.2, R35.2, R37.2, R40.2, R41.2, R42.2, R43.2, U5.8 (VSS); also elsewhere on the board
LIMIT_SWITCH: LED10.A, R29.2, R33.1, U5.5 (B)
LIMIT_SWITCH_MCU: U5.4 (H=B); also elsewhere on the board
MOTOR_CONTROL_MCU: LED8.A; also elsewhere on the board
unnamed: D4.C, K1.1 (+), R23.2
unnamed: J6.2, R23.1
unnamed: OK1.1 (A), R24.2
unnamed: OK1.3 (A), R25.2
unnamed: OK1.5 (A), R26.2
unnamed: OK1.7 (A), R27.2
unnamed: J5.2, R27.1
unnamed: J5.3, R26.1
unnamed: J5.4, R25.1
unnamed: J5.5, R24.1
unnamed: LED8.C, R37.1
unnamed: LED9.C, R40.1
unnamed: LED10.C, R41.1
unnamed: LED11.C, R42.1
unnamed: K1.4 (S), K1.6
unnamed: OK1.9 (EMIT), R31.1
unnamed: OK1.11 (EMIT), R30.1
unnamed: OK1.13 (EMIT), R29.1
unnamed: OK1.15 (EMIT), R28.1
unnamed: LED12.C, R43.1
unnamed: K1.5 (S), LED7.C, R36.2, R38.1
unnamed: LED7.A, R39.1

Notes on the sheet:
DRIVE INFO


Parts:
D5, D6, D7, D8, D9: 1N4148WS; SOD323-W
J7: 22-05-7068-06; 7395-06; MPN 22-05-7068
J8: 22-05-7028-02; 7395-02; MPN 22-05-7028
LED13, LED14, LED15, LED16: Blue; CHIPLED_0603; MPN OVS-0603
OK2: TLP283-4; MINI-FLAT-16; MPN TCMT4100
R44, R47, R49, R51, R53: 330; R0603; MPN MCMR06X4701FTL
R45, R48, R50, R52, R54: 10K; R0603; MPN MCMR06X4701FTL
R46, R55, R56, R57, R58: 100; R0603; MPN MCMR06X1000FTL
R59, R60, R61, R62: 1K5; R0603; MPN MCMR06X1501FTL
R63, R64, R65, R66: 4K7; R0603; MPN MCMR06X4701FTL
R67, R68, R69, R70: 1K; R0603; MPN MCMR06X1001FTL
R71, R72, R73, R74: 330; R0603; MPN MCMR06X3300FTL
T2, T5, T7, T9, T11: IRLML5103TRPBF; SOT95P240X112-3N
T3, T4, T6, T8, T10: MMBT2222AL; SOT−23

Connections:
+5V: OK2.10 (COL), OK2.12 (COL), OK2.14 (COL), OK2.16 (COL); also elsewhere on the board
+24V: J7.1, R44.2, R47.2, R49.2, R51.2, R53.2, T2.2 (S), T5.2 (S), T7.2 (S), T9.2 (S), T11.2 (S); also elsewhere on the board
BRAKE_CONTROL: D8.C (1), J7.5, R54.2, T9.3 (D)
BRAKE_CONTROL_MCU: R74.2; also elsewhere on the board
CLUTCH_CONTROL: D7.C (1), J7.4, R52.2, T7.3 (D)
CLUTCH_CONTROL_MCU: R73.2; also elsewhere on the board
GND: D5.A (2), D6.A (2), D7.A (2), D8.A (2), D9.A (2), J7.6, J8.2, OK2.2 (C), OK2.4 (C), OK2.6 (C), OK2.8 (C), R45.1, R48.1, R50.1, R52.1, R54.1, R59.2, R60.2, R61.2, R62.2, R63.2, R64.2, R65.2, R66.2, T3.2 (E), T4.2 (E), T6.2 (E), T8.2 (E), T10.2 (E); also elsewhere on the board
L_VALIDATION: D6.C (1), J7.3, R48.2, T5.3 (D)
L_VALIDATION_MCU: R72.2; also elsewhere on the board
MOTOR_CONTROL_MCU: R46.2; also elsewhere on the board
MOTOR_CTR: D5.C (1), J7.2, R50.2, T2.3 (D)
unnamed: R55.2, T3.1 (B)
unnamed: R51.1, T2.1 (G), T3.3 (C)
unnamed: R56.2, T4.1 (B)
unnamed: R47.1, T4.3 (C), T5.1 (G)
unnamed: R57.2, T6.1 (B)
unnamed: R49.1, T6.3 (C), T7.1 (G)
unnamed: R58.2, T8.1 (B)
unnamed: R53.1, T8.3 (C), T9.1 (G)
unnamed: R46.1, T10.1 (B)
unnamed: R44.1, T10.3 (C), T11.1 (G)
unnamed: D9.C (1), J8.1, R45.2, T11.3 (D)
unnamed: LED13.A, R55.1, R63.1, R67.1
unnamed: OK2.15 (EMIT), R67.2
unnamed: LED14.A, R56.1, R64.1, R68.1
unnamed: OK2.13 (EMIT), R68.2
unnamed: LED15.A, R57.1, R65.1, R69.1
unnamed: LED16.A, R58.1, R66.1, R70.1
unnamed: OK2.11 (EMIT), R69.2
unnamed: OK2.9 (EMIT), R70.2
unnamed: OK2.1 (A), R71.1
unnamed: OK2.3 (A), R72.1
unnamed: OK2.7 (A), R74.1
unnamed: OK2.5 (A), R73.1
unnamed: LED13.C, R59.1
unnamed: LED14.C, R60.1
unnamed: LED15.C, R61.1
unnamed: LED16.C, R62.1
R_VALIDATION_MCU: R71.2; also elsewhere on the board



Board: 4 copper layers, 80.0 x 80.0 mm, 169 parts (23 on the bottom side), 121 nets.

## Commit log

2017-02-28 Clean repos
    [ADC_PWM_Board - Rev A1.brd, ADC_PWM_Board - Rev A1.sch, ADC_PWM_Board - Rev A2.brd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]
2017-02-28 Rename folder
    [ABK-ECS - Rev A1.brd, ABK-ECS - Rev A1.sch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]
2017-03-07 Update MPN and generate part list
    [ABK-ECS - Rev A1 - Board_Part_List.xlsx, ABK-ECS - Rev A1.brd, ABK-ECS - Rev A1.sch]
2017-05-30 Update MDP folder
    [ABK-ECS - Rev A1 - Board_Part_List.xlsx]
2017-05-30 Modify ECS board with pull-down output
    [ABK-ECS - Rev A1.brd, ABK-ECS - Rev A1.sch]
2017-07-18 Add rev A2 and modify board
    [ABK-ECS - Rev A2.brd, ABK-ECS - Rev A2.sch]
2017-08-31 Add input and output to the board and LDO 5V to 3.3V for FTDI connector
    [ABK-ECS - Rev A2.brd, ABK-ECS - Rev A2.sch]
2017-09-05 Rotate board 90 degres
    [ABK-ECS - Rev A2.brd]
2017-09-05 Add 24V and Vin poly for the fuse
    [ABK-ECS - Rev A2.brd]
2017-09-05 Add pullup resistor on AT24C WP Separate +5V from ISP connector and the +5V general and add a diode Change +5V--->+3V3 conversion methode on input Wired OK2D
    [ABK-ECS - Rev A2.brd, ABK-ECS - Rev A2.sch]
2017-09-06 Resize and place all name and value of the component of the board
    [ABK-ECS - Rev A2.brd]
2017-09-07 Final modifications before production version:
    * Rename inputs and outputs to generic names
    * Add silkscreen labels
    * Move components for better layout in output block
    [ABK-ECS - Rev A2.brd, ABK-ECS - Rev A2.sch]
2017-09-07 Update componenets from eagle-resources
    [ABK-ECS - Rev A2.brd, ABK-ECS - Rev A2.sch]
2017-09-07 Update from eagle-resources
    * Modified footprints
    [ABK-ECS - Rev A2.brd, ABK-ECS - Rev A2.sch]
2017-09-08 Minor route upgrade
    [ABK-ECS - Rev A2.brd]
2017-09-13 Generate Gerber and MDP files
    [ABK-ECS - Rev A2 - BOM.xlsx, ABK-ECS - Rev A2.brd, ABK-ECS - Rev A2.sch]
2017-10-10 Replace output resistance and fuse LED
    [ABK-ECS - Rev A2.brd, ABK-ECS - Rev A2.sch]
2017-11-13 Rev A2-a : Change pullup resistors of the outputs to 10k, Inverse 100 and 1k resistors after the opto
    [ABK-ECS - Rev A2.sch]
2017-11-14 Add Rev A3 files
    - Add new connectors for ICSP/JTAG
    - Improve auto ISP
    [ABK-ECS - Rev A3.brd, ABK-ECS - Rev A3.sch]
2017-11-14 Propagate changes from Rev A2a to Rev A3
    [ABK-ECS - Rev A3.brd, ABK-ECS - Rev A3.sch]
2017-11-28 Convert text to vector and update silkscreen
    [ABK-ECS - Rev A3.brd]
2017-11-29 Create rev B1 : - Change output pull-down to 1K with 1206 footprint - Add USB Connect interface and add V Bus projection
    [ABK-ECS - Rev B1.brd, ABK-ECS - Rev B1.sch]
2017-11-30 Place and route ethernet interface
    [ABK-ECS - Rev B1.brd, ABK-ECS - Rev B1.sch]
2017-11-30 Route JTAG, ISCP and LED On board
    [ABK-ECS - Rev B1.brd, ABK-ECS - Rev B1.sch]
2017-11-30 Route ethernet LED and Reset signal
    [ABK-ECS - Rev B1.brd, ABK-ECS - Rev B1.sch]
2017-12-04 Finish to route the board
    [ABK-ECS - Rev B1.brd]
2017-12-05 Add 0R to the USB Pull-up
    [ABK-ECS - Rev B1.brd, ABK-ECS - Rev B1.sch]
2017-12-06 Routing improvement
    [ABK-ECS - Rev B1.brd, ABK-ECS - Rev B1.sch]
2017-12-07 Resize board 100x100mm
    [ABK-ECS - Rev B1.brd, ABK-ECS - Rev B1.sch]
2017-12-07 Remape I/O and add UART-I2C-2ADC-Encoder mcu pin
    [ABK-ECS - Rev B1.brd, ABK-ECS - Rev B1.sch]
2017-12-08 dd pull up and pull down resistor to I2C and UART and place every compoment
    [ABK-ECS - Rev B1.brd, ABK-ECS - Rev B1.sch]
2017-12-08 Route USB LED, re-place IO leds
    [ABK-ECS - Rev B1.brd, ABK-ECS - Rev B1.sch]
2017-12-11 Route Input
    [ABK-ECS - Rev B1.brd]
2017-12-11 Route Outputs and Encoder Inputs
    [ABK-ECS - Rev B1.brd]
2017-12-11 Route UART and I2C
    [ABK-ECS - Rev B1.brd, ABK-ECS - Rev B1.sch]
2017-12-11 Route ADC
    [ABK-ECS - Rev B1.brd, ABK-ECS - Rev B1.sch]
2017-12-11 Route the output
    [ABK-ECS - Rev B1.brd]
2017-12-11 Re-Map MCU output signal
    [ABK-ECS - Rev B1.brd, ABK-ECS - Rev B1.sch]
2017-12-11 Move RTC battery holder and route VBAT, Boot signals and Leds signals
    [ABK-ECS - Rev B1.brd]
2017-12-11 Route Reset and all airwire
    [ABK-ECS - Rev B1.brd, ABK-ECS - Rev B1.sch]
2017-12-13 Improte routing and add Silkscreen
    [ABK-ECS - Rev B1.brd, ABK-ECS - Rev B1.sch]
2017-12-20 Final changes before manufacturing:
    - Update silkscreen:
    * Place labels for each pin
    * Update USB silkscreen
    * Update RJ45 silkscreen
    * Update +24V socket silkscreen
    * Update battery holder silscreen
    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
    [ABK-ECS - Rev B1.brd, ABK-ECS - Rev B1.sch]
2017-12-20 Add and route decoupling power for VADC
    [ABK-ECS - Rev B1.brd, ABK-ECS - Rev B1.sch]
2018-01-09 Generated MDP files
    [ABK-ECS - Rev B1.brd, ABK-ECS - Rev B1.sch]

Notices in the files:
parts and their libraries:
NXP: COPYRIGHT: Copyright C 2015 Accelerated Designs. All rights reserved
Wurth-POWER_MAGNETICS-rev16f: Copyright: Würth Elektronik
